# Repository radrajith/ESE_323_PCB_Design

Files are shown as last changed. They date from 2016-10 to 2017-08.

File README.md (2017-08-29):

## Improved Ammeter Design Project Page

***

### Description

ESE 323 is a Modern Circuit Board Design and Prototyping class taught by Prof Westerfeld. During this class, we are designing circuits using eagle cad software and also designing and building 3d models using Autocad. An Improved current meter will be designed and built for the final project. This current meter design is intended to minimize the effects of burden voltage that is present in the multimeters used in the lab and other facilites. 

***

### design and spec

Design drawing(initial version)
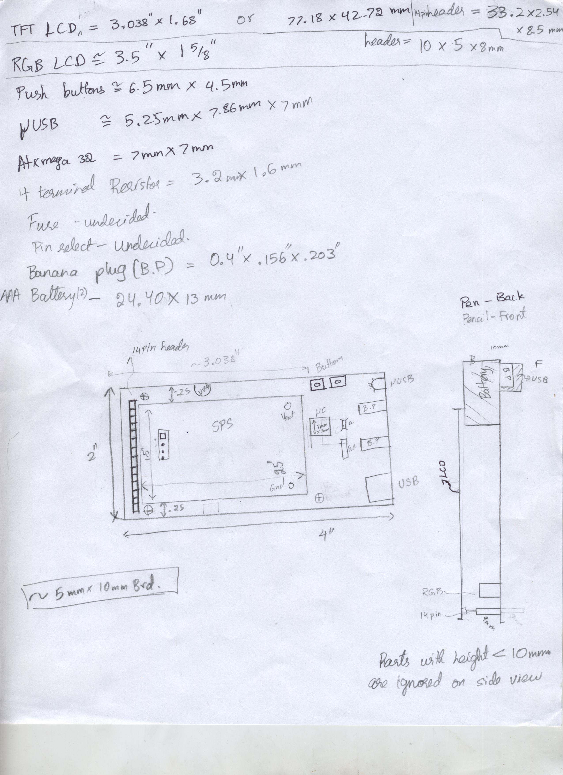
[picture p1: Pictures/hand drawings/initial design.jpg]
Initial design


The current meter will be designed to read up to 7A. The maximum current rating is set to be 8A (the fuse will break at this point) and will only be able to read positive DC currents. The circuit can be powered by a battery with a voltage ranging from 2.5 to 5v, in this design 2-AAA battery is used as a power source i.e 3V source. The Analog current measurement will be sampled at 12kSPS (based on atxmega32 specs), and the digital output will have 12-bit resolution. 

The current is read by measuring the voltage that flows across a shunt resistor. The shunt resistor is specially chosen to have current sense technology, where the resistors packs have 4 terminals, 2 for current flow, and 2 for current measurement. The voltage across the resistor is read using the Atxmega micro controller's built in Analog to digital converter(ADC). 
 
Since the class is about coming with our own design and specs, I decided to add some extra feature to make this project cooler. A LCD touch screen is added to display the current readings such as peak, instantaneous, rms etc. In addition the LCD will be used to graph continuous data assuming I will finish the programming on time. Since the programming had to go through a number of revisions, a PDI communication will be implemented to modify the code as intended. In addition to serving as a normal current meter, A USB port will be added to monitor the current usage of mobile phone or other devices charged using USB. A micro usb port will be used as the input and USB as output. 

***

### Ideal World Scenario

The Atxmega32 comes equipped with amplifier of various ranges like 1/2x, 1x,2x,8x...64x. And since the internal bandgap reference voltage is used, the reference voltage will be a constant 1V. This means by using a 0.01 ohm resistor and using a amplification of 1/2x, the max current that can be read using the meter will be 200A. 

*** 

### Design: Considerations and practical limitations

* **Why 7A current limit?**
The 4 terminal  resistors are available for different power rating for 0.01 ohms. For instance, if 5W rated resistor was implemented the maximum current it can handle would be 22.36A (sqrt(5/0.01)). However, larger current required the trace width of the PCB to be more than 0.4 inch/1cm width. Since the board size use for this design is 5cmx5cm, having a trace width of 1cm will require larger board which adds to the cost. In addition the resistor land pattern is quite small that having a trace causes overlaps. A 4mm/.16in trace is implemented in this design, which corresponds to 7-8A according to graph. 

current vs width
source: https://wiki.xtronics.com/index.php/Wire-Gauge_Ampacity

* **Using 0.5mohm vs 1mohm 4 terminal resistor?**

Although the cost and sizing of both parts remain the same, for this design 0.01 mohm resistor is used. An ammeter ideally has 0 internal resistance, thus for a current meter design its desired to pick a shunt resistor with lowest resistance. However, I had to go with 1mOhm resistor due to the fact that at practical usage, there is resistance contributed from the solder and traces. This will cause error in measurement. In addition, the limitation also arises from the availability of amplifiers in the MCU. With a step voltage of 0.000244, using 0.5 mOhm resistor will reduce the minimum current that can be measured and also accuracy. Thus to have a smaller minimum current, better accuracy and less error a higher valued resistor was implemented.

* **Implementation of two display ports
In addition to a 14 pin header, a 4 pin header is added for i2c communication to provide an alternative display source in case the touch screen display malfunctions and the if the coding cannot be finished on time. 

***

### **Schematic View**

Page one - schematic of the whole circuit with headers, jtag, processor, shunt resistor, fuse, banana plug, usb switches connected and wired according to the requirement.

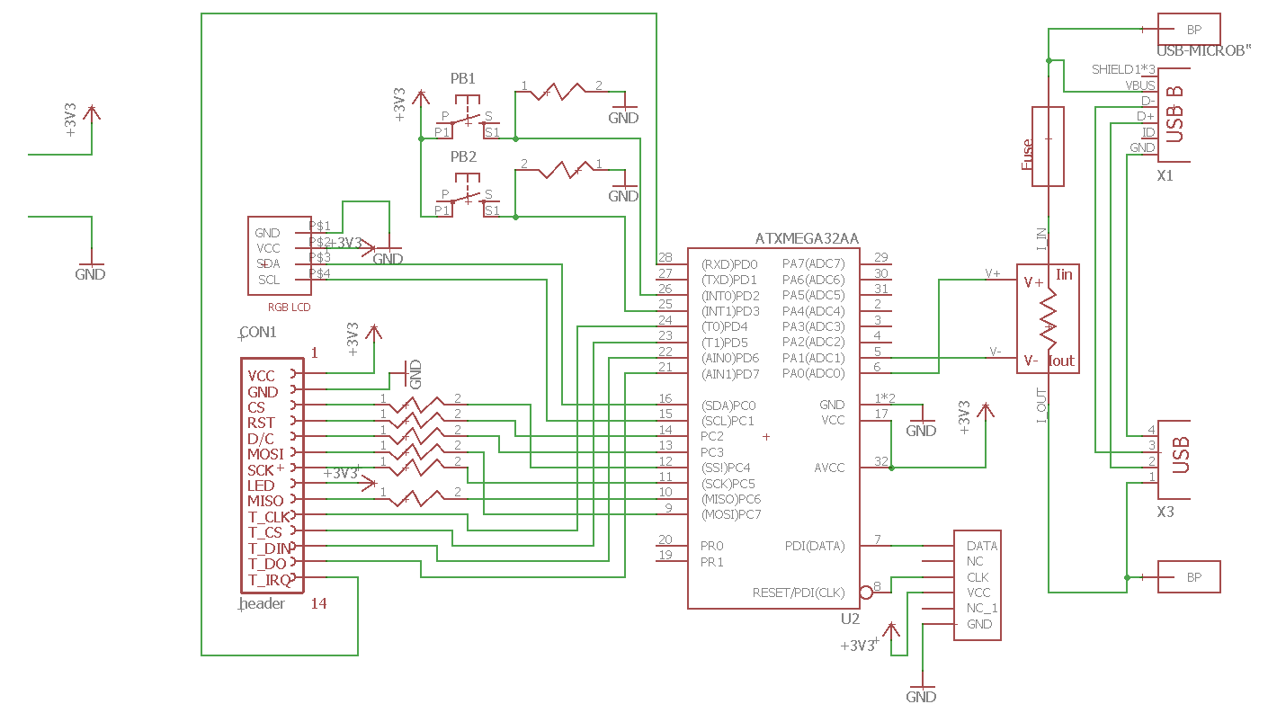
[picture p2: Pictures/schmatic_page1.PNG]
Page one


Page two - Schematic drawing of the switching power supply obtained from texas instruments 

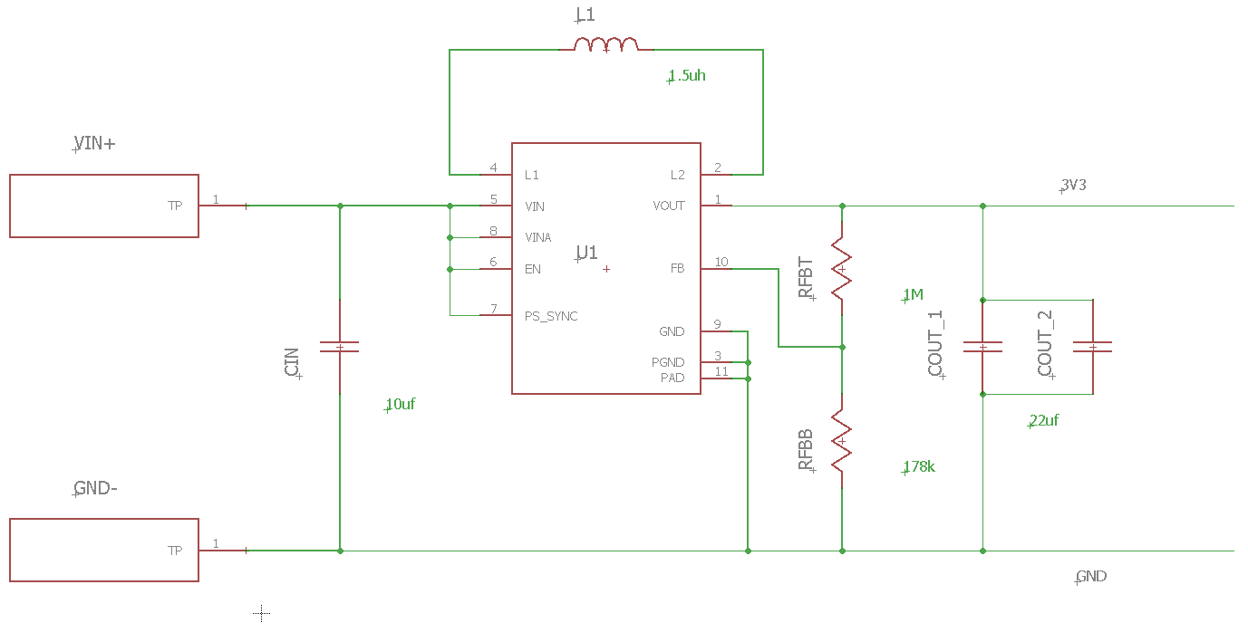
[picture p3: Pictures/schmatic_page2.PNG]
page two


### **Board view**

Board layout
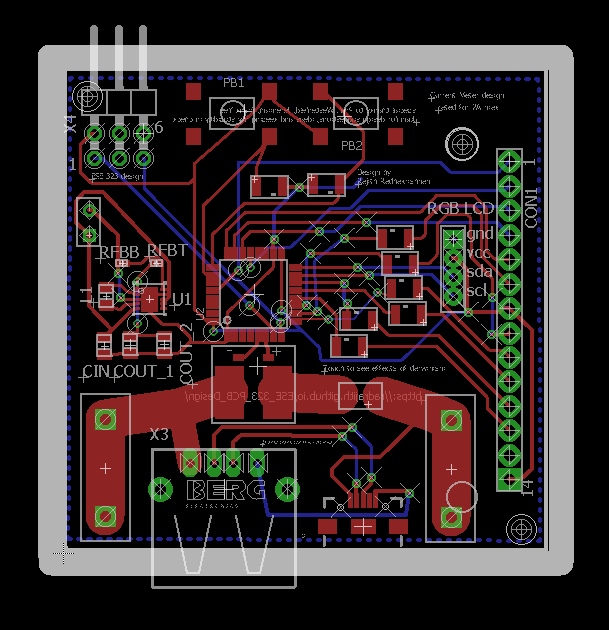
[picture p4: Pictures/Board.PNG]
board


***

### Design rule check and Cam Job

After routing all the parts on the board layout, design rule check had to be used to confirm weather the board meets the requirements. Since Fusion pcb services was planned to be used, the design rule check from seeedstudio was downloaded([DRU link](https://github.com/radrajith/ESE_323_PCB_Design/blob/master/SeeedStudio_2layer_DRU_no_angle_20140221.dru))
After running the design rule check, couple of errors was shown. These errors were mainly becuasue of routing wires or vias close to each other. These errors were fixed and the DRC was repeated until there were no errors. 
 
For the cam job, the cam file provided by the seeedstudio does not include one of the files required by the gerbemerge software, it requires a slight modification. The cam file provided from [seeedstudio website](http://support.seeedstudio.com/knowledgebase/articles/422482-fusion-pcb-order-submission-guidelines) does not generate ".bor" file required for the gerbmerge software. Download the modified cam file from [here](https://github.com/radrajith/ESE_323_PCB_Design/raw/master/Seeed_Gerber_Generater_2-layer.cam). If you choose to modify the cam file provided by seeedstudio by yourself, the instructions are provided after the procedure to create cam files

#### procedure to create cam files

- In order to do the cam process, on the board window click file > cam processor.
- This will open up a window, Click file > open > job

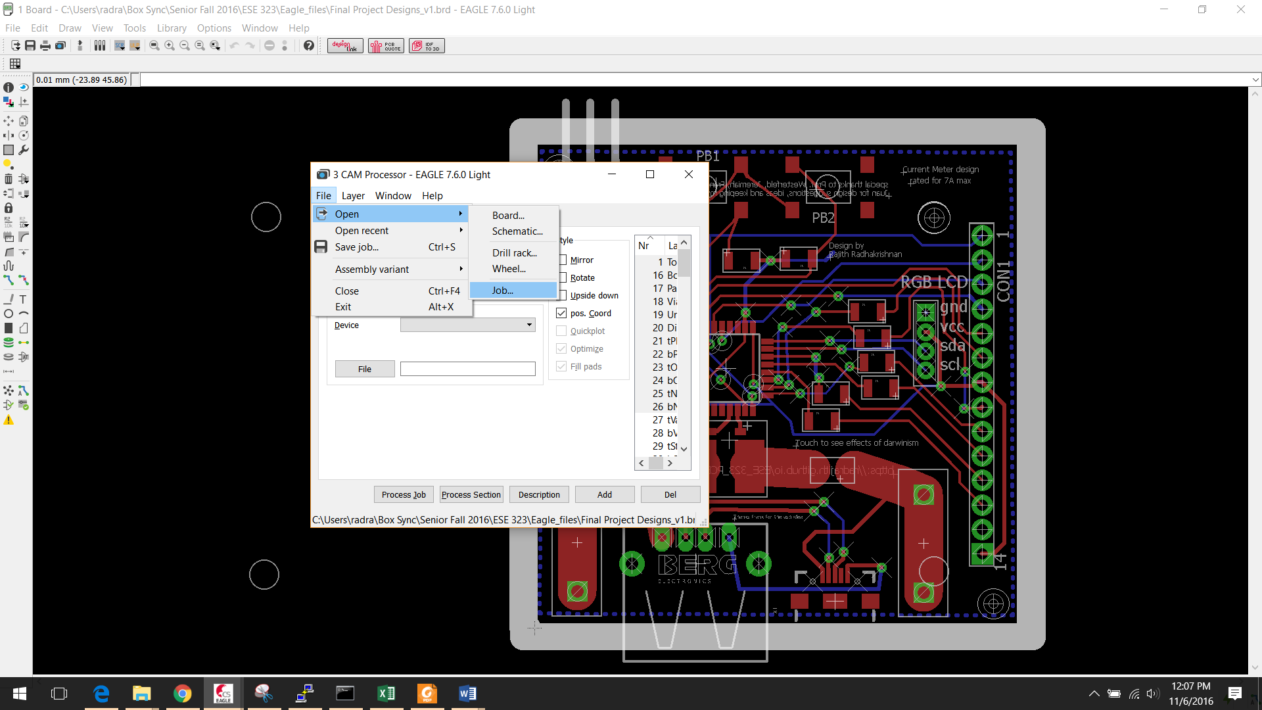
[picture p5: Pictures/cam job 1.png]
cam_1


- Locate you cam file downloaded provided in the above paragraph. 

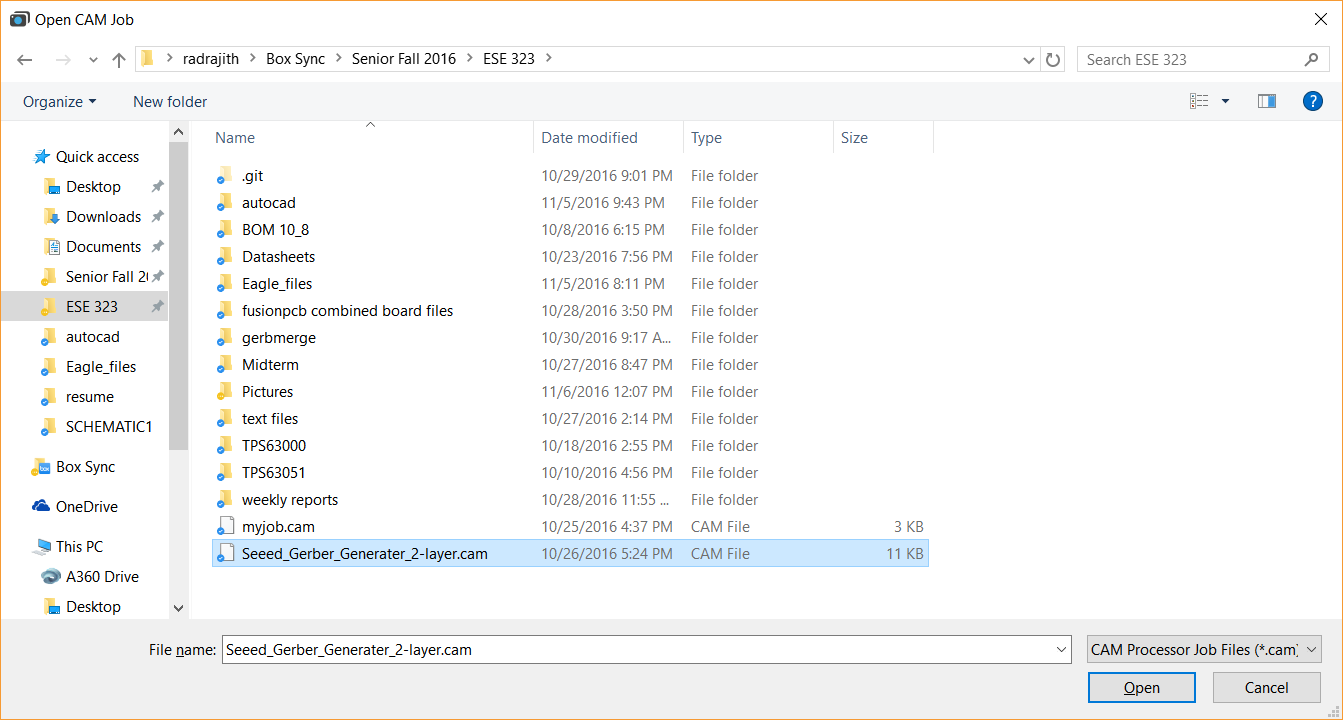
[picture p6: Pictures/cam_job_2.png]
cam_2


- Click process job. This will create all the files necessary to perform gerbmerge operation(described below) or upload to the pcb printing service. 

##### Modify the cam file by yourself(skip this if you used the cam file provided by me)

- After opening the cam processor with the file downloaded from the seeedstudio [link](http://support.seeedstudio.com/knowledgebase/articles/422482-fusion-pcb-order-submission-guidelines), click "add" button

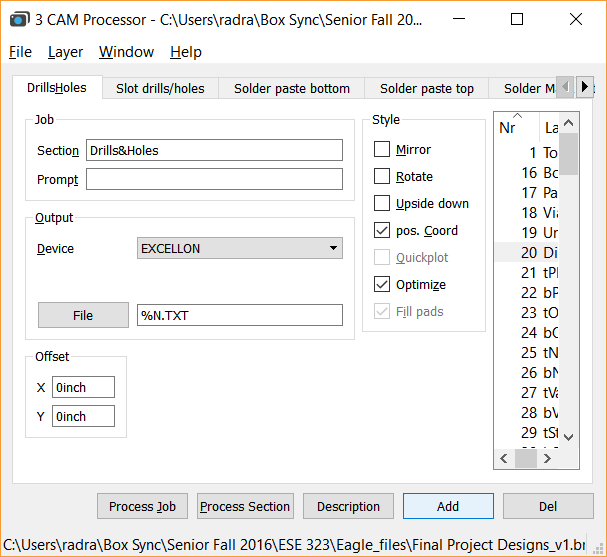
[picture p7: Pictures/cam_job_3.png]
cam_3


this will create a duplicate window of drill&holes. 
- Modify the "Section" from 'drill&holes' to 'board outline'
- Change "device" from 'excellon' to 'GERBER_RS274X' in the dropdown menu
- Change the "file" extension from '.txt' to '.bor'
- On the right side list of layer, make sure only '20 dimension' is selected, scroll all the way to the bottom to make sure. 

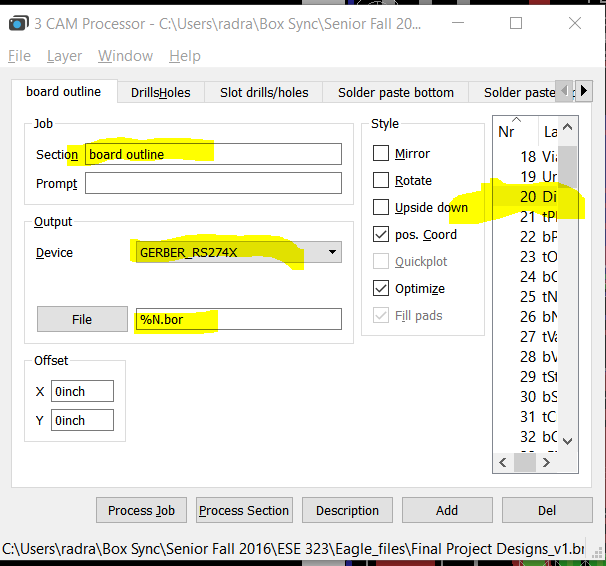
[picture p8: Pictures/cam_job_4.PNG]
cam_4


- Click process job. This will create all the files necessary to perform gerbmerge operation(described below) or upload to the pcb printing service. 

***

### Printed Circuit Board(merged)

With primary goal of reducing the cost, group of 10 students joined and decided to combine the PCBs and place the order. Seeedstudio's PCB printint service was used. The 5 Boards were ordered(minimum quantity), for a 260mmX160mm sized board at the cost of $73.65.  

Front view

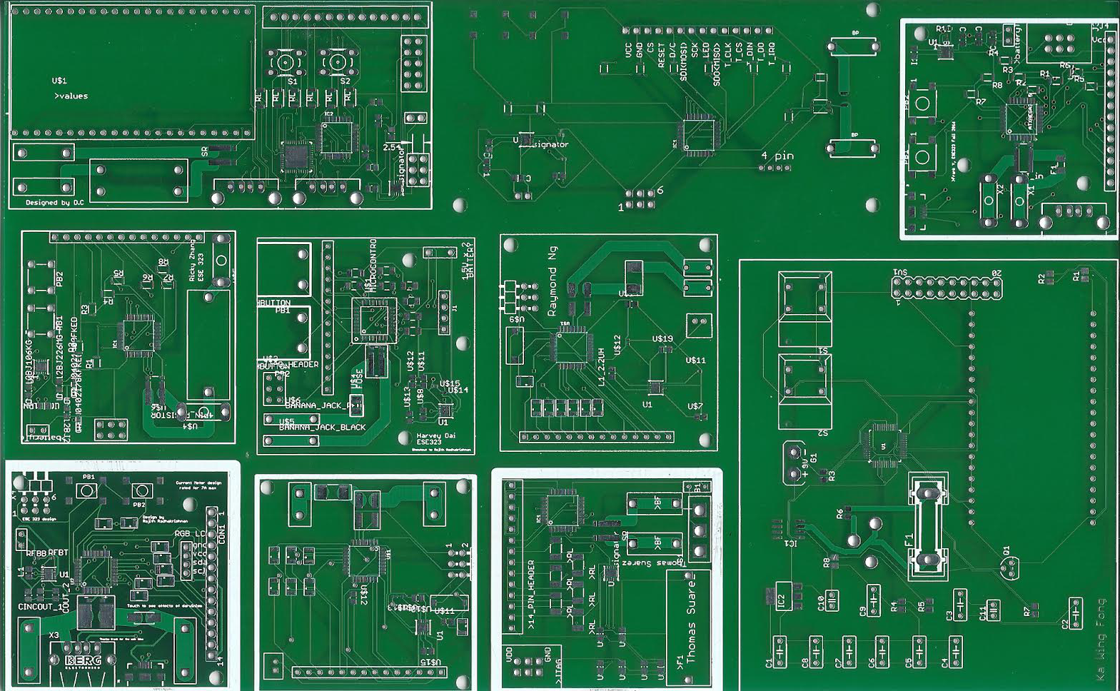
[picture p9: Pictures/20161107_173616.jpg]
front


Rear view
 
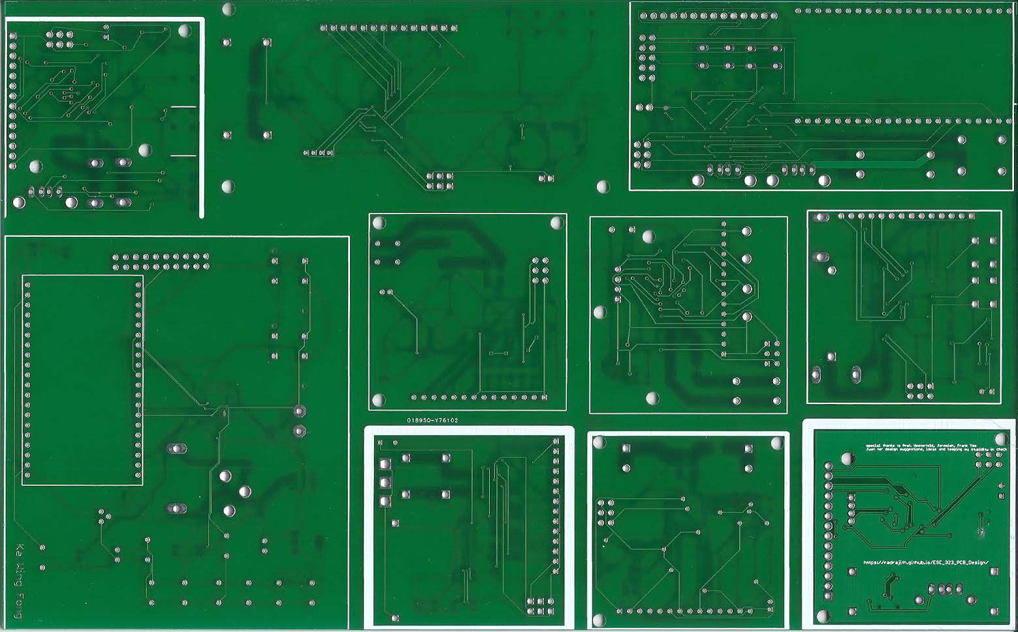
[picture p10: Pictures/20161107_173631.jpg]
back


After obtaining the boards, we carefully analyzed for any errors that were made during the manufacturing process. Luckily all of the board were printed as designed in the eagle.

***

### Gerbmerge

#### **[For information about gerbemerge and tutorial click here](https://radrajith.github.io/gerbmerge/)**

Thank a lot Frank Yee for helping me make the gerbmerge tutorial and actively contributing to it. 

***

### Autodesk Inventor Case design pics 

For the case, there were two designs printed. Althougth the first design fit able to encapsulate the board perfectly, there was some inconveniences when changing the battery and assembling the top cover. [First design pics](https://github.com/radrajith/ESE_323_PCB_Design/blob/gh-pages/initialCAD.md)
The second design was planned to include a slide cover for ease of access to the battery. While programming the LCD screen it was clear that batteries had to be changed often. So accessing battery without disturbing anyother assembly was critical. After designing the first design, it was hard to keep the top case in place, for this reason a door type mechanism was devised and implemented. A stylus slot was added to store when not used, however due to over precision the slot sizing was little small. In addition a hole was added to access Jtag without having to remove the entire board out of the case. Similar to the first design the button press and lever was added to access button present beneath the LCD screen. 

* Circuit Board

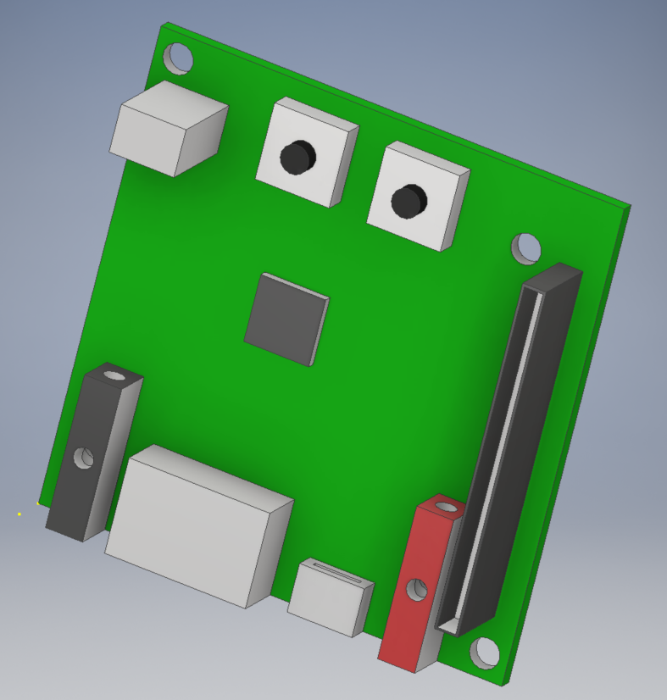
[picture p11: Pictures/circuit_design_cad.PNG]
circuit Design


* Top case

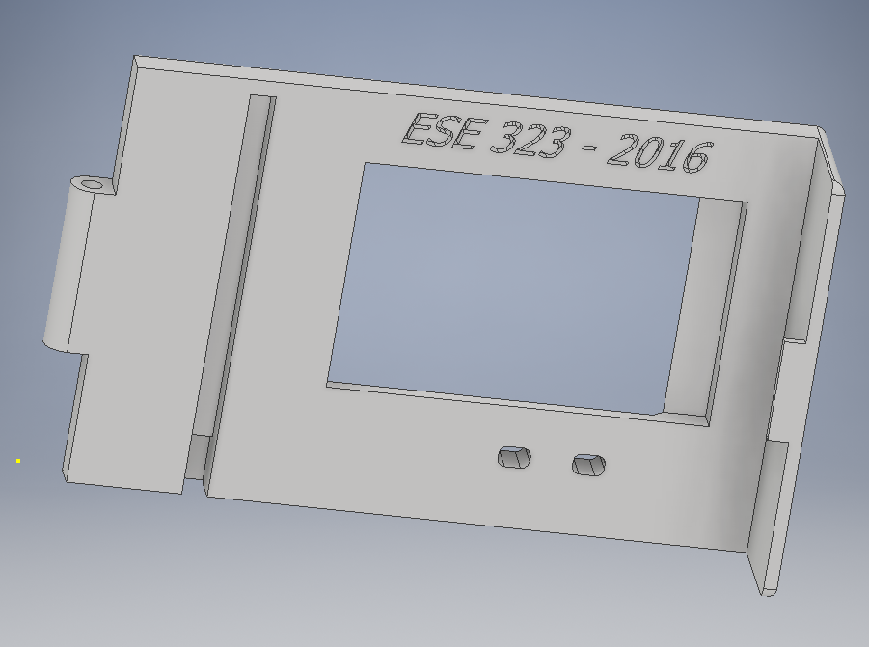
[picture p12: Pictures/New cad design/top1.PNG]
top case1

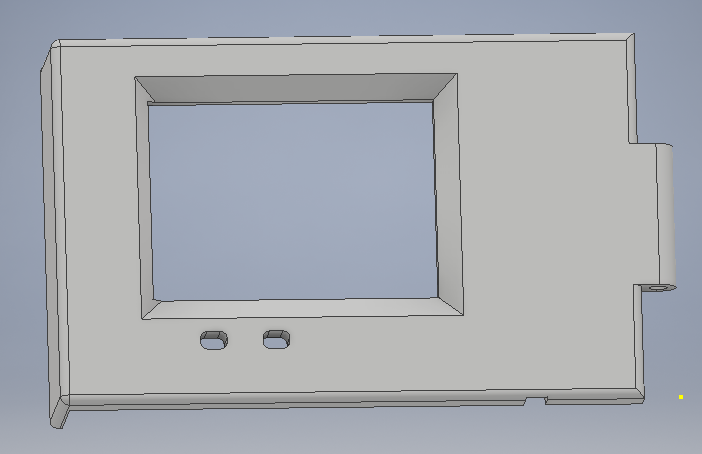
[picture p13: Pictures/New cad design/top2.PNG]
top case2


* Bottom case

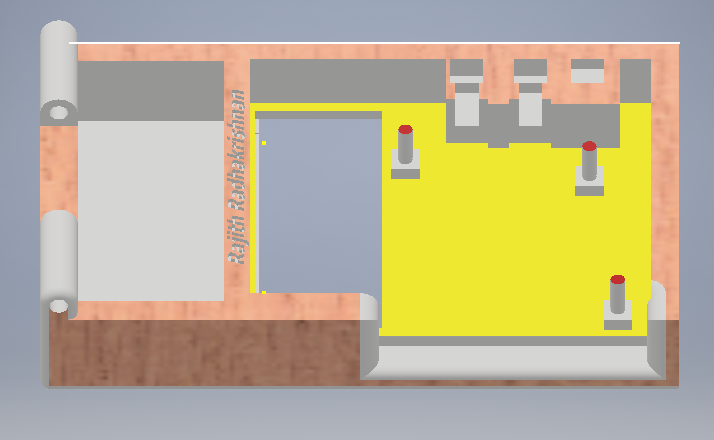
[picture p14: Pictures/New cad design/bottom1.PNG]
bottom case1

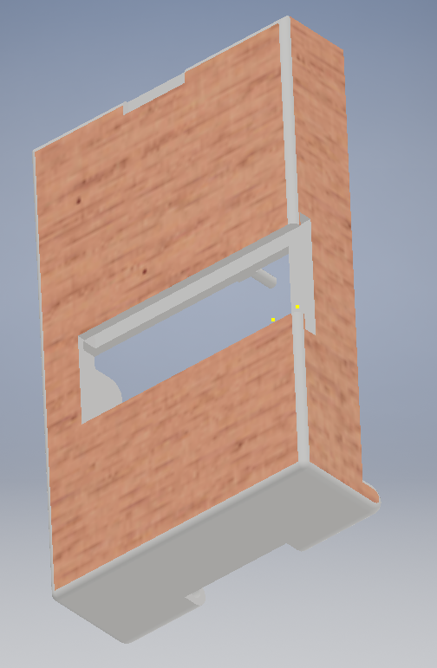
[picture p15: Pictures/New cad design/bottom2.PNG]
bottom case2


* Button press extension

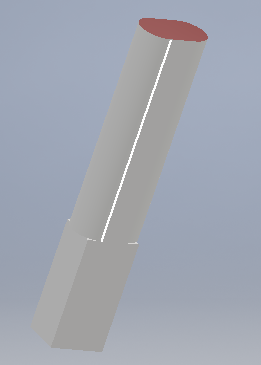
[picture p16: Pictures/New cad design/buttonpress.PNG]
button press


* Button press lever

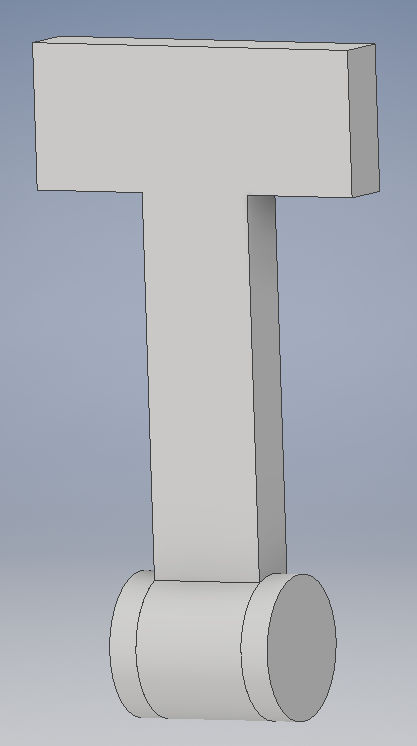
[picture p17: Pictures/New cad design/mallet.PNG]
lever


* battery cover

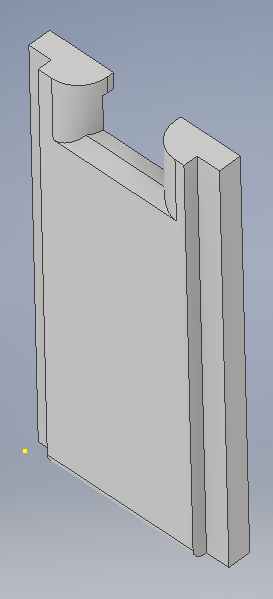
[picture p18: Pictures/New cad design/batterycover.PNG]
battery cover


* Assembled parts view. 

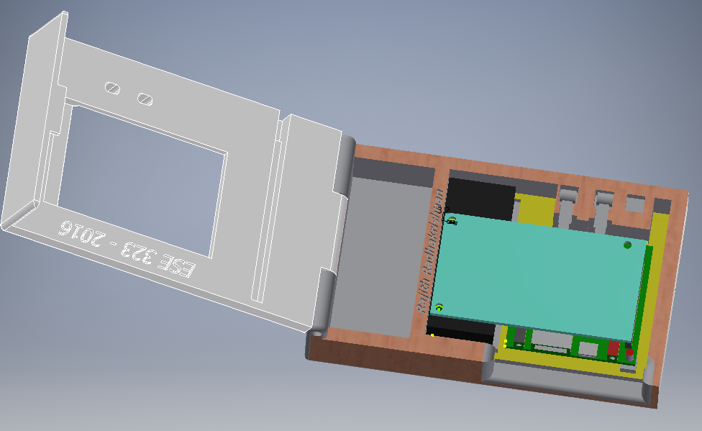
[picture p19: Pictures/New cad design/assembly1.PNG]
Assembly1

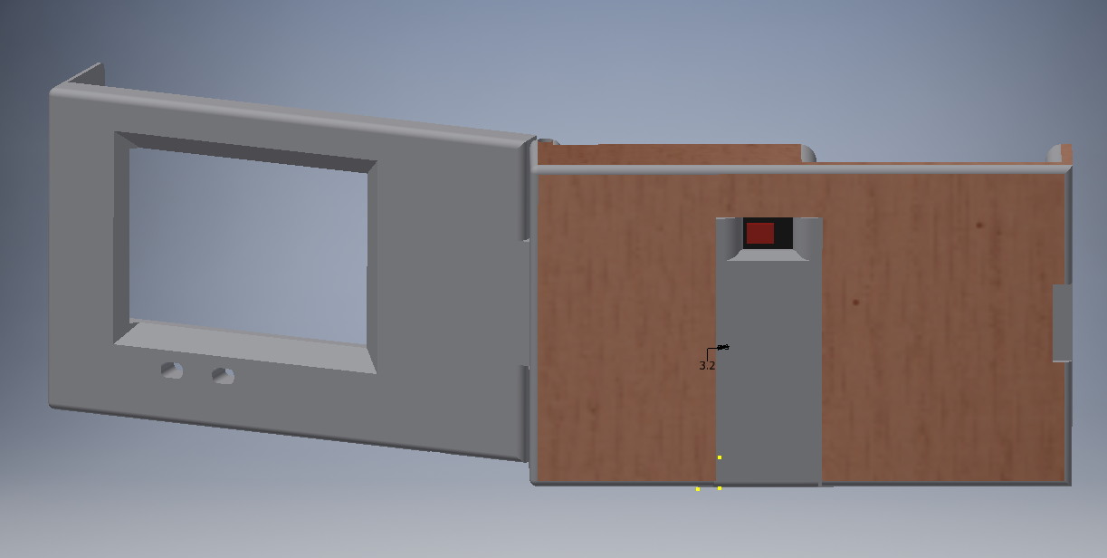
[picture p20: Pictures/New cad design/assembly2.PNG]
Assembly2


***

### 10 minute video of PCB baking in the oven

To watch the solder melting and skip funny conversation, start at 3.25

[Oven Video](https://goo.gl/photos/HqDbT51zgB6RFGLk8)

***

### finished product

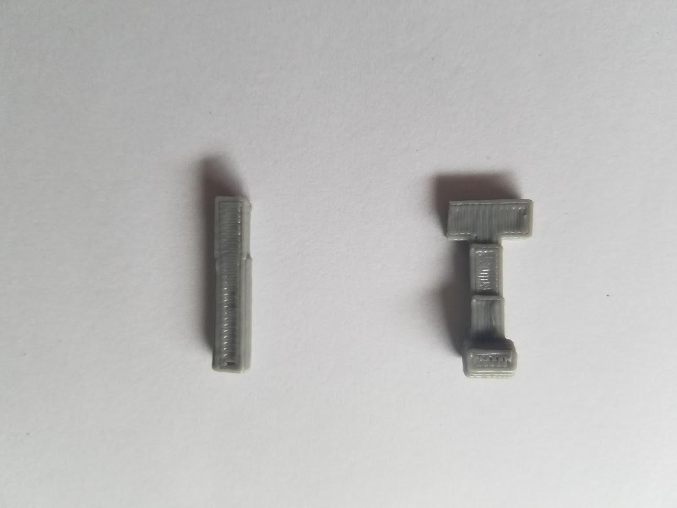
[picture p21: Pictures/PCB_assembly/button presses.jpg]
buttonpresses

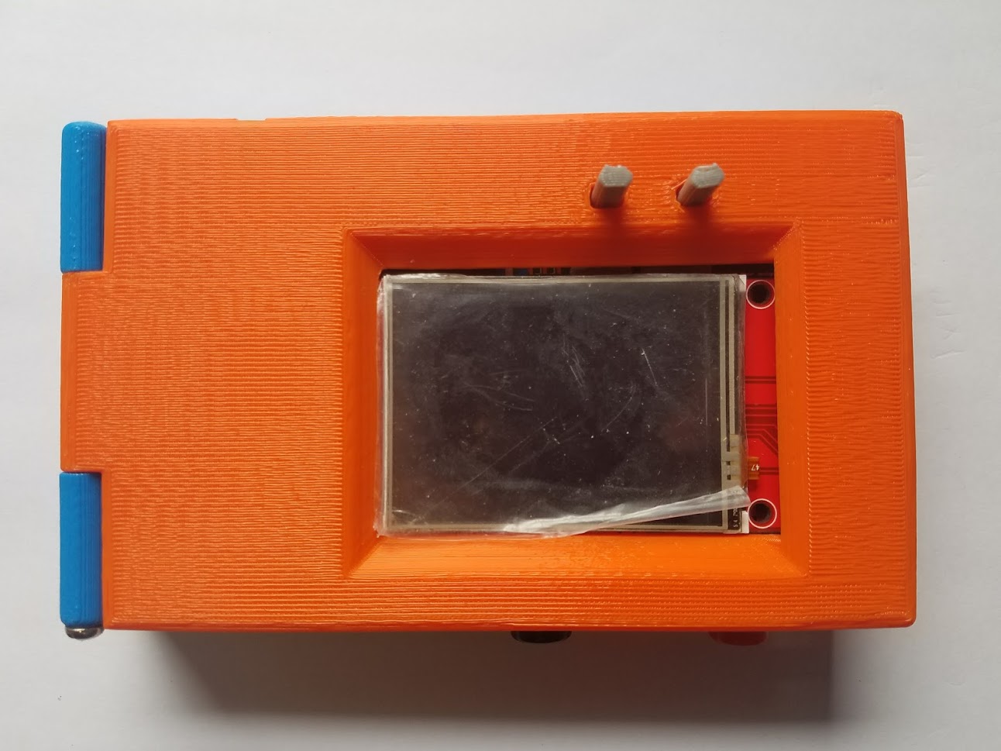
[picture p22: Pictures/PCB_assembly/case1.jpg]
case1

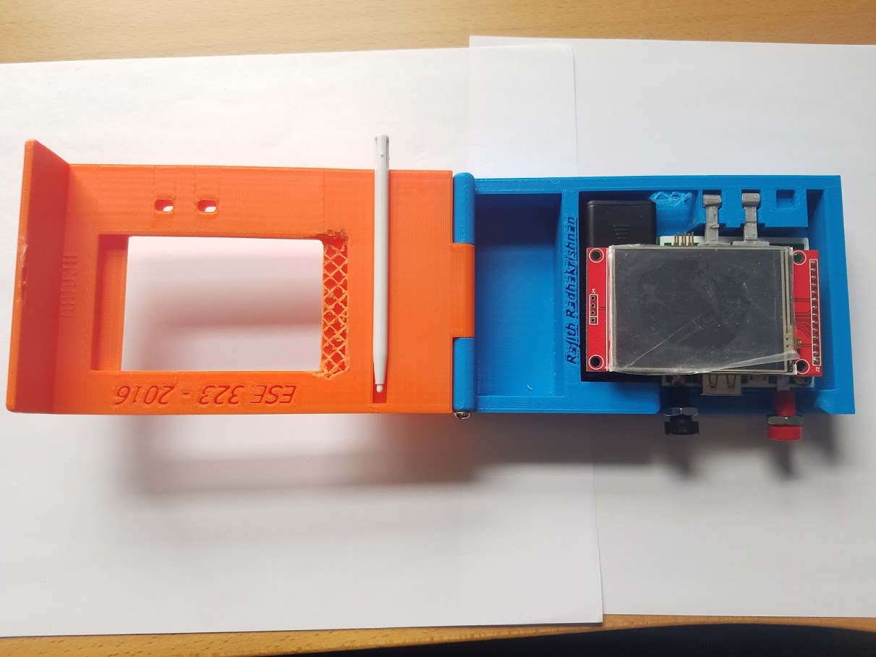
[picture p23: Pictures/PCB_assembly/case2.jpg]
case2

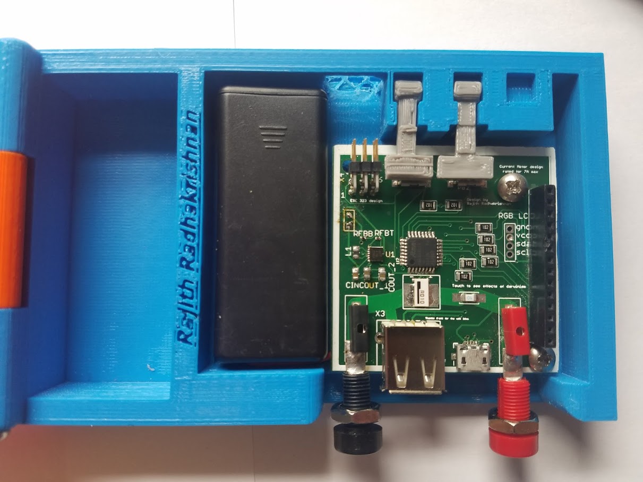
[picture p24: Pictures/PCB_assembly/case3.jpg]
case3

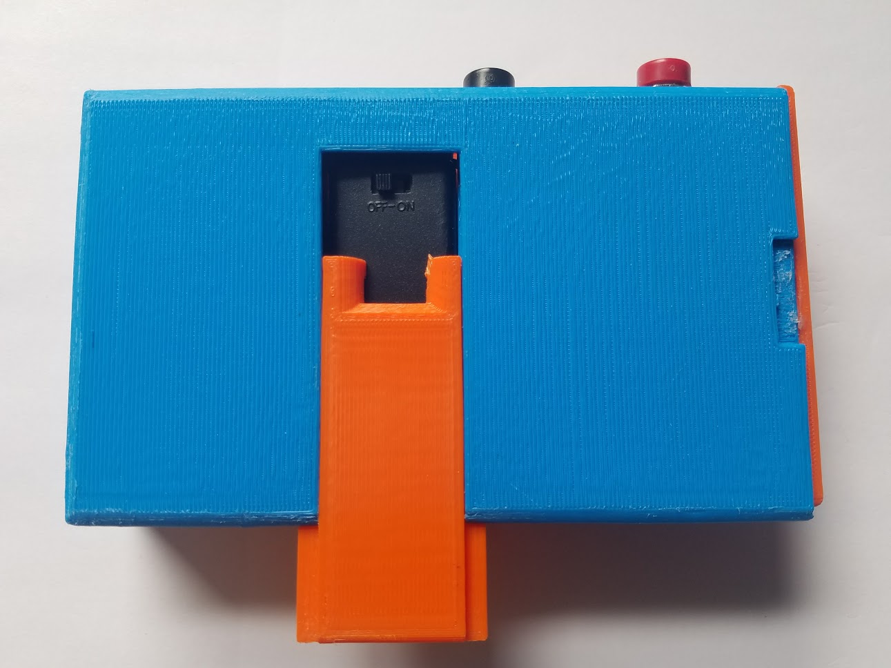
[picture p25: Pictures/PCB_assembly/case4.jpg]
case4

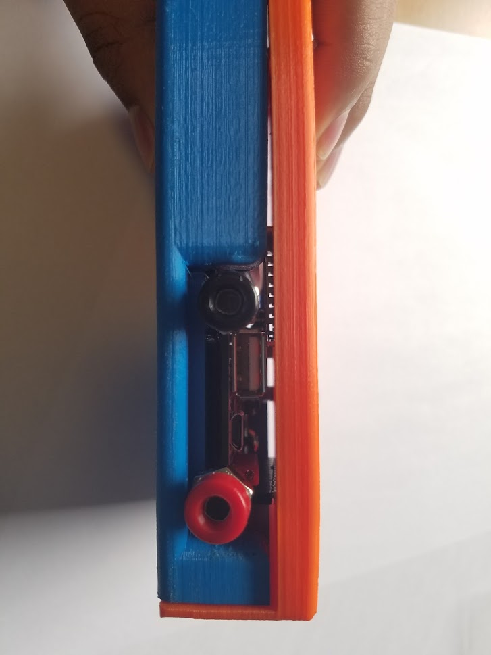
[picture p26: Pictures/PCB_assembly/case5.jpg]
case5

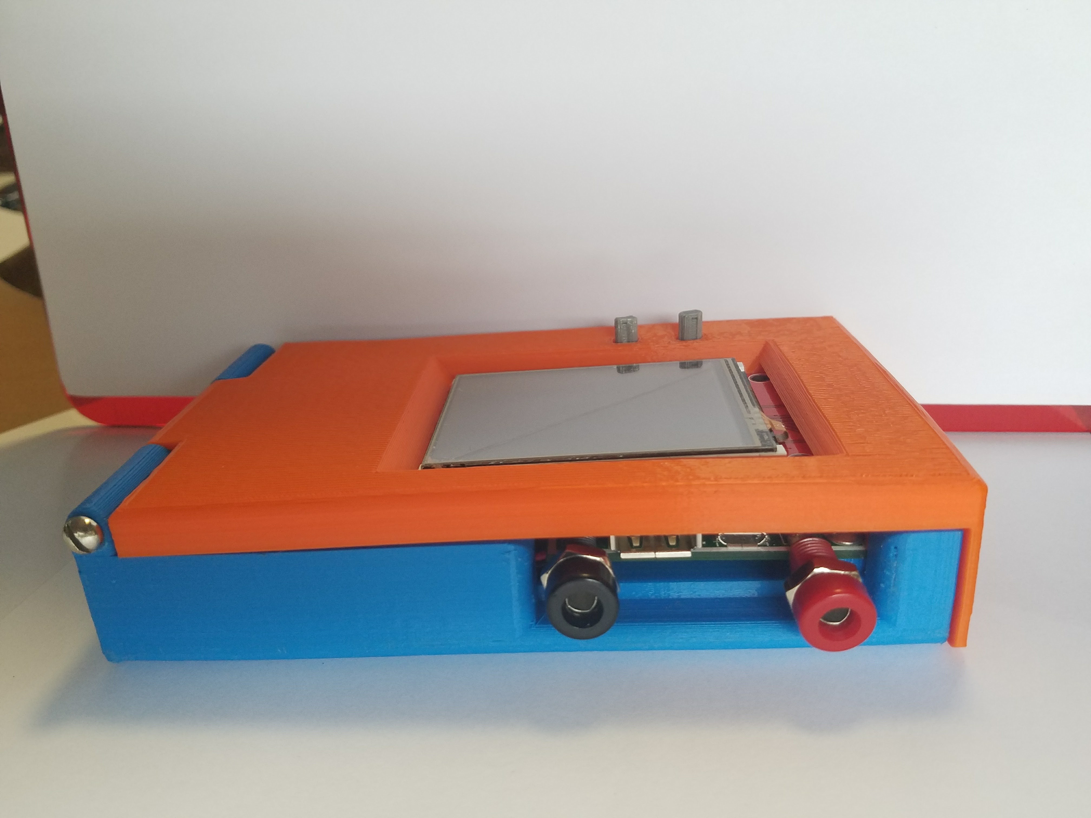
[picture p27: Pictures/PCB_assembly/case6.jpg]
case6

working

***

### Problems faced and how it was solved

#### TPS63000 switching power supply assembly

The switching power supply package is 3mmx3mm. Since the schematic and the board layout were obtained from texas instruments(webbench), the true size of the pads and the package were not realized until we saw the pcb. Soldering this package was causing the major problem. Since the solder paste used was coarse, the solder paste did not flow thorough the thinnest needles. Multiple approaches were tried and we finally figured out the best way to solder this package.

As seen in the picture below, although the pins look like they are making contact with pad, in reality they were not connecting. This flaw was figured out thanks to the amazing camera and zoom capabilities of the Samsung galaxy S7(the model without the automatical combustion feature). The microscope present in the lab was not able to provide a clear picture. 

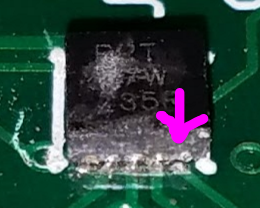
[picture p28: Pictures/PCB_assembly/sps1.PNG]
sps1

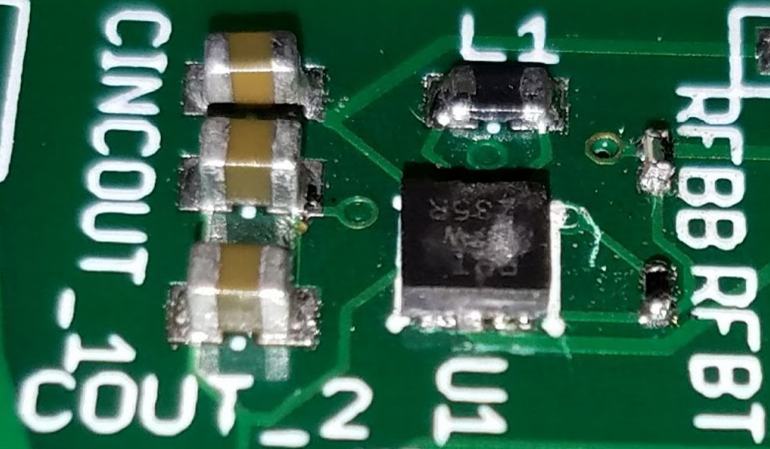
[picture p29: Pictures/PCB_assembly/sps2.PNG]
sps2


* Approach one 
   laying a bead of solder on the pads and hoping the solder mask will repel and prevent bridging. This approach almost never worked.
   
* Approach two

   placing a line of solder on a paper towel, making a knife like stucture using paper and placing the exact amount on the pads. This process was highly time consuming and required patience and skills. [Credits - method invented by Harvey and Ricky]
   
* Approach three (success 100%)
   Instead of relying on the reflow oven to melt the solder paste and make connections, the hot air gun was utilized. Intially the center pad of the SPS was soldered on either using the heatgun or reflow oven(center pad marked in pic 1 below using magenta pen). Once the SPS is correctly placed and firmly secured at the center pad. A bead of solder had to applied on the pins(pic 2). Take a napkin and wipe the SPS all around. Since the package is very small, when the excess is cleaned, a line of solder paste is left handing in the corner(pic 3). Setting the hot air gun to 300 degrees, the hot air was direcly blown on top of the SPS until the solder paste turned shiny(5-10s). Pic 4 shows the clean connection joints made, a amazing zoom skills of Samsung S7. 
   
   Pic 1
   
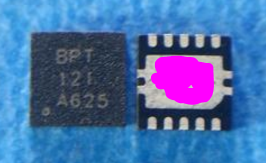
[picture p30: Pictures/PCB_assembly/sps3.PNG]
sps3
   
   
   Pic 2
   
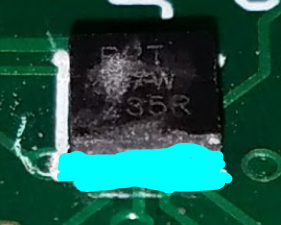
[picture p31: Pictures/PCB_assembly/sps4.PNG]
sps4
   
    
    Pic 3
   
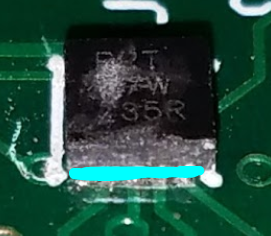
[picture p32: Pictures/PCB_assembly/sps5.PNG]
sps5
   
    
    Pic 4
   
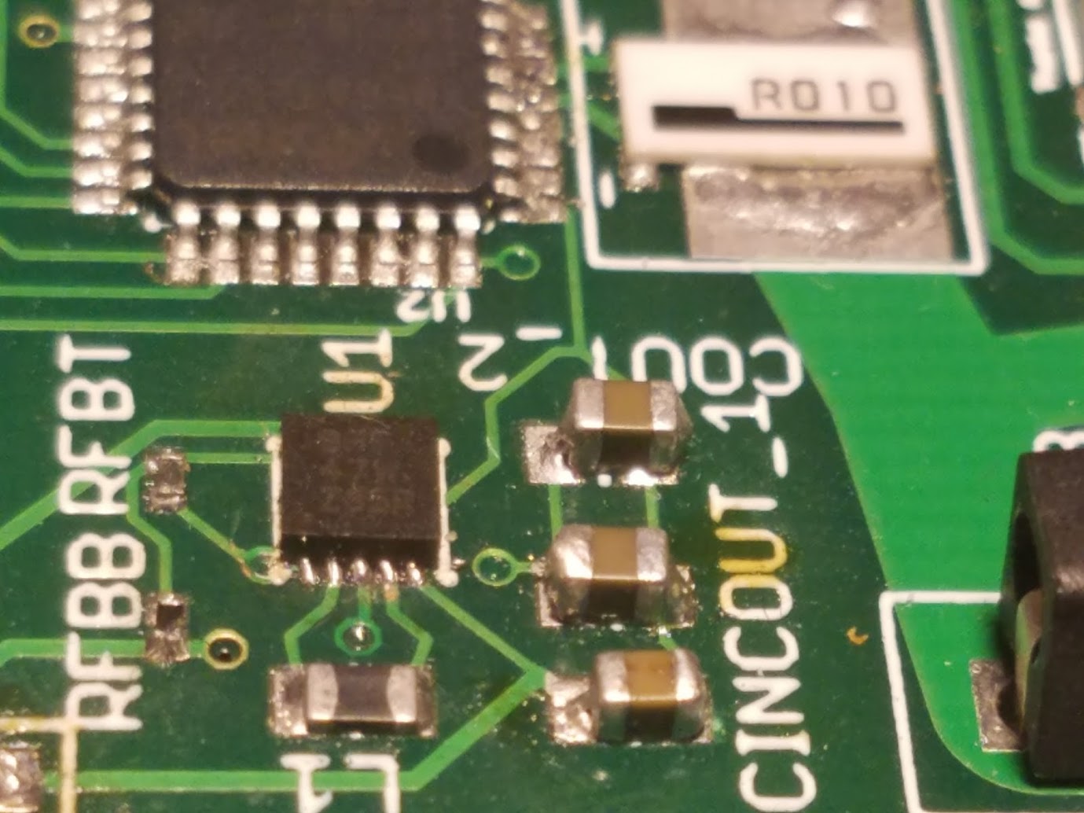
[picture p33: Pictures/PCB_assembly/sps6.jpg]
sps6
   

#### problem in schematic design

when designing the schematic i had two pages. One containing the sps and other containing the rest. When naming the net for vout of the SPS, i named it +3v3 on one page and 3v3 on the other. When reading the net name in page 2, i misread the + that is used to indicate the location, and name the vcc in page 1 as +3v3. This means there was no connecting present in the board. 
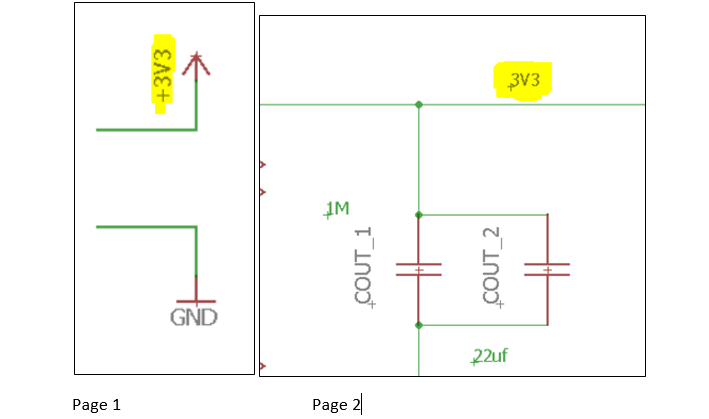
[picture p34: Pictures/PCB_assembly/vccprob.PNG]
vccprob

This problem was intially fixed by connecting a wire between Cout and the vcc of the jtag. 
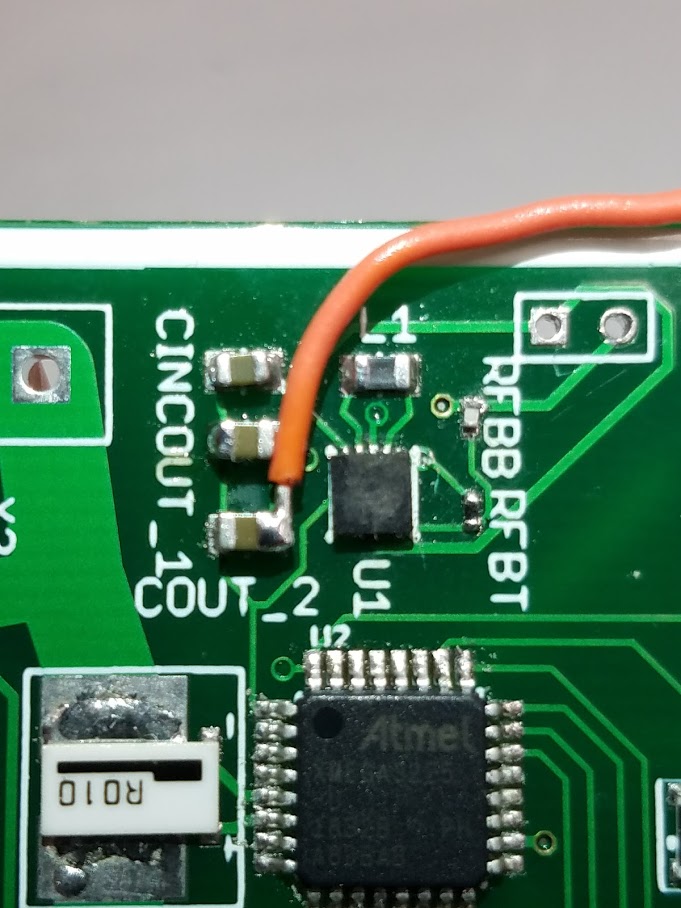
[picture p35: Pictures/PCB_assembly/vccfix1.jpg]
vccfix1


However this fix made the front of my board look ugly. For this reason, i found a via that was coming out on back, and scratched the solder mask off and the metal of the via to make a connection on the back. 
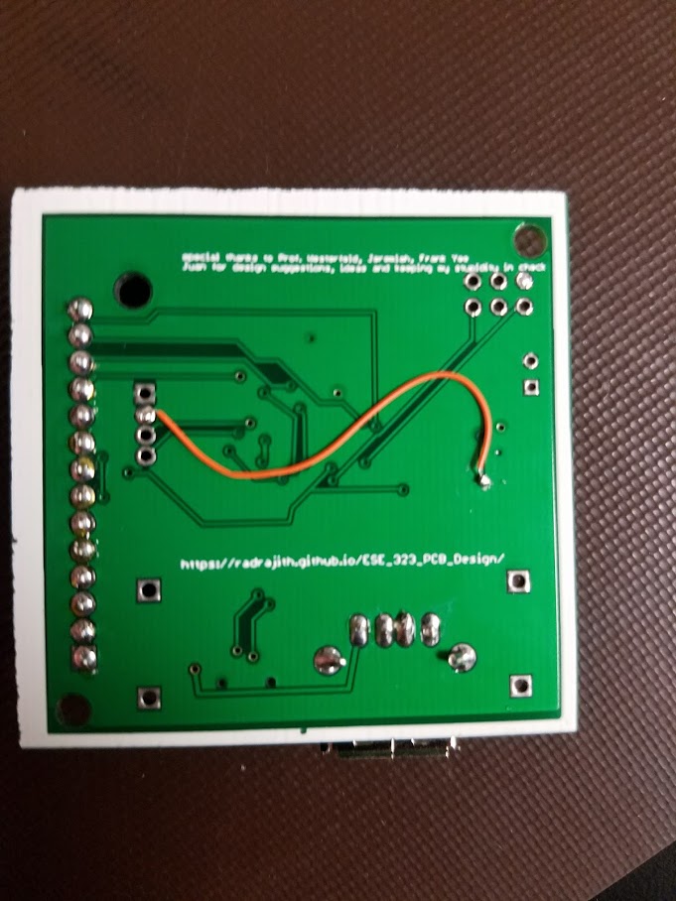
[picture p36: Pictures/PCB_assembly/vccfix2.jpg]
vccfix2


#### Pushbutton placed underneath the LCD

With the ultimate goal of bringing down the cost, the PCB was designed with the least size (5mmx5mm), thus pushbutton had to be buried underneath the lcd screen. To access the pushbutton the lever type mechanism was implemented in the case design (refer to the button lever picture under the autocad inventor design pics). The foced applied on the button press is transferred to the lever and presses the button. 

#### Quakko disaster 
While programming the microprocessor, due to the lcd backlight requiring a lot of current, the battery was draining really quickly. To substitute the battery for a constant voltage source, Quakko power supply was used to supply the voltage. The switching power supply when turned on spiked to large voltage causing the SPS to instantly smoke. Due to this disaster, an additional 10 dollars was added to the BOM to obtain the extra SPS. 

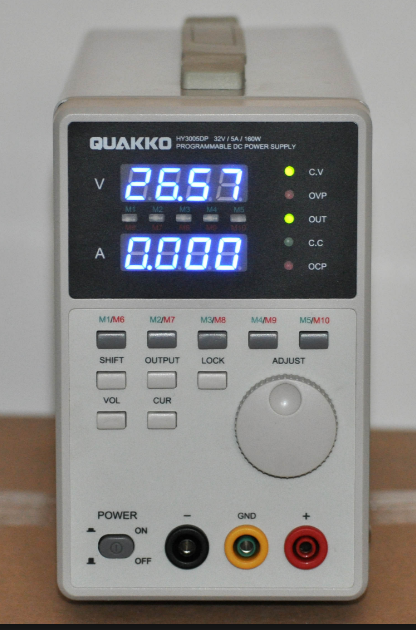
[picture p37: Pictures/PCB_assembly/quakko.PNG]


***

### Gain Calculations

Highlighted areas indicate the ADC readings. The gain will decrease as the voltage reading goes over 0.96V. 

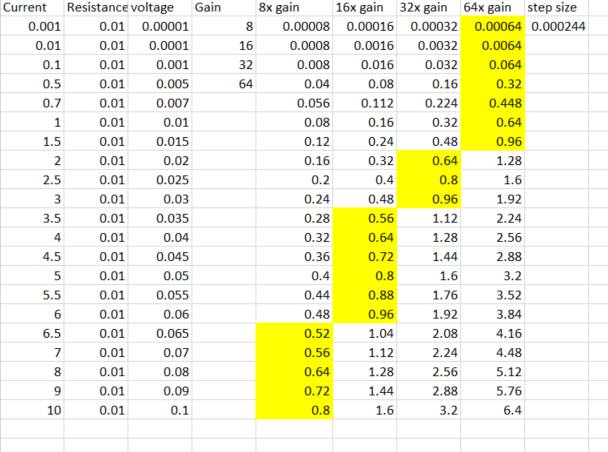
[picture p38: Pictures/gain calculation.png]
gain


***

### Coding

Although major coding is yet to be done, the welcome screen code is currently running on the board. In coming days the touch screen functionality will be implemented along with push button functionality. The ADC code is almost complete, with minor fixes the current meter reading can be done. Ideas for a snake game is partially coded. 
The coding that has been done so far has been included below
[Code](https://github.com/radrajith/ATXMEGA_ILI9341_RGBLCD/tree/master/LCD_ILI9341_ESE_323)

Problems faced and coding experience details will be added in the coming days.

***

### Parts, pinouts, BOM

The detailed picture of the parts used has been seperated into a different page along with the BOM. 
[Parts, pinouts, BOM](https://github.com/radrajith/ESE_323_PCB_Design/blob/gh-pages/partsDetail.md)

Since the order of the 10 people were combined, the link to the Super BOM is also attached below.
[Super BOM](https://docs.google.com/spreadsheets/d/1yWEKycQpd-gtfOP6fBI8lNDqo7oUvL_eeN0UET3jQ1g/edit?usp=sharing)

Once again, credits to Frank Yee for putting together and combining the BOM and also managing the finances.

***

### Cost spent 

* PCB Board

size - 160mmx260mm 

quantity - 5

Cost - $59.92

Shipping - $19.72

Discount - -$5.99

Total  - $73.65

* Digikey order 

66 parts

Cost - $129.87

Shipping - $13.50

Tax - $12.37

Total - $155.74

* Texas Instruments order

TPS63000

Quantity - 10 

Cost - $1.91

Total - $19.10

* Total Money spent 

| Rajith  | 48  |

| Harvey  | 35  |

| Frank   | 31  |

| Thomas  | 32  |

| Ka Wing | 49  |

| Raymond | 29  |

| Jerry   | 27  |

| Daniel  | 40  |

| Juan    | 22  |

| Ricky   | 28  |

|   **total**      | 341 |

overall the total cost of the whole project was $48. If some precautionary measure were taken to avoid the quakko disaster, the cost can be reduced $38. If Easyeda pcb printing service was used, the cost could have been reduced further to $34. 

***

### Course improvement suggestions

* Finer solder paste to be used with the thinnest needle. 
* Encouraging to form groups to bring down the cost of the project
* Deadlines to force student to finish the board designs on time. 
* Warn the students about the package sizing, but dont ban the usage of tiny and impossible package. Lets student make mistakes and force them to come up with good solutions. 
* Good microscope or Samsung galaxy S7 phone available in the lab to obtain a magnified view of the connection in the PCB

***

### Contact
radrajith@gmail.com (2016)

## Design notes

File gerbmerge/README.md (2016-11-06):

# Gerbmerge
A detailed explanation of how I used gerbmerge to combine multiple eagle boards for [fusionpcb](https://www.seeedstudio.com/fusion_pcb.html) manufacturing.

Softare Notes: 
* [Eagle7.6](https://cadsoft.io/) - CAM file format(s) 
	* Gerber_RS274X  
	* Excellion for drill holes
* [Python](https://www.python.org/downloads/)
	* Python 2.4 or higher
	* **Not Python 3, it is incompatible with gerbmerge**
* [SimpleParse](http://simpleparse.sourceforge.net/)
	* version 2.1.0 or later	

I used gerbmerge as a way to bring down the cost of ordering pcb for a group of friends while taking ESE 323 - Modern prototying and PCB design class at Stony Brook University. 

*The gerbmerge code is written by ruggedcircuits.com. I am creating this to give a detailed tutorial on how to use it, and not go through the same process of looking all over internet.*

#What is Gerbmerge?
Gerbmerge is software written in python that will combine multiple gerber files into one super board. Gerbmerge offers both manual and automatic (optimization algorithms) as means of board placement.

For this project, the automatic operation was used.

#Why Gerbmerge?
Because eagle cad design software has a limitation of 100x80mm routing area (express) or 160x100mm routing area(edu) , multiple boards cannot be combined together without requiring to upgrade a paid version. To work around this limitation, we can combine the gerber files generated from the eagle instead. By combining the gerber files, we also avoid the problems caused by the panelizing script which redefines all the components to different names. (We combined boards of 10 people and checking each person's board for name conflict is an annoying and time consuming task).

# Downloading Python And Simpleparse
Since gerbmerge is written in python, If you don't have python already installed, download it. At the time of this tutorial I was using python version 2.7
[python download link](https://www.python.org/downloads/)

>SimpleParse is a BSD-licensed Python package providing a simple and fast parser generator using a modified version of the mxTextTools >text-tagging engine.

[SimpleParse download link](http://simpleparse.sourceforge.net/)

#Downloading and Installing Gerbmerge
After installing python, go ahead and download gerbmerge file [zip file link](https://github.com/radrajith/gerbmerge/blob/master/gerbmerge-master.zip)

Or if you directly want to get it from the source I forked it from [click here](https://github.com/unwireddevices/gerbmerge).

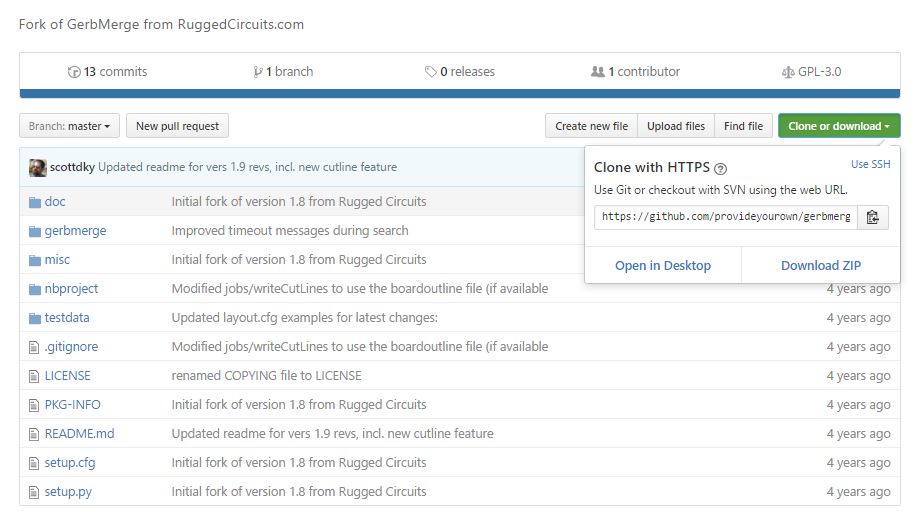
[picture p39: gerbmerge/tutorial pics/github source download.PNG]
github download


The instruction on unwireddevices github page are pretty good, follow that to install it. If you are not comfortable with it, use the picture guided instruction to install gerbmerge on your computer. 
 
Once the file is downloaded unzip it. 

Go to where the folder containing unzipped files (in this case the downloads folder). Run command prompt by going to the address bar and typing ```cmd``` .
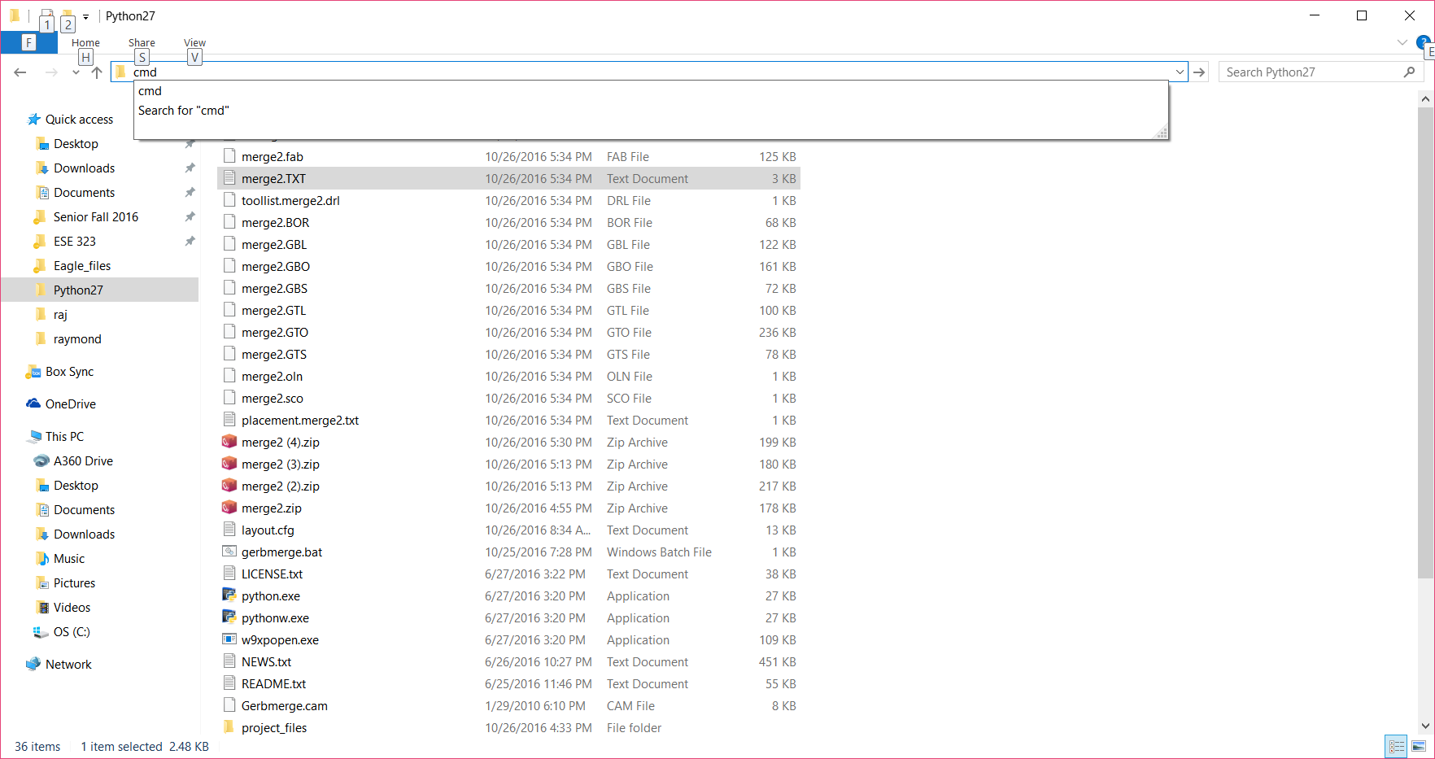
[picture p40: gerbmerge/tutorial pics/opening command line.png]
openning command prompt


The command line window will open up. 
Typing ```python setup.py install```, will install gerbmerge software on your computer. 
						
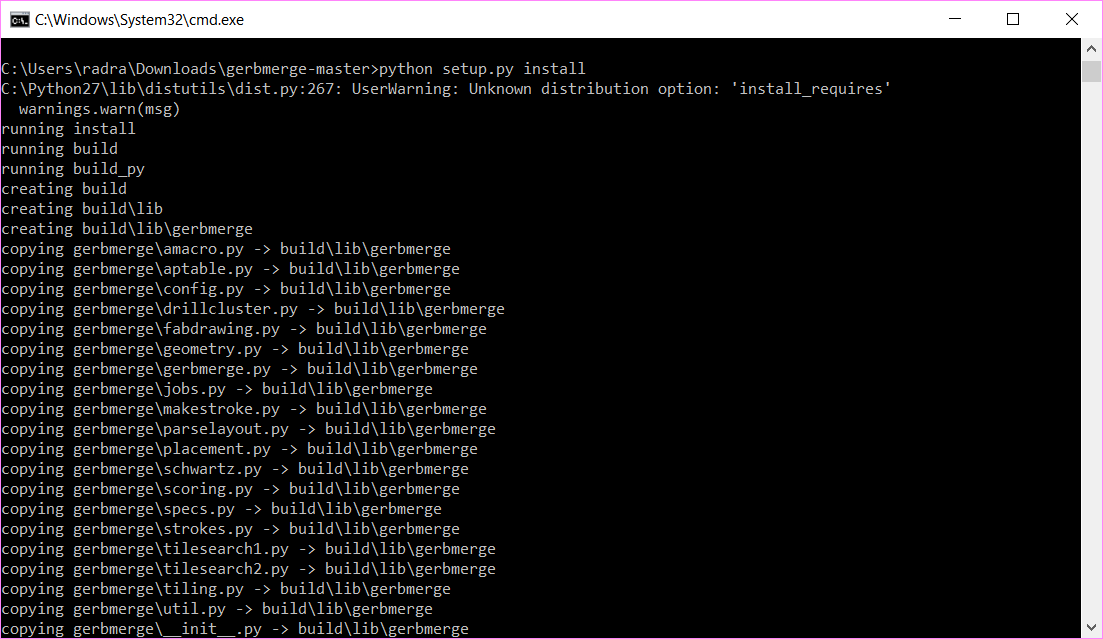
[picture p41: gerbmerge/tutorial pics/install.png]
installing gerbmerge


You can check if gerbmerge was installed correctly by going to "python2.7>Lib>site-packages" (see gerbmerge folder). 

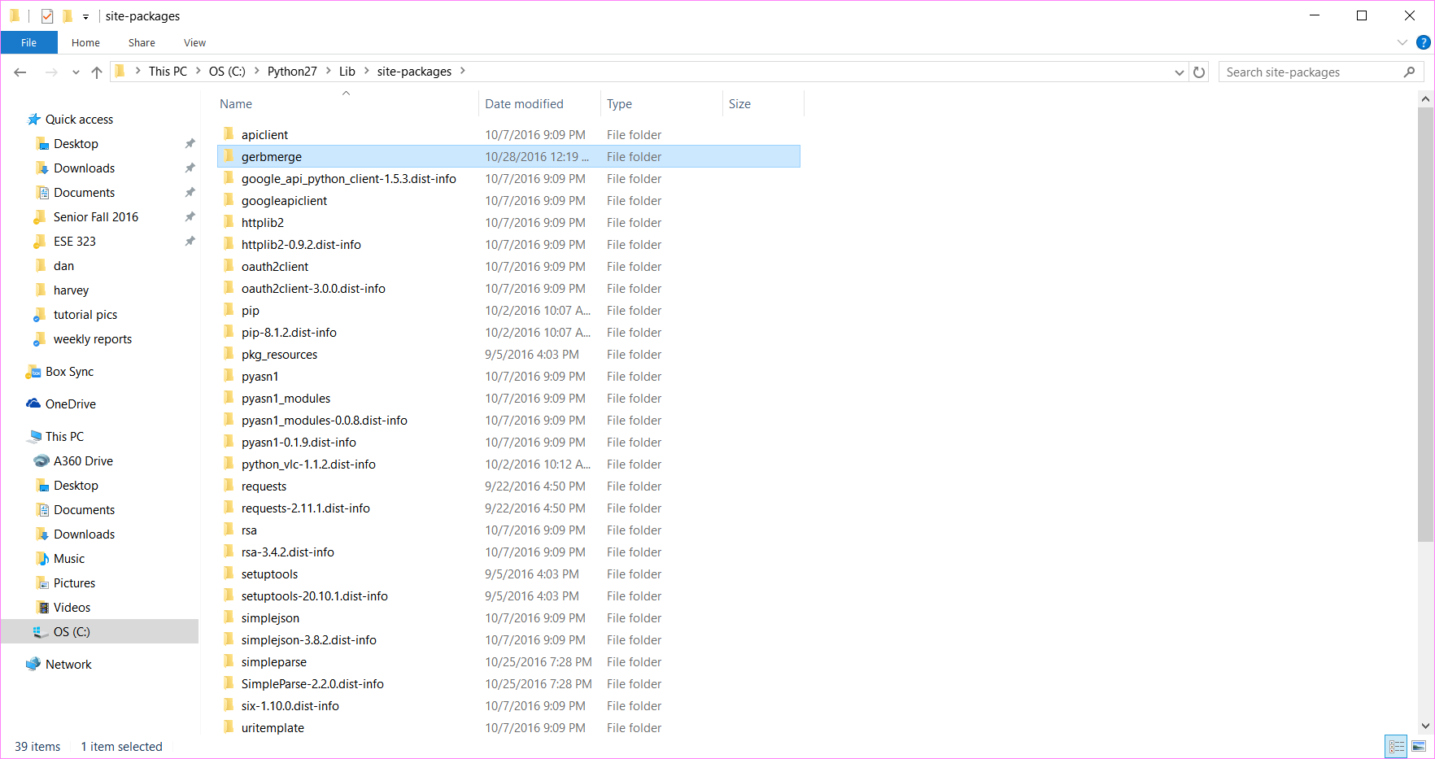
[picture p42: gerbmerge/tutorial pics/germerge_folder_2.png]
gerbmerge folder 2


#Combining Gerber Files 

If you have not created the gerber files already, [refer here](https://radrajith.github.io/ESE_323_PCB_Design/) for the instructions to obtain the gerber files from eagle. 
**Confirm that the drills file extensions are saved as .txt not .drd**

##Creating Directory for Files to be Combined
To avoid problems with python not being able to find directory, all the files will be placed in the python2.7 directory. Follow the steps below
 
* Create a new directory called ```project_files```
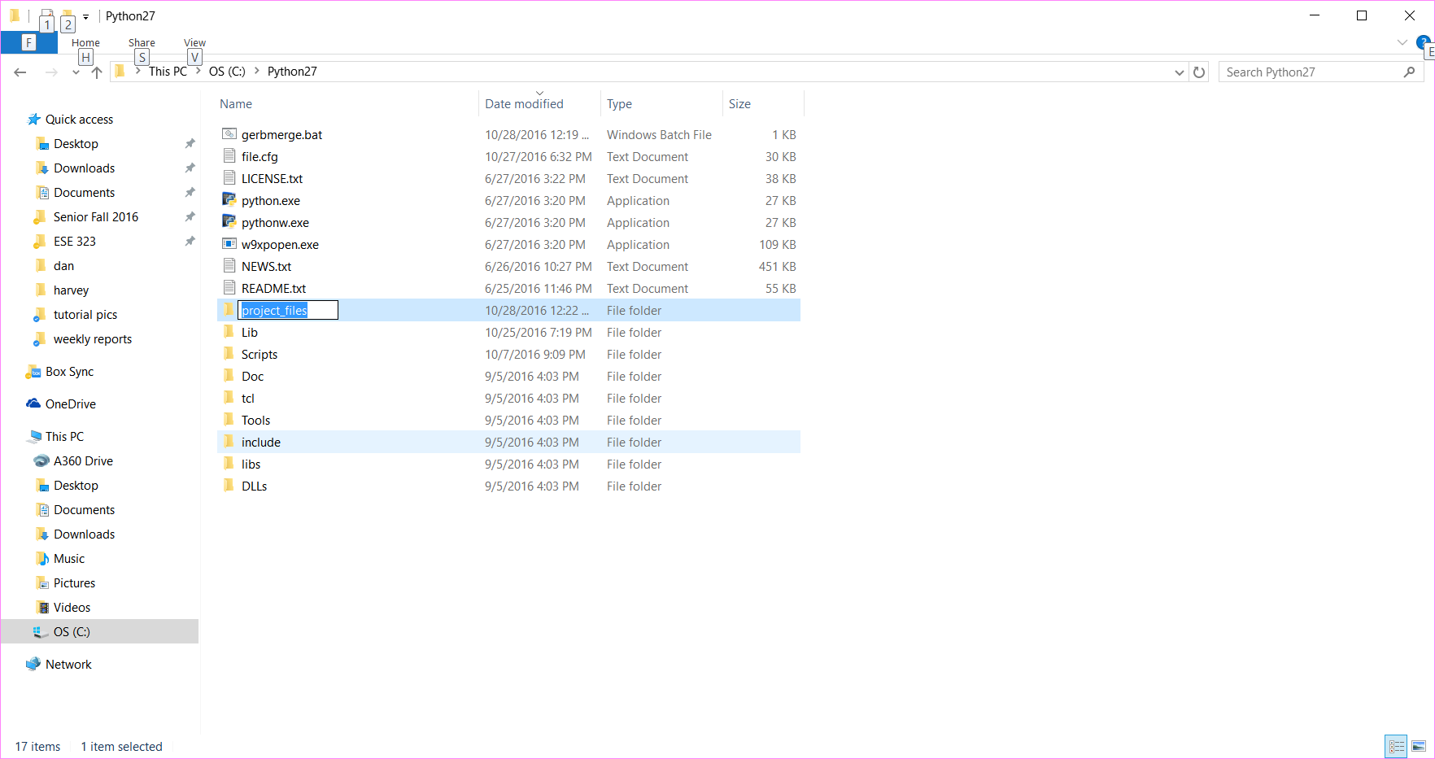
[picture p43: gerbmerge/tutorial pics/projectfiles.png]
project_files


* Create a new folder for each gerber file you want to combine. For instance, create folders called A, B, C, etc. (the names used for the folders here, will be the same names that will be used by the program to combine the files)
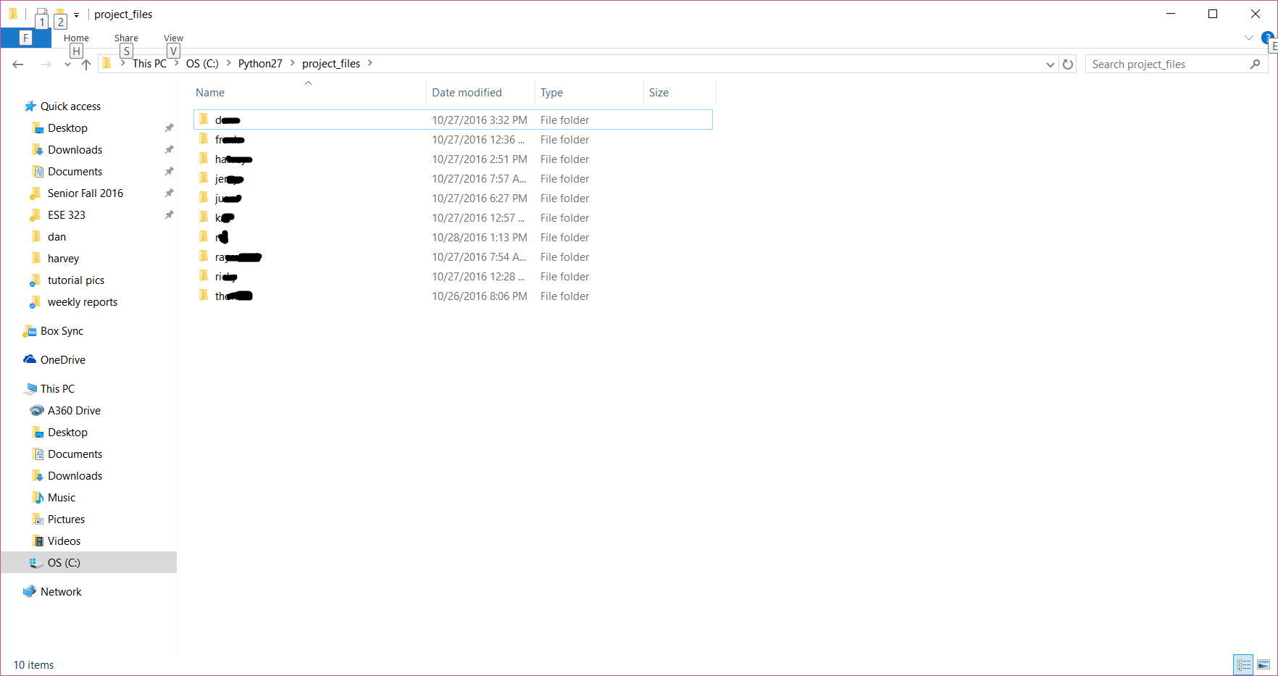
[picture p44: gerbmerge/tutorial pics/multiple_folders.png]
all files

* Place CAM files into each respective folder. For instance, place the CAM job files of each assigned person to their respective folders

* Check if all these files are each folder inside the folder - **.BOR,.GBL,.GBO,.GBP,.GBS,.GML,.GTL,.GTO,.GTP,.GTS,.TXT** (11)
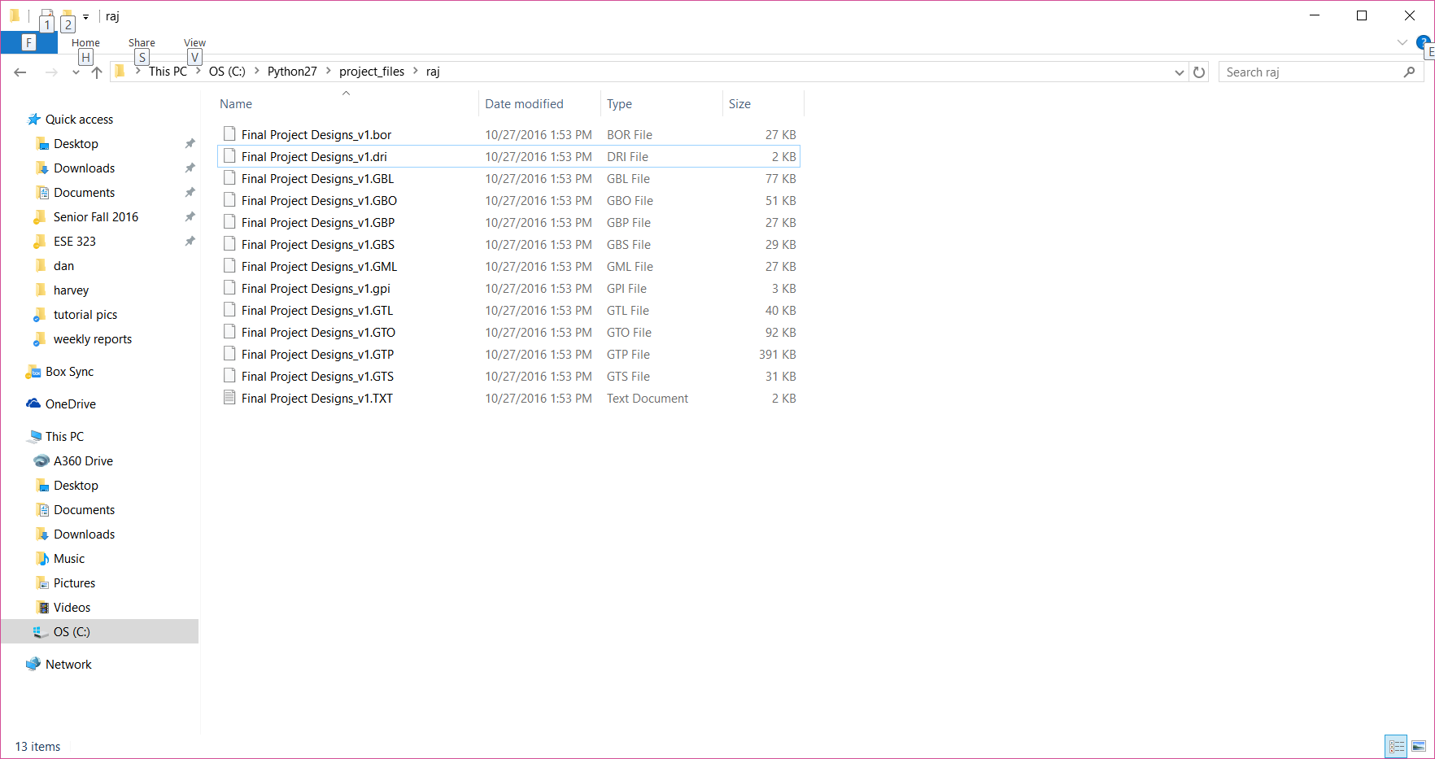
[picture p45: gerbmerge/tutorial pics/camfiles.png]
cam files

*Failure to do so will result in an error.*

##Creating Configuration File
Download the configuration file from [here](https://github.com/radrajith/gerbmerge/blob/master/file.cfg)

Then open the configuration file (file.cfg) in any text editor, I used [notepad++](https://notepad-plus-plus.org/download/v7.1.html). 

###Carefully follow the instructions below and modify the ```**file.cfg**``` . **Note the '#' symbol is used to indicate comments in the code.** 
*Look for these lines* 
```
# Change projdir to wherever your project files are, for example:
#
#   projdir = project_files
#
# or relative pathname from where you are running GerbMerge
#
#   projdir = testdata
#
# or if all files are in the current directory (as in this example):
#
#   projdir = .
projdir = project_files

# For convenience, this is the base name of the merged output files.
MergeOut = merge
```
*If you named your folder something else other than 'project_files', change it to the appropriate name.*

The output file(s) after running gerbmerge will all be named merge(.extension), feel free to rename it to whatever you want. 

If you want to change the spacing between the each boards, modify this x and y spacing
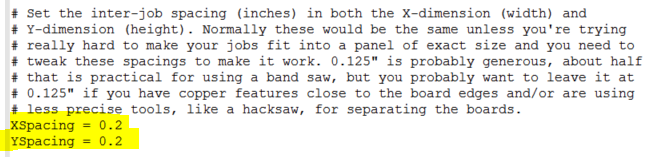
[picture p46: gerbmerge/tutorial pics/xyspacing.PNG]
xyspacing


Next, scroll down all the way to bottom, and then copy the code below for as many boards you want to combine. (In my case I had 10 different gerber files to merge, so I copy pasted the below code 10 times.) 
```
[raj]

# You can set any options you like to make generating filenames easier, like
# Prefix. This is just a helper option, not a reserved name. Note, however,
# that you must write %(prefix)s below, in ALL LOWERCASE.
#
# Note how we are making use of the 'projdir' string defined way up at the top
# in the [DEFAULT] section to save some typing. By setting 'projdir=somedir'
# the expression '%(projdir)s/proj1' expands to 'somedir/proj1'.
Prefix=%(projdir)s/raj/Final Project Designs_v1

# List all the layers that participate in this job. Required layers are Drills
# and BoardOutline and have no '*' at the beginning.  Optional layers have
# names chosen by you and begin with '*'. You should choose consistent layer
# names across all jobs.
*TopLayer=%(prefix)s.GTL
*BottomLayer=%(prefix)s.GBL
*TopSilkscreen=%(prefix)s.GTO
*BottomSilkscreen=%(prefix)s.GBO
*TopSoldermask=%(prefix)s.GTS
*BottomSoldermask=%(prefix)s.GBS
Drills=%(prefix)s.TXT
BoardOutline=%(prefix)s.BOR

# If this job does not have drill tool sizes embedded in the Excellon file, it
# needs to have a separate tool list file that maps tool names (e.g., 'T01') to
# tool diameter. This may be the global tool list specified in the [Options]
# section with the ToolList parameter. If this job doesn't have embedded tool
# sizes, and uses a different tool list than the global one, you can specify it
# here.
#ToolList=proj1.drl

# If this job has a different ExcellonDecimals setting than the global setting
# in the [Options] section above, it can be overridden here.
ExcellonDecimals = 5
# You can set a 'Repeat' parameter for this job when using automatic placement
# (i.e., no *.def file) to indicate how many times this job should appear in
# the final panel. When using manual placement, this option is ignored.
Repeat = 1

################################################################
```
* Correct the lines, ```[raj]``` and ```Prefix=%(projdir)s/raj/Final Project Designs_v1``` to correspond whatever folder/names are being used. See:
foldername

Once the above changes have been made, save the file and place it in the python2.7 folder(same location where 'project_files' folder is located).

#Running the Gerbmerge Program. 
Go to the python2.7 folder if you are not already there. Once again open up the command window from within the folder by going to the address bar and typing ```cmd```. 
openning command line

After openning the command prompt, type in ```gerbmerge file.cfg``` and press enter.
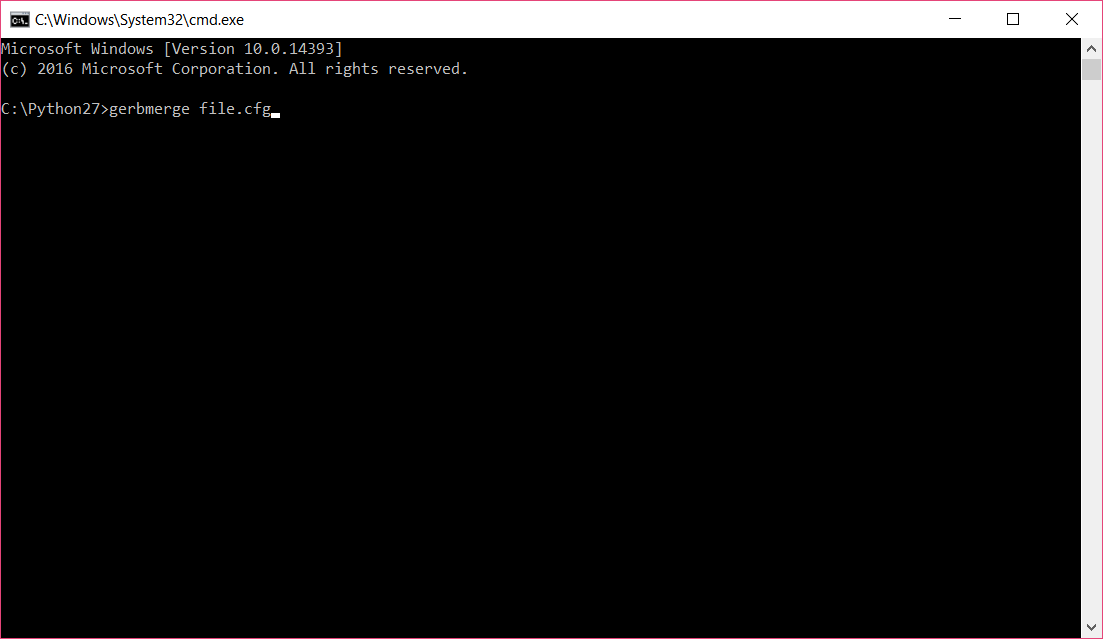
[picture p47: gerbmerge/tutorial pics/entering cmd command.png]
gerbmerge run


The following lines will be displayed, type ```y``` and press enter.
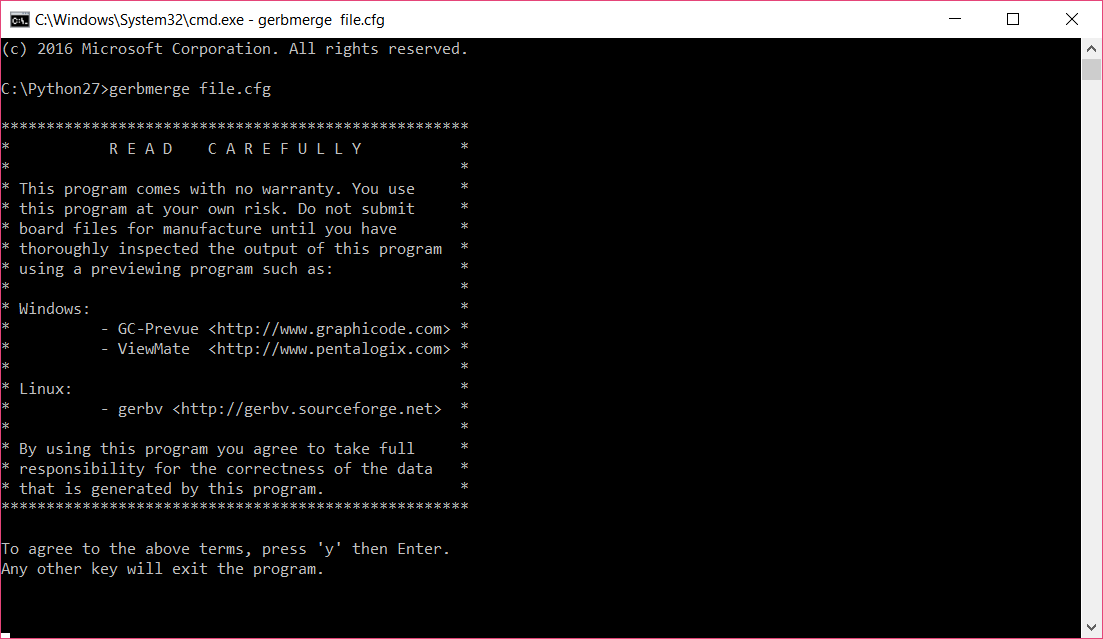
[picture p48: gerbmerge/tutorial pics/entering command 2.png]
cmd 1

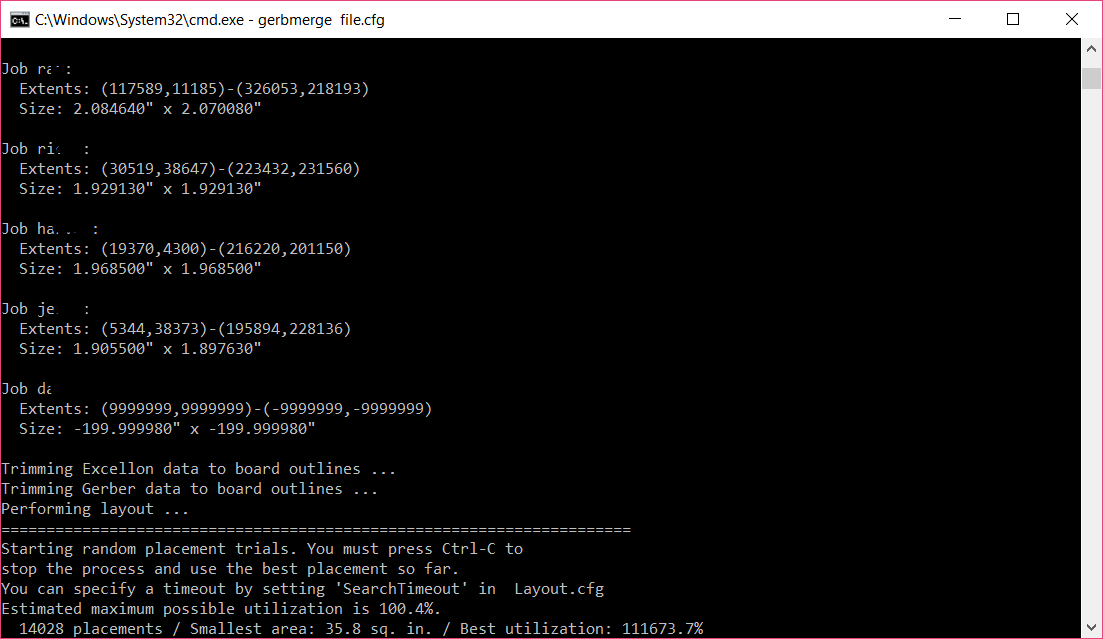
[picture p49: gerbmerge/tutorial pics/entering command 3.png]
cmd 2

The program will then run forever trying to find the best placement to minimized the space required. I usually let it run for 20-30s before pressing ctrl-c to stop the process and output the files. 
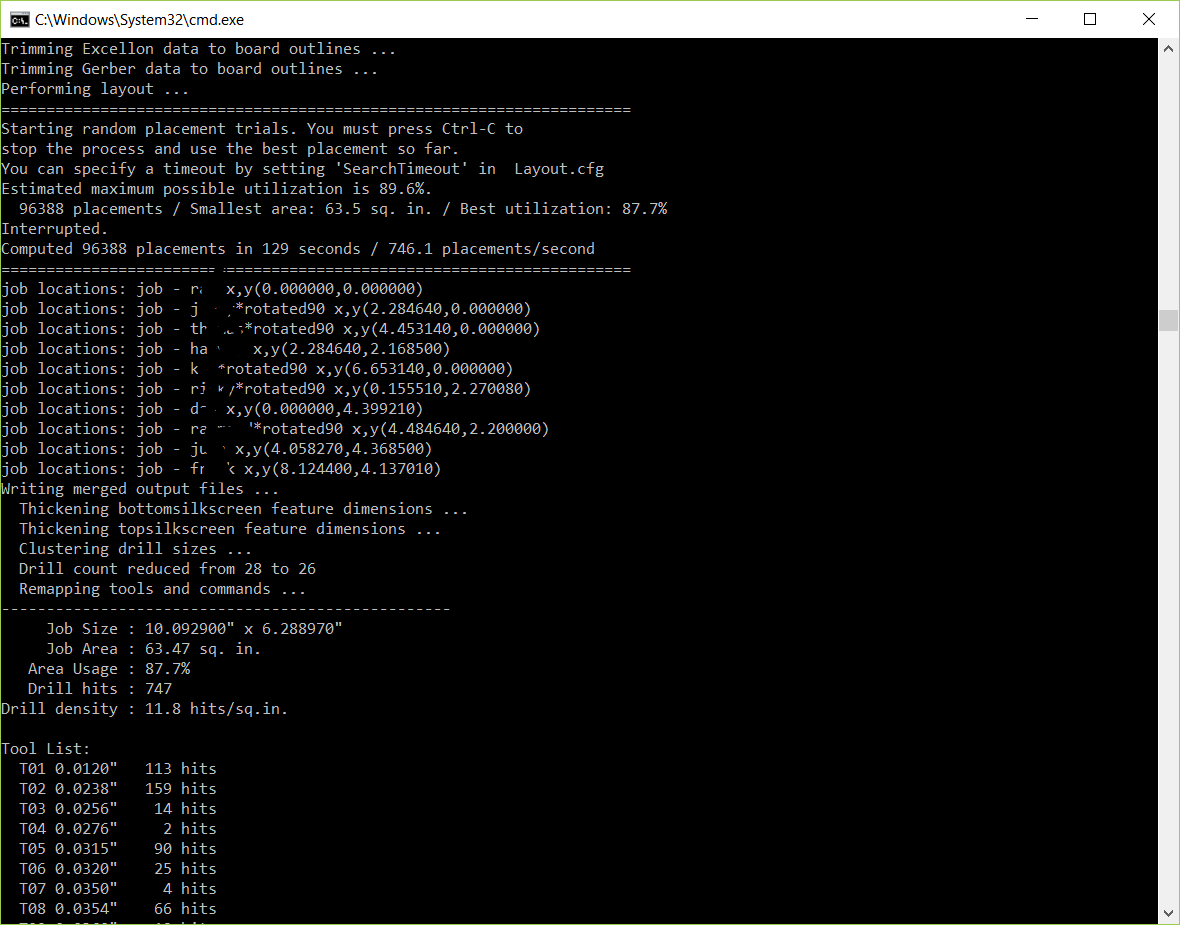
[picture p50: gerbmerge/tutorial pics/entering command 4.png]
cmd 3

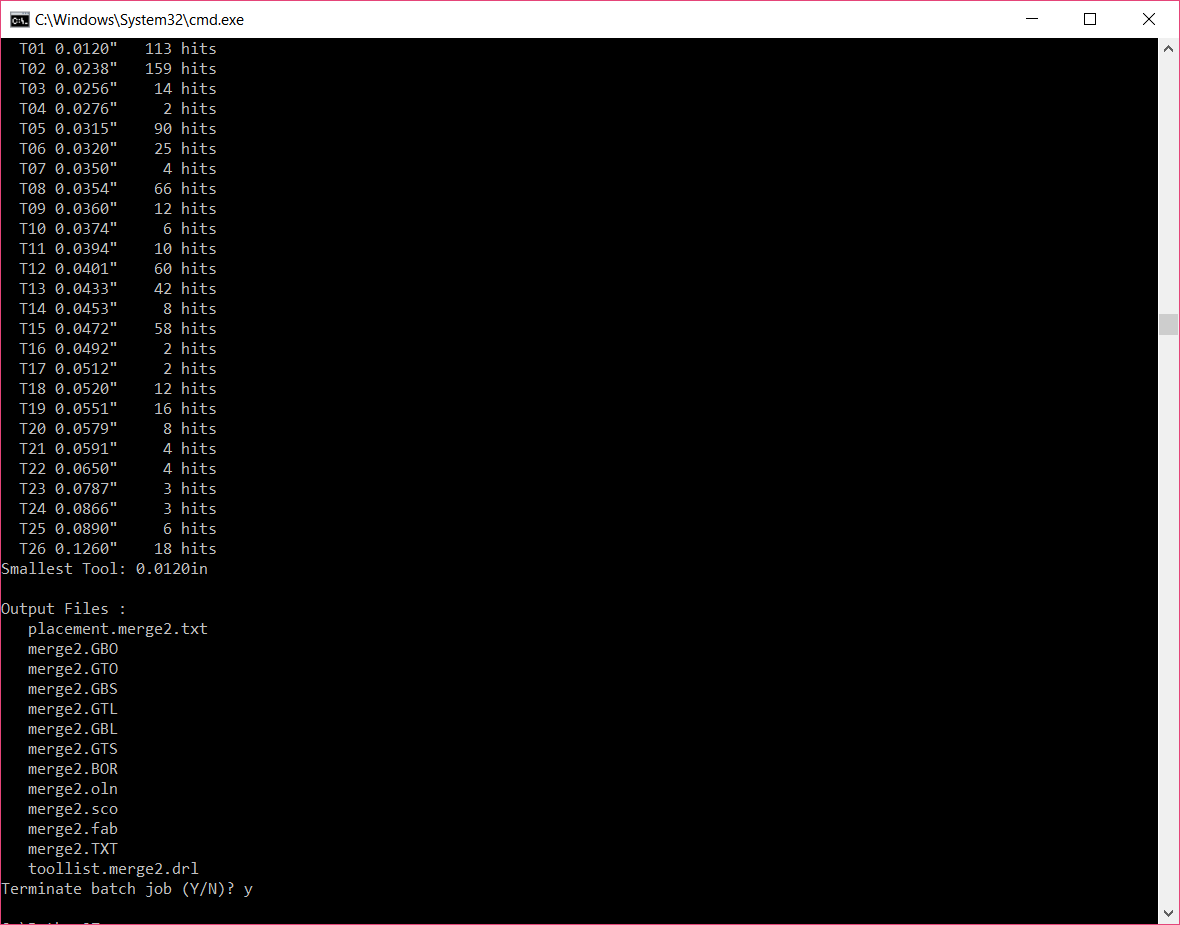
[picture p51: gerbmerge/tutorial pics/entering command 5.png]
cmd 4

Now you should see the all the files with merge2.(extension) generated in the python2.7 folder. 
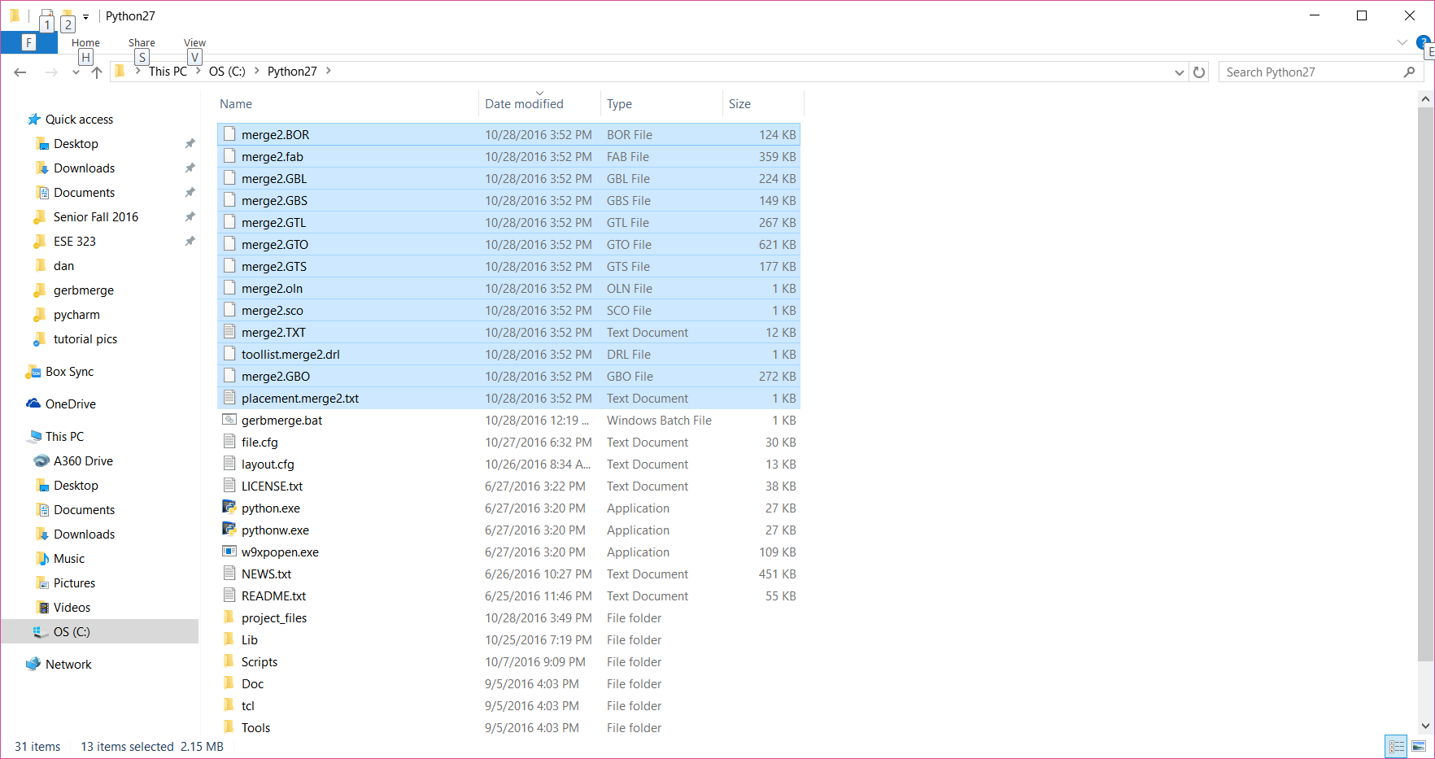
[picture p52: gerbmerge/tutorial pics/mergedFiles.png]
mergefiles


Since I am using seeedstudio's fusionpcb manufacturing service, I will now have to modify the drill file to meet their specification(s). The drill file output and the .fab file output do not meet their requirements, for this reason the program ```drillfix.py``` program was written/used. This program will be used to automatically correct the drill file to meet the specifications.

#How to Use Drillfix.py 
* Download the ``drillfix.py`` from [here](https://github.com/radrajith/gerbmerge/raw/master/ese323_drillfix.py). save it to the python2.7 folder.
* Open command prompt on this folder and type in ``python drillfix.py`` and press enter.
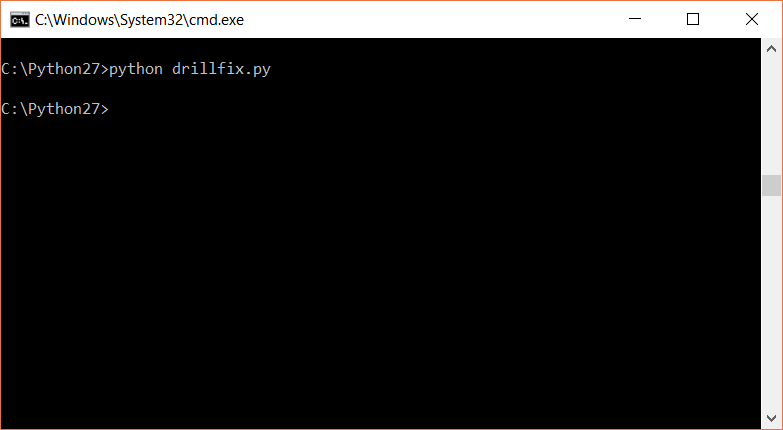
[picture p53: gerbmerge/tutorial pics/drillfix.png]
drillfix


Now there will be file called merge2_corrected.txt file. 
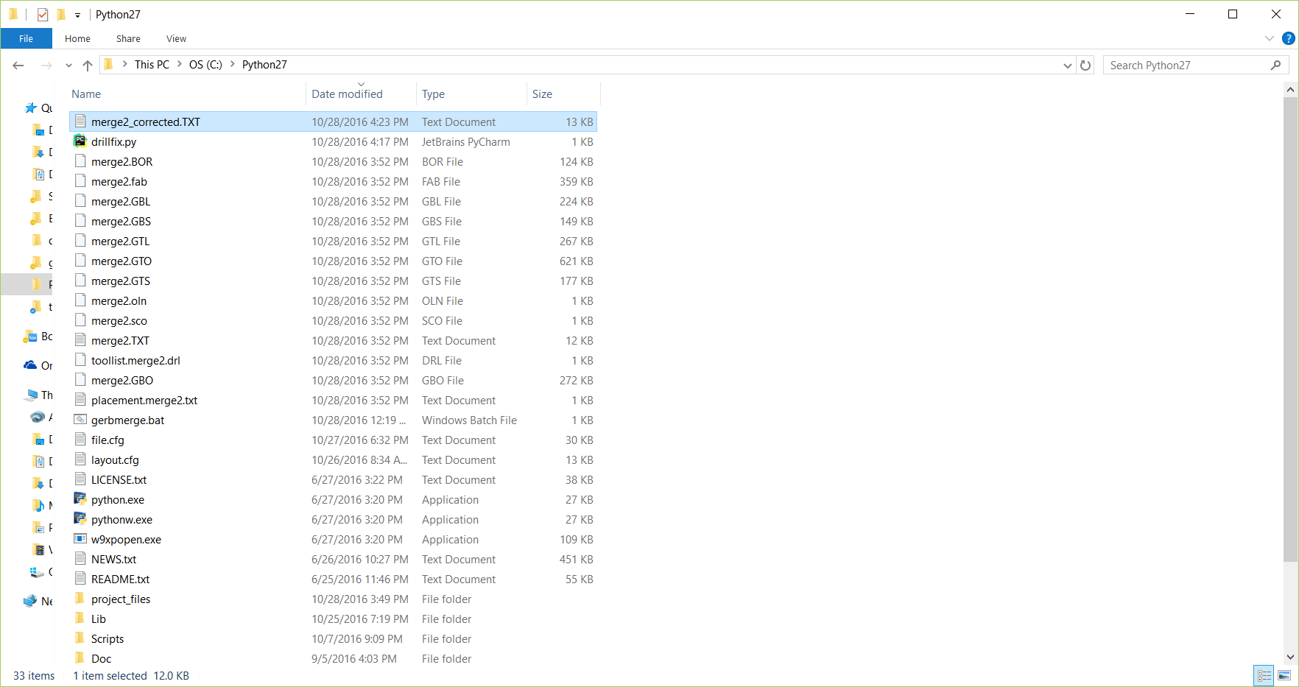
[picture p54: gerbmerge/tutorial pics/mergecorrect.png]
merge2corrected


* delete the merge2.TXT file
* rename the merge2_corrected.TXT file to merge2.TXT
* rename the merge2.fab to merge2.GML

All the files are now ready.

#Uploading to Fusionpcb
Copy **.GML, .GBL, .GBS, .GBO, . GTL, .GTO, .GTS, .TXT** (8) files in a folder and create a zip file of it. 

Open your browser, go to [fusion pcb](https://www.seeedstudio.com/new-fusion-pcb.html) (if the link is dead, search for fusionpcb services) and upload this zip file. Click gerber view and now you should be able to see all the layers of the superboard (all gerber files merged).

#Errors
##RuntimeError: only 26 different tool sizes supported for fabrication drawing
This error occurs when the combined files resulted in than 26 distinct drill hole sizes. (26 is number set by config/manufacturer) 
drillhole error

###Solution
* This problem can be fixed by rounding up the least used drill sizes to lessen the number of different sized drills. First, open the drill file, in our case ```merge2.txt``` file to find:
```
T01C0.012000
T02C0.023810
T03C0.025590
...
T23C0.078740
T24C0.086610
T25C0.089000
T26C0.125980
```
Here we have 26 different sizes here (T01-T26). The number after the ``.`` is the drill/hole size(inches). Example, "T02C0.023810" would be refered to as drill 2 of size .23810 inches. **Note that drill sizes here refer to all types of holes (through-holes, vias, and etc. Not just screw-holes)**.

Next, look through the drill file ```merge2.txt``` to determine which drills were least used. 
As an example see:
```
T16
X773340Y516260
X783340Y516260
T17
X989010Y458590
X989010Y510320
T18
X184410Y50670
X164720Y51220
X164720Y11220
X184410Y10670
X161560Y374840
X181560Y374840
X181930Y253050
X161930Y253050
X960390Y436190
X1000390Y436190
X1000780Y577330
X960780Y577330
T19
X360830Y106220
X360040Y78270
X400040Y78270
X400830Y106220
X557310Y135730
X557070Y172150
X597070Y172150
X597310Y135730
X342330Y583940
X382330Y583940
X381740Y491460
X341740Y491460
X493220Y469130
X493220Y449450
X563300Y449450
X563300Y469130
```
Drill sizes T16(2 drills) and T17(2 drills) are not used as much relative to T18(12 drills) or T19(15) drills. 

Locate them through Eagle's board-view to resize to next biggest size listed in drill file /```merge2.txt```. Fix them on the board and rerun the whole process. If you have trouble locating the drill/through holes/vias, make a copy of the drill file isolating the least used drills. Then load that copy onto a gerber viewer to visually see which drill holes/vias needs fixing.

##ImportError: No module named simpleparse.parser
>SimpleParse is a BSD-licensed Python package providing a simple and fast parser generator using a modified version of the mxTextTools >text-tagging engine.

[SimpleParse download link](http://simpleparse.sourceforge.net/)

##SyntaxError: Missing parentheses in call to 'print'
Are you using python 3 and up? Try again with python 2.7

--frankie finish the rest, talk about kawing program and how it helped find which board has used weird values and how we used the drill hits(one of the pics i uploaded should have the drill hits view).

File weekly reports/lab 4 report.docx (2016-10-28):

Rajith Radhakrishnan Lab Report 4 10/27/16

Board design - https://radrajith.github.io/ESE_323_PCB_Design/

During this week, Autodesk inventor was used to create the circuit board model. A rectangle was drawn with the exact dimensions of the board. 3 circle were placed at the exact same location as it is on the board and extrude tool was used to make it into holes. A rectangle with the length, width and height of the microprocessor was placed. A 14 pin header used for the LCD screen was placed with the correct dimensions, the screen shot of the model has been provided below. This lab was designed to get us used to the Inventor tools and UI.

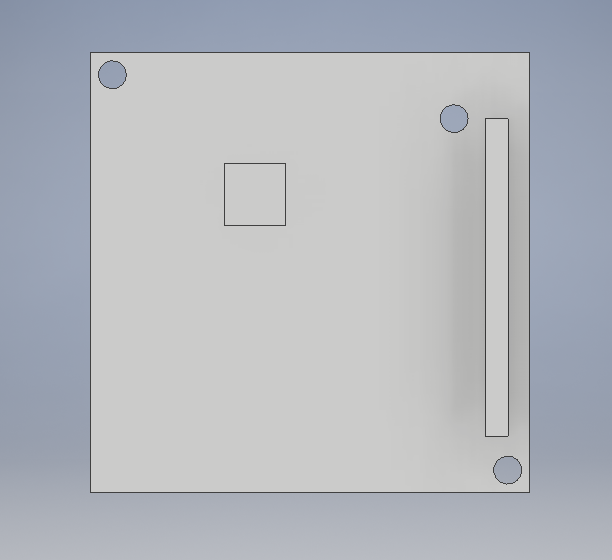
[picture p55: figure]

Front View

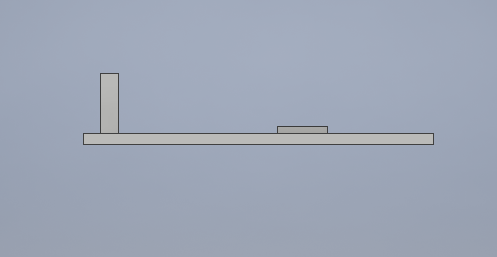
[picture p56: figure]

Side view

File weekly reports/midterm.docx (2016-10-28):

Rajith Radhakrishnan Midterm 1 10/27/16

1,2,3

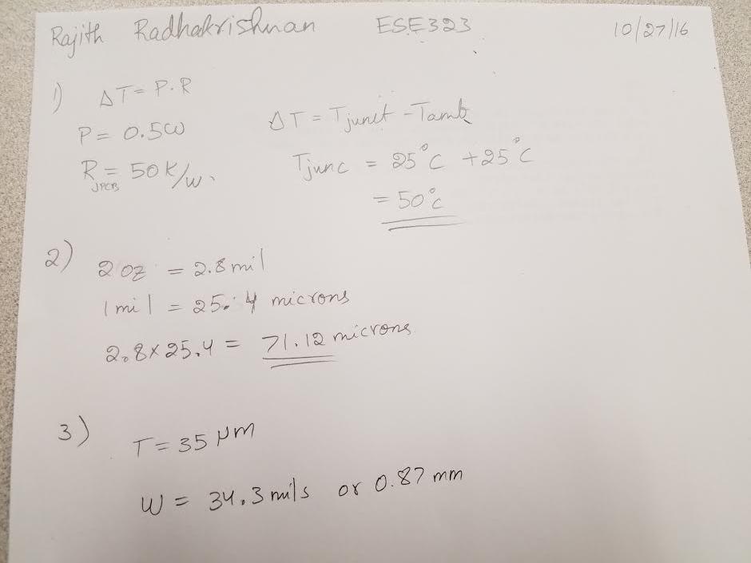
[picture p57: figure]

4.

5.Schematic design

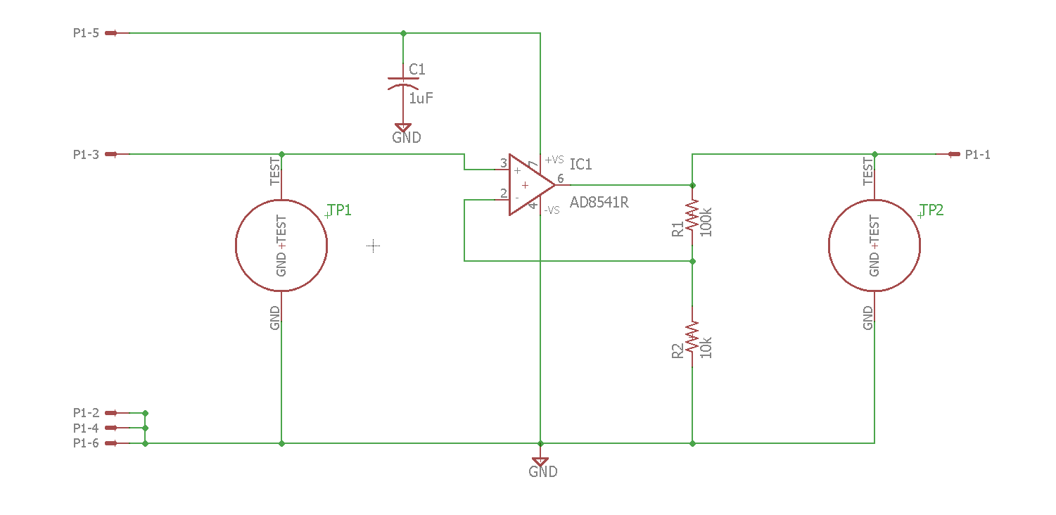
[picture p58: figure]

Board design

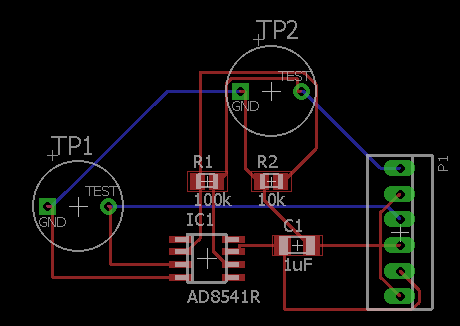
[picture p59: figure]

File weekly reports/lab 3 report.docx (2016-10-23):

Rajith Radhakrishnan lab 3 109061463

This week’s lab is about getting used to the autoroute and fixing any design rule errors and mistakes. This lab is used as a practice for the current meter designs. After performing autoroute, the result with least vias and 100% completion are selected. After implementing, any wires that are very close to the pad are assessed and moved away to avoid any electrical shorts.

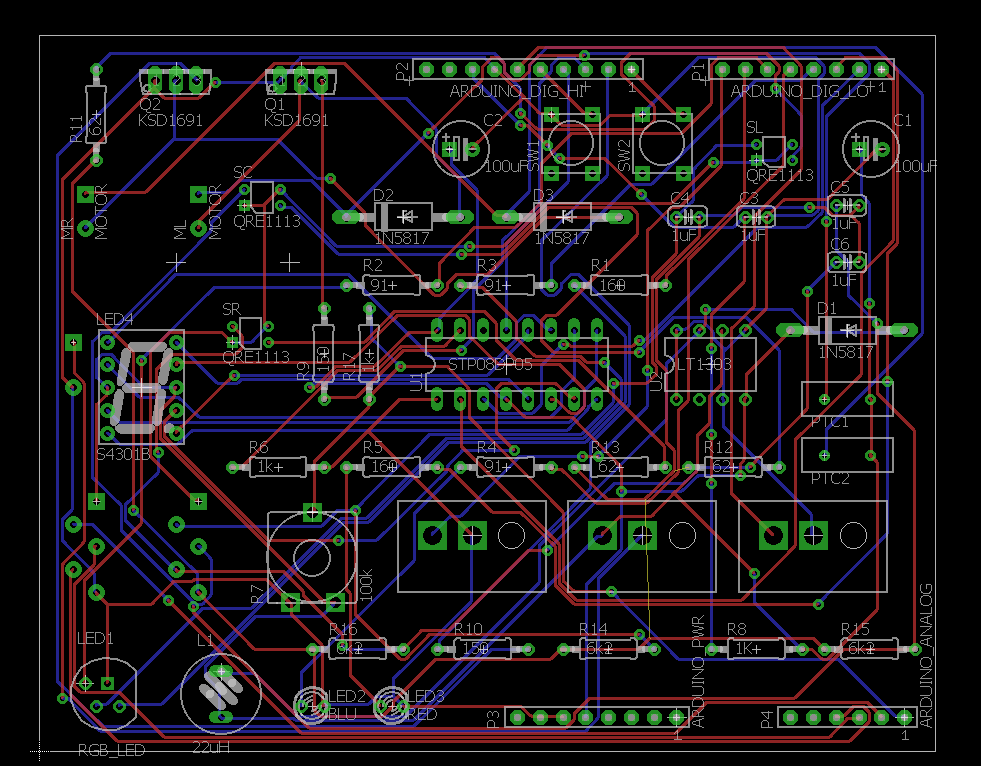
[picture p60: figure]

Current meter design schematic and bill of material

https://radrajith.github.io/ESE_323_PCB_Design/

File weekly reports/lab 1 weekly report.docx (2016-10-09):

Eagle PCB design software was introduced. In lab 1, a schematic was built with LM555 timer in astable configuration, to turn on/off two leds. LM555 is powered by a 9V battery and produces a oscillation with period of approximately 10s. This oscillation at the output is designed to toggle the leds at a frequency of 0.1 Hz. After the schematic was assembled as described by the lab manual, Electrical rule check button was pressed to find out any errors. Unconnected error was returned due to the CV port of the LM555 was left open. This error was ignored, and the lab 1 was successfully completed. The lab1 helped us in getting familiarized with the Eagle PCB design software.

The current meter design is intended to minimize the effects of burden voltage that is present in the multimeters used in the lab. The current meter will be designed to include 2 ranges – 100mA and 1A. The maximum current rating is set to be 10A and will only be able to read positive DC currents. The circuit will be powered by primary 9v battery, and the analog current measurement will be sampled at 12kSPS (based on atmega32 specs), and the digital output will have 10-bit resolution. The circuit will be protected using a fuse.

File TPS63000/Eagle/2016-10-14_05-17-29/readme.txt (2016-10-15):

**********************************************************
*************  Important Instructions Follow  ************
**********************************************************

All files exported to: Z:\\46\\52\\4652240\\15\Eagle\2016-10-14_05-17-29\2016-10-14_05-17-29.xml

**********************************************************
*****************Schematic Instructions  *******************
**********************************************************

To import your new Schematic file into Eagle:

1. Unzip the downloaded folder files to local directory and Start Eagle.
2. Select "File"->"Open"->"Schematic..." from the menu at the top of
the screen.
3. Browse to your newly exported file and select the ".sch" file extension.
4. You should now see your schamtic available in Eagle.

**********************************************************
*******************  PCB Instructions  *******************
**********************************************************

To import your new BOARD file into Eagle:

1. Unzip the downloaded folder files to local directory and Start Eagle.
2. Select "File"->"Open"->"Board..." from the menu at the top of
the screen.
3. Browse to your newly exported file and select the ".brd" file extension.
4. Planes will need to be repoured to update the polygon fills
	1. Once your board is loaded and before the repour, the default design rule
	   should be updated for Mask and thermal relief.
		a. Goto Edit and select Design Rules.
			-Select Masks Tab; Set Stop (Min & Max) to 0.0mm
			-Select Supply Tab; Set Thermal Isolation to 0.0mm
	2. To pour the polygon fills, goto Tools and select Ratsnest
	3. The polygons should all be filled now.
5. You should now have an image of your board available in Eagle.

**********************************************************
*******************  LIB Instructions  *******************
**********************************************************

To import your new library into Eagle:

1. Start Eagle.
2. Select "File"->"New"->"Library" from the menu.
3. In the blank library window, select "File" -> "Execute Script"
from the menu.
5. Browse to your newly exported Eagle Script file (".scr" file extension)
6. After opening the file, the script will populate the new library.
Layer 93 should NOT exist.
7. Use "File"->"Save" (or "Save As..") to save the library to the desired
location in Eagle native format.

For additional information, please visit this site:
http://www.accelerated-designs.com/help/Eagle_import.html

You may also find this video helpful:
http://youtu.be/5jGuWY-Yy3Q

**********************************************************
**********************************************************
**********************************************************

Component "LMK212BJ106KG-T" renamed to "LMK212BJ106KG-T"
Component "WB_LOAD_RESISTOR" renamed to "WB_LOAD_RESISTOR"
Component "WB_GND" renamed to "WB_GND"
Component "LQM21PN1R5MC0D" renamed to "LQM21PN1R5MC0D"
Component "CRCW0402178KFKED" renamed to "CRCW0402178KFKED"
Component "CRCW04021M00FKED" renamed to "CRCW04021M00FKED"
Component "TPS63000DRCR" renamed to "TPS63000DRCR"
Component "WB_STARTUP_VOLTAGE_SOURCE" renamed to "WB_STARTUP_VOLTAGE_SOURCE"
Component "LMK212BJ226MG-T" renamed to "LMK212BJ226MG-T"
The Symbol WB_CONTINUATION was missing a RefDes attribute, a refdes was created for the symbol.
The Symbol WB_CONTINUATION was missing a Type attribute, a type was created for the symbol.
The Symbol WB_CONTINUATION was missing a Value attribute, a value was created for the symbol.
The Symbol WB_BLOCK_IO was missing a RefDes attribute, a refdes was created for the symbol.
The Symbol WB_BLOCK_IO was missing a Type attribute, a type was created for the symbol.
The Symbol WB_BLOCK_IO was missing a Value attribute, a value was created for the symbol.
The Symbol WB_PWL_VOLTAGE_SOURCE was missing a RefDes attribute, a refdes was created for the symbol.
The Symbol WB_PWL_VOLTAGE_SOURCE was missing a Type attribute, a type was created for the symbol.
The Symbol WB_PWL_VOLTAGE_SOURCE was missing a Value attribute, a value was created for the symbol.
The Symbol WB_SOURCE_RESISTOR was missing a RefDes attribute, a refdes was created for the symbol.
The Symbol WB_SOURCE_RESISTOR was missing a Type attribute, a type was created for the symbol.
The Symbol WB_SOURCE_RESISTOR was missing a Value attribute, a value was created for the symbol.
The Symbol WB_PRIM_PWL_VOLTAGE_SOURCE was missing a RefDes attribute, a refdes was created for the symbol.
The Symbol WB_PRIM_PWL_VOLTAGE_SOURCE was missing a Type attribute, a type was created for the symbol.
The Symbol WB_PRIM_PWL_VOLTAGE_SOURCE was missing a Value attribute, a value was created for the symbol.
The Symbol WB_CURRENT_PROBE was missing a RefDes attribute, a refdes was created for the symbol.
The Symbol WB_CURRENT_PROBE was missing a Type attribute, a type was created for the symbol.
The Symbol WB_CURRENT_PROBE was missing a Value attribute, a value was created for the symbol.
The Symbol WB_PWL_CURRENT_LOAD was missing a RefDes attribute, a refdes was created for the symbol.
The Symbol WB_PWL_CURRENT_LOAD was missing a Type attribute, a type was created for the symbol.
The Symbol WB_PWL_CURRENT_LOAD was missing a Value attribute, a value was created for the symbol.
The Symbol WB_PRIM_STARTUP_VOLTAGE_SOURCE was missing a RefDes attribute, a refdes was created for the symbol.
The Symbol WB_PRIM_STARTUP_VOLTAGE_SOURCE was missing a Type attribute, a type was created for the symbol.
The Symbol WB_PRIM_STARTUP_VOLTAGE_SOURCE was missing a Value attribute, a value was created for the symbol.
The Symbol WB_TPS63000DRC was missing a RefDes attribute, a refdes was created for the symbol.
The Symbol WB_TPS63000DRC was missing a Type attribute, a type was created for the symbol.
The Symbol WB_TPS63000DRC was missing a Value attribute, a value was created for the symbol.
The Symbol WB_VOLTAGE_PROBE was missing a RefDes attribute, a refdes was created for the symbol.
The Symbol WB_VOLTAGE_PROBE was missing a Type attribute, a type was created for the symbol.
The Symbol WB_VOLTAGE_PROBE was missing a Value attribute, a value was created for the symbol.

Ultra Librarian Gold 8.1.44 Process Report

Message - Padstack "RX44Y57D0T" Shape(4) is a CIRCLE with no diameter.
Message - Padstack "RX22Y24D0T" Shape(4) is a CIRCLE with no diameter.
Message - Padstack "R10090240000200A" Shape(4) is a CIRCLE with no diameter.
Message - Padstack "R10650940000232A" Shape(4) is a CIRCLE with no diameter.
Message - Component "LMK212BJ106KG-T" attribute "Cap" references text style "" that is not in the database.
The default pattern text style "H50s3" was substituted.
Message - Component "LMK212BJ106KG-T" attribute "ESR" references text style "" that is not in the database.
The default pattern text style "H50s3" was substituted.
Message - Component "LMK212BJ106KG-T" attribute "IRMS" references text style "" that is not in the database.
The default pattern text style "H50s3" was substituted.
Message - Component "LMK212BJ106KG-T" attribute "VDC" references text style "" that is not in the database.
The default pattern text style "H50s3" was substituted.
Message - Component "LQM21PN1R5MC0D" attribute "L" references text style "" that is not in the database.
The default pattern text style "H50s3" was substituted.
Message - Component "LQM21PN1R5MC0D" attribute "DCR" references text style "" that is not in the database.
The default pattern text style "H50s3" was substituted.
Message - Component "LQM21PN1R5MC0D" attribute "IDC" references text style "" that is not in the database.
The default pattern text style "H50s3" was substituted.
Message - Component "CRCW0402178KFKED" attribute "Resistance" references text style "" that is not in the database.
The default pattern text style "H50s3" was substituted.
Message - Component "CRCW0402178KFKED" attribute "Power" references text style "" that is not in the database.
The default pattern text style "H50s3" was substituted.
Message - Component "CRCW0402178KFKED" attribute "Tolerance" references text style "" that is not in the database.
The default pattern text style "H50s3" was substituted.
Message - Component "CRCW04021M00FKED" attribute "Resistance" references text style "" that is not in the database.
The default pattern text style "H50s3" was substituted.
Message - Component "CRCW04021M00FKED" attribute "Power" references text style "" that is not in the database.
The default pattern text style "H50s3" was substituted.
Message - Component "CRCW04021M00FKED" attribute "Tolerance" references text style "" that is not in the database.
The default pattern text style "H50s3" was substituted.
Message - Component "LMK212BJ226MG-T" attribute "Cap" references text style "" that is not in the database.
The default pattern text style "H50s3" was substituted.
Message - Component "LMK212BJ226MG-T" attribute "ESR" references text style "" that is not in the database.
The default pattern text style "H50s3" was substituted.
Message - Component "LMK212BJ226MG-T" attribute "IRMS" references text style "" that is not in the database.
The default pattern text style "H50s3" was substituted.
Message - Component "LMK212BJ226MG-T" attribute "VDC" references text style "" that is not in the database.
The default pattern text style "H50s3" was substituted.

TextStyle count:  24
Padstack count:   4
Pattern count:    3
Symbol count:     17
Component count:  9

Export

Footprint "WB_LOAD_RESISTOR" has no layer data mapped and will be skipped.
Component "WB_LOAD_RESISTOR" requires footprint "WB_LOAD_RESISTOR" and will be skipped.
Footprint "WB_GND" has no layer data mapped and will be skipped.
Component "WB_GND" requires footprint "WB_GND" and will be skipped.
Footprint "WB_STARTUP_VOLTAGE_SOURCE" has no layer data mapped and will be skipped.
Component "WB_STARTUP_VOLTAGE_SOURCE" requires footprint "WB_STARTUP_VOLTAGE_SOURCE" and will be skipped.

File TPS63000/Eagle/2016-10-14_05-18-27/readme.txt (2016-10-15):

**********************************************************
*************  Important Instructions Follow  ************
**********************************************************

All files exported to: Z:\\46\\52\\4652240\\15\Eagle\2016-10-14_05-18-27\2016-10-14_05-18-27.xml

**********************************************************
*****************Schematic Instructions  *******************
**********************************************************

To import your new Schematic file into Eagle:

1. Unzip the downloaded folder files to local directory and Start Eagle.
2. Select "File"->"Open"->"Schematic..." from the menu at the top of
the screen.
3. Browse to your newly exported file and select the ".sch" file extension.
4. You should now see your schamtic available in Eagle.

**********************************************************
*******************  PCB Instructions  *******************
**********************************************************

To import your new BOARD file into Eagle:

1. Unzip the downloaded folder files to local directory and Start Eagle.
2. Select "File"->"Open"->"Board..." from the menu at the top of
the screen.
3. Browse to your newly exported file and select the ".brd" file extension.
4. Planes will need to be repoured to update the polygon fills
	1. Once your board is loaded and before the repour, the default design rule
	   should be updated for Mask and thermal relief.
		a. Goto Edit and select Design Rules.
			-Select Masks Tab; Set Stop (Min & Max) to 0.0mm
			-Select Supply Tab; Set Thermal Isolation to 0.0mm
	2. To pour the polygon fills, goto Tools and select Ratsnest
	3. The polygons should all be filled now.
5. You should now have an image of your board available in Eagle.

**********************************************************
*******************  LIB Instructions  *******************
**********************************************************

To import your new library into Eagle:

1. Start Eagle.
2. Select "File"->"New"->"Library" from the menu.
3. In the blank library window, select "File" -> "Execute Script"
from the menu.
5. Browse to your newly exported Eagle Script file (".scr" file extension)
6. After opening the file, the script will populate the new library.
Layer 93 should NOT exist.
7. Use "File"->"Save" (or "Save As..") to save the library to the desired
location in Eagle native format.

For additional information, please visit this site:
http://www.accelerated-designs.com/help/Eagle_import.html

You may also find this video helpful:
http://youtu.be/5jGuWY-Yy3Q

**********************************************************
**********************************************************
**********************************************************

Component "TP-1502" renamed to "TP-1502"
Component "TPS63000DRCR" renamed to "TPS63000DRCR"
Component "CRCW04021M00FKED" renamed to "CRCW04021M00FKED"
Component "CRCW0402178KFKED" renamed to "CRCW0402178KFKED"
Component "LMK212BJ226MG-T" renamed to "LMK212BJ226MG-T"
Component "LMK212BJ106KG-T" renamed to "LMK212BJ106KG-T"
Component "LQM21PN1R5MC0D" renamed to "LQM21PN1R5MC0D"

Ultra Librarian Gold 8.1.44 Process Report

Message - Padstack "R10090240000200A" Shape(4) is a CIRCLE with no diameter.
Message - Padstack "R10650940000232A" Shape(4) is a CIRCLE with no diameter.
Message - Padstack "RX22Y24D0T" Shape(4) is a CIRCLE with no diameter.
Message - Padstack "RX44Y57D0T" Shape(4) is a CIRCLE with no diameter.
Message - Component "CRCW04021M00FKED" attribute "Resistance" references text style "" that is not in the database.
The default pattern text style "H50s3" was substituted.
Message - Component "CRCW04021M00FKED" attribute "Power" references text style "" that is not in the database.
The default pattern text style "H50s3" was substituted.
Message - Component "CRCW04021M00FKED" attribute "Tolerance" references text style "" that is not in the database.
The default pattern text style "H50s3" was substituted.
Message - Component "CRCW0402178KFKED" attribute "Resistance" references text style "" that is not in the database.
The default pattern text style "H50s3" was substituted.
Message - Component "CRCW0402178KFKED" attribute "Power" references text style "" that is not in the database.
The default pattern text style "H50s3" was substituted.
Message - Component "CRCW0402178KFKED" attribute "Tolerance" references text style "" that is not in the database.
The default pattern text style "H50s3" was substituted.
Message - Component "LMK212BJ226MG-T" attribute "Cap" references text style "" that is not in the database.
The default pattern text style "H50s3" was substituted.
Message - Component "LMK212BJ226MG-T" attribute "ESR" references text style "" that is not in the database.
The default pattern text style "H50s3" was substituted.
Message - Component "LMK212BJ226MG-T" attribute "IRMS" references text style "" that is not in the database.
The default pattern text style "H50s3" was substituted.
Message - Component "LMK212BJ226MG-T" attribute "VDC" references text style "" that is not in the database.
The default pattern text style "H50s3" was substituted.
Message - Component "LMK212BJ106KG-T" attribute "Cap" references text style "" that is not in the database.
The default pattern text style "H50s3" was substituted.
Message - Component "LMK212BJ106KG-T" attribute "ESR" references text style "" that is not in the database.
The default pattern text style "H50s3" was substituted.
Message - Component "LMK212BJ106KG-T" attribute "IRMS" references text style "" that is not in the database.
The default pattern text style "H50s3" was substituted.
Message - Component "LMK212BJ106KG-T" attribute "VDC" references text style "" that is not in the database.
The default pattern text style "H50s3" was substituted.
Message - Component "LQM21PN1R5MC0D" attribute "L" references text style "" that is not in the database.
The default pattern text style "H50s3" was substituted.
Message - Component "LQM21PN1R5MC0D" attribute "DCR" references text style "" that is not in the database.
The default pattern text style "H50s3" was substituted.
Message - Component "LQM21PN1R5MC0D" attribute "IDC" references text style "" that is not in the database.
The default pattern text style "H50s3" was substituted.

TextStyle count:  25
Padstack count:   7
Pattern count:    4
Symbol count:     5
Component count:  7

Export

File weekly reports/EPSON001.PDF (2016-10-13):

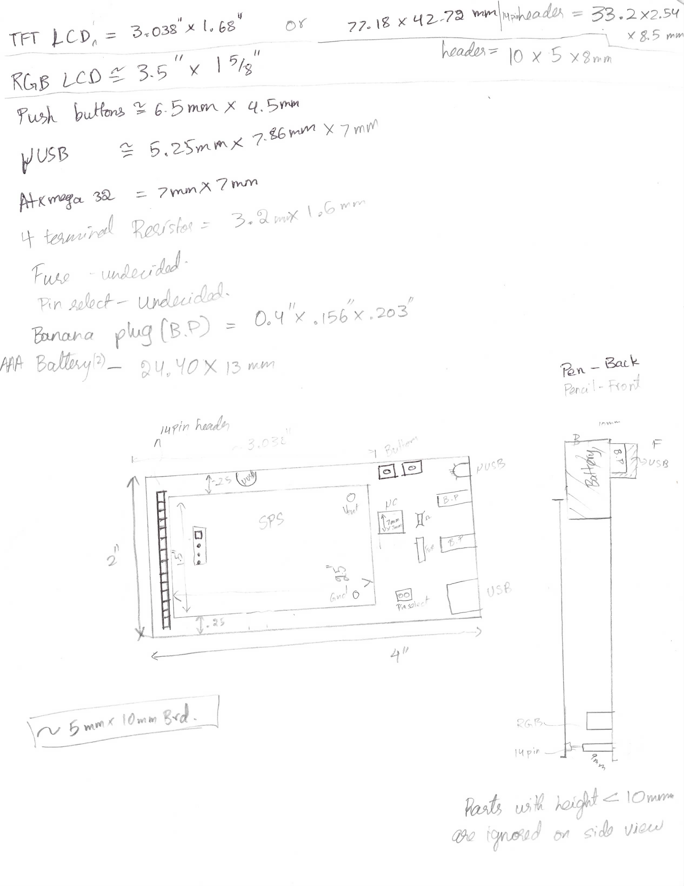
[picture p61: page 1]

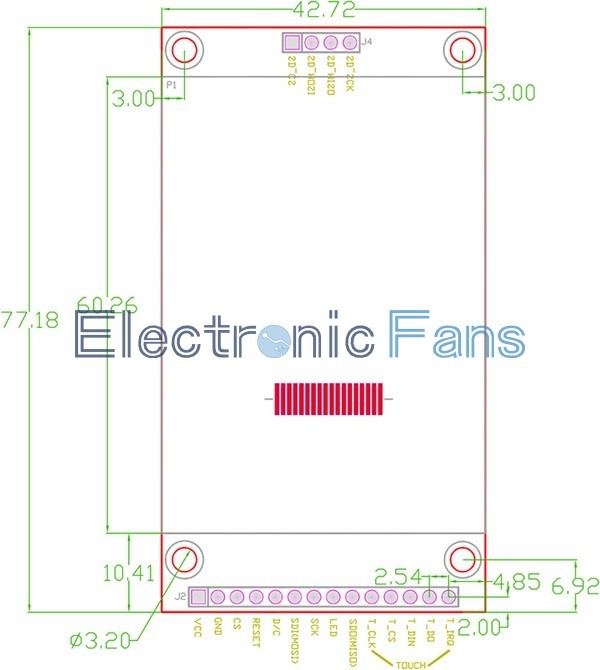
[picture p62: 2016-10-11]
Pictures/LCD TFT screen/mechanical.jpg

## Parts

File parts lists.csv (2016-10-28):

Designation | Description | Manufacturer | manufacturer part no | vendor | vendor part number | quantity | cost/part | Total price | Status | Notes
LCD | LCD display | uxcell | a14121800ux0780 | Amazon |  | 1 | 13.36 | 13.36 | arrived | 3.3V 240x320 2.4" SPI TFT LCD Touch Panel Module https://www.amazon.com/gp/product/B00W8TPNIK/ref=oh_aui_detailpage_o00_s00?ie=UTF8&psc=1
CON2 | Universal 4 pin connector | Seeedstudio | 110990037 | mouser | ACC39258O | 1 | 1.5 | 1.5 |  | connector for seeedstudio rgb lcd screen.
X1, X2 | Micro Usb | Amphenol FCI | 10118192-0001LF | Digikey | 609-4613-1-ND | 1 | 0.46 | 0.47
RGB | RGB lcd display | Seeedstudio | 104030001 | seeedstudio |  | 1 | 0 | 0 | arrived | already own this product
X3 | USB |  |  |  |  | 1 | 0 | 0 |  | obtain from prof
X4 | Jtag |  |  |  |  | 1 | 0 | 0 |  | obtain from prof
U2 | Atxmega 32 E5 | atmel |  |  |  | 1 | 0 | 0 |  | obtain from prof
R1 | 4 terminal Resistor | ohmite | FC4L64R010FER | Digikey | FC4L64R010FERCT-ND | 1 | 1.62 | 1.62
X5 | black Banana plugs | Cinch connectivity | 105-0753-001 | digikey | J110-ND | 1 | 0.87 | 0.87
X6 | red Banana plugs | Cinch connectivity | 105-0752-001 | Digikey | J109-ND | 1 | 0.87 | 0.87
R2,R3,R4,R5,R6 | 1kohm current limiting resistor | yangeo | RC1206JR-071KL | Digikey | 311-1.0KERCT-ND | 50 | 0.0106 | 0.53 |  | required quantity 6-8/person
R2,R3,R4,R5,R7 | 0 ohm resistor | yangeo | RC1206JR-070RL | Digikey | 311-0.0ERCT-ND | 50 | 0.0138 | 0.69 |  | if in case 1k resistor is not needed. Put this in place of that smt location
Battery | battery holder | MPD | SBH421AS | digikey | SBH421AS-ND | 1 | 1.27 | 1.27 |  | might be replaced with sparkfun one
PB1, PB2 | push button | omron | B3FS-1010P | Digikey | SW1440CT-ND | 2 | 0.79 | 0.79
F1 | fuse | bel fuse | C1H 10 | Digikey | 507-1942-1-ND | 5 | 0.306 | 1.53
CON1 | 14 pin header | gtk | fhss14g10/rh | ebay |  | 1 | 0.4 | 0.4 | ordered | 10 for $4
 | Printed Circuit Board | fusion pcb | 5x5 | seeedstudio |  | 5 | $7.40 | 7.4 |  | The board was manufactured by combining 10 peoples projects and the cost was reduced from $17 to 7 dollars each
Switching Power Supply
Cin | capacitor | Taiyo Yuden | LMK212BJ106KG-T | Digikey | 587-1300-1-ND | 1 | $0.20 | $0.20 |  | 10 | 0.139 | 1.39
Cout | capacitor | Taiyo Yuden | LMK212BJ226MG-T | Digikey | 587-1958-1-ND | 2 | $0.71 | $0.14 |  | 10 | 0.56 | 5.6
L1 | inductor | MuRata | LQM21PN1R5MC0D | Digikey | 490-4993-1-ND | 1 | $0.13 | $0.13 |  | 10 | 0.119 | 1.19
Rfbb | resistor | Vishay-Dale | CRCW0402178KFKED | Digikey | 541-178KLCT-ND | 1 | $0.10 | $0.10 |  | 10 | 0.032 | 0.32
Rfbt | resistor | Vishay-Dale | CRCW04021M00FKED | Digikey | 541-1.00MLCT-ND | 1 | $0.10 | $0.10 |  | 25 | 0.0232 | 0.58
U1 | chip | Texas Instruments | TPS63000DRCR | TI |  | 1 | $2.13 | $2.13 |  | 10 | 1.91 | 19.1
 |  |  |  |  |  |  | Total | 37.51

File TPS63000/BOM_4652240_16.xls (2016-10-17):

Part | Manufacturer | Part Number | Quantity | Price | Attribute 1 Name | Attribute 1 Value | Attribute 2 Name | Attribute 2 Value | Attribute 3 Name | Attribute 3 Value | Footprint
Cin | Taiyo Yuden | LMK212BJ106KG-T | 1 | 0.03 |  |  |  |  |  |  | 0805
Cout | Taiyo Yuden | LMK212BJ226MG-T | 2 | 0.12 |  |  |  |  |  |  | 0805
L1 | MuRata | LQM21PN1R5MC0D | 1 | 0.04 | L | 1.5uH | DCR | 0.26Ohm | IDC | 0.7A | 0805
Rfbb | Vishay-Dale | CRCW0402178KFKED | 1 | 0.01 | Resistance | 178kOhm | Tolerance | 1% | Power | 0.063W | 0402
Rfbt | Vishay-Dale | CRCW04021M00FKED | 1 | 0.01 | Resistance | 1000kOhm | Tolerance | 1% | Power | 0.063W | 0402
U1 | Texas Instruments | TPS63000DRCR | 1 | 0.85 |  |  |  |  |  |  | DRC0010J

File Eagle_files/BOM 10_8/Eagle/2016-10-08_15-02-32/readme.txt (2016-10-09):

**********************************************************
*************  Important Instructions Follow  ************
**********************************************************

All files exported to: Z:\\46\\52\\4652240\\3\Eagle\2016-10-08_15-02-32\2016-10-08_15-02-32.xml

**********************************************************
*****************Schematic Instructions  *******************
**********************************************************

To import your new Schematic file into Eagle:

1. Unzip the downloaded folder files to local directory and Start Eagle.
2. Select "File"->"Open"->"Schematic..." from the menu at the top of
the screen.
3. Browse to your newly exported file and select the ".sch" file extension.
4. You should now see your schamtic available in Eagle.

**********************************************************
*******************  PCB Instructions  *******************
**********************************************************

To import your new BOARD file into Eagle:

1. Unzip the downloaded folder files to local directory and Start Eagle.
2. Select "File"->"Open"->"Board..." from the menu at the top of
the screen.
3. Browse to your newly exported file and select the ".brd" file extension.
4. Planes will need to be repoured to update the polygon fills
	1. Once your board is loaded and before the repour, the default design rule
	   should be updated for Mask and thermal relief.
		a. Goto Edit and select Design Rules.
			-Select Masks Tab; Set Stop (Min & Max) to 0.0mm
			-Select Supply Tab; Set Thermal Isolation to 0.0mm
	2. To pour the polygon fills, goto Tools and select Ratsnest
	3. The polygons should all be filled now.
5. You should now have an image of your board available in Eagle.

**********************************************************
*******************  LIB Instructions  *******************
**********************************************************

To import your new library into Eagle:

1. Start Eagle.
2. Select "File"->"New"->"Library" from the menu.
3. In the blank library window, select "File" -> "Execute Script"
from the menu.
5. Browse to your newly exported Eagle Script file (".scr" file extension)
6. After opening the file, the script will populate the new library.
Layer 93 should NOT exist.
7. Use "File"->"Save" (or "Save As..") to save the library to the desired
location in Eagle native format.

For additional information, please visit this site:
http://www.accelerated-designs.com/help/Eagle_import.html

You may also find this video helpful:
http://youtu.be/5jGuWY-Yy3Q

**********************************************************
**********************************************************
**********************************************************

Padstack "RX86p61Y314p96D0T" renamed to "RX86p61Y314p96D0"
Symbol "WB_COMPENSATION_BLOCK_TYPE1_VERT" renamed to "WB_COMPENSATION_BLOCK_TYPE1_VE"
Symbol "WB_COMPENSATION_BLOCK_TYPE2_VERT" renamed to "WB_COMPENSATION_BLOCK_TYPE2_VE"
Component "GRM155R61A104KA01D" renamed to "GRM155R61A104KA01D"
Component "10TPU4R7MSI" renamed to "10TPU4R7MSI"
Component "CL21C122JBFNNWE" renamed to "CL21C122JBFNNWE"
Component "GRM21BR71A225KA01L" renamed to "GRM21BR71A225KA01L"
Component "B220-13-F" renamed to "B220-13-F"
Component "GRM2195C1H512JA01D" renamed to "GRM2195C1H512JA01D"
Component "CSD17308Q3" renamed to "CSD17308Q3"
Component "WB_CURRENT_LOAD" renamed to "WB_CURRENT_LOAD"
Component "CRCW040269K8FKED" renamed to "CRCW040269K8FKED"
Component "CRCW040210K0FKED" renamed to "CRCW040210K0FKED"
Component "CRCW040216K2FKED" renamed to "CRCW040216K2FKED"
Component "CRCW0402100RFKED" renamed to "CRCW0402100RFKED"
Component "ERJ-L14KF33MU" renamed to "ERJ-L14KF33MU"
Component "LM3488MMX/NOPB" renamed to "LM3488MMX/NOPB"
Component "CRCW040220R0FKED" renamed to "CRCW040220R0FKED"
Component "GRM155R61A823KA01D" renamed to "GRM155R61A823KA01D"
Component "CRCW04021K18FKED" renamed to "CRCW04021K18FKED"
Component "WB_GND" renamed to "WB_GND"
Component "NPI75C120MTRF" renamed to "NPI75C120MTRF"
Component "SRN8040-330M" renamed to "SRN8040-330M"
Component "WB_BATTERY" renamed to "WB_BATTERY"
Component "GRM31CR60J107ME39L" renamed to "GRM31CR60J107ME39L"
The Symbol WB_CONTINUATION was missing a RefDes attribute, a refdes was created for the symbol.
The Symbol WB_CONTINUATION was missing a Type attribute, a type was created for the symbol.
The Symbol WB_CONTINUATION was missing a Value attribute, a value was created for the symbol.
The Symbol WB_BLOCK_IO was missing a RefDes attribute, a refdes was created for the symbol.
The Symbol WB_BLOCK_IO was missing a Type attribute, a type was created for the symbol.
The Symbol WB_BLOCK_IO was missing a Value attribute, a value was created for the symbol.
The Symbol WB_STARTUP_VOLTAGE_SOURCE was missing a RefDes attribute, a refdes was created for the symbol.
The Symbol WB_STARTUP_VOLTAGE_SOURCE was missing a Type attribute, a type was created for the symbol.
The Symbol WB_STARTUP_VOLTAGE_SOURCE was missing a Value attribute, a value was created for the symbol.
The Symbol WB_SOURCE_RESISTOR was missing a RefDes attribute, a refdes was created for the symbol.
The Symbol WB_SOURCE_RESISTOR was missing a Type attribute, a type was created for the symbol.
The Symbol WB_SOURCE_RESISTOR was missing a Value attribute, a value was created for the symbol.
The Symbol WB_PRIM_STARTUP_VOLTAGE_SOURCE was missing a RefDes attribute, a refdes was created for the symbol.
The Symbol WB_PRIM_STARTUP_VOLTAGE_SOURCE was missing a Type attribute, a type was created for the symbol.
The Symbol WB_PRIM_STARTUP_VOLTAGE_SOURCE was missing a Value attribute, a value was created for the symbol.
The Symbol WB_CURRENT_PROBE was missing a RefDes attribute, a refdes was created for the symbol.
The Symbol WB_CURRENT_PROBE was missing a Type attribute, a type was created for the symbol.
The Symbol WB_CURRENT_PROBE was missing a Value attribute, a value was created for the symbol.
The Symbol WB_PWL_CURRENT_LOAD was missing a RefDes attribute, a refdes was created for the symbol.
The Symbol WB_PWL_CURRENT_LOAD was missing a Type attribute, a type was created for the symbol.
The Symbol WB_PWL_CURRENT_LOAD was missing a Value attribute, a value was created for the symbol.
The Symbol WB_ZERO_VOLT_SOURCE was missing a RefDes attribute, a refdes was created for the symbol.
The Symbol WB_ZERO_VOLT_SOURCE was missing a Type attribute, a type was created for the symbol.
The Symbol WB_ZERO_VOLT_SOURCE was missing a Value attribute, a value was created for the symbol.
The Symbol WB_DIODE was missing a RefDes attribute, a refdes was created for the symbol.
The Symbol WB_DIODE was missing a Type attribute, a type was created for the symbol.
The Symbol WB_DIODE was missing a Value attribute, a value was created for the symbol.
The Symbol WB_N_MOSFET was missing a RefDes attribute, a refdes was created for the symbol.
The Symbol WB_N_MOSFET was missing a Type attribute, a type was created for the symbol.
The Symbol WB_N_MOSFET was missing a Value attribute, a value was created for the symbol.
The Symbol WB_ONE_STAGE_FLT was missing a RefDes attribute, a refdes was created for the symbol.
The Symbol WB_ONE_STAGE_FLT was missing a Type attribute, a type was created for the symbol.
The Symbol WB_ONE_STAGE_FLT was missing a Value attribute, a value was created for the symbol.
The Symbol WB_TWO_STAGES_FLT was missing a RefDes attribute, a refdes was created for the symbol.
The Symbol WB_TWO_STAGES_FLT was missing a Type attribute, a type was created for the symbol.
The Symbol WB_TWO_STAGES_FLT was missing a Value attribute, a value was created for the symbol.
The Symbol WB_VOLTAGE_PROBE was missing a RefDes attribute, a refdes was created for the symbol.
The Symbol WB_VOLTAGE_PROBE was missing a Type attribute, a type was created for the symbol.
The Symbol WB_VOLTAGE_PROBE was missing a Value attribute, a value was created for the symbol.
The Symbol WB_BPFILTER_VERT was missing a RefDes attribute, a refdes was created for the symbol.
The Symbol WB_BPFILTER_VERT was missing a Type attribute, a type was created for the symbol.
The Symbol WB_BPFILTER_VERT was missing a Value attribute, a value was created for the symbol.
The Symbol WB_COMPENSATION_BLOCK_TYPE1_VE was missing a RefDes attribute, a refdes was created for the symbol.
The Symbol WB_COMPENSATION_BLOCK_TYPE1_VE was missing a Type attribute, a type was created for the symbol.
The Symbol WB_COMPENSATION_BLOCK_TYPE1_VE was missing a Value attribute, a value was created for the symbol.
The Symbol WB_COMPENSATION_BLOCK_TYPE2_VE was missing a RefDes attribute, a refdes was created for the symbol.
The Symbol WB_COMPENSATION_BLOCK_TYPE2_VE was missing a Type attribute, a type was created for the symbol.
The Symbol WB_COMPENSATION_BLOCK_TYPE2_VE was missing a Value attribute, a value was created for the symbol.
The Symbol WB_COUPLED_INDUCTORS_BLOCK was missing a RefDes attribute, a refdes was created for the symbol.
The Symbol WB_COUPLED_INDUCTORS_BLOCK was missing a Type attribute, a type was created for the symbol.
The Symbol WB_COUPLED_INDUCTORS_BLOCK was missing a Value attribute, a value was created for the symbol.
The Symbol WB_INDUCTOR_COUPLED was missing a RefDes attribute, a refdes was created for the symbol.
The Symbol WB_INDUCTOR_COUPLED was missing a Type attribute, a type was created for the symbol.
The Symbol WB_INDUCTOR_COUPLED was missing a Value attribute, a value was created for the symbol.
The Symbol WB_DAMP_BRANCH was missing a RefDes attribute, a refdes was created for the symbol.
The Symbol WB_DAMP_BRANCH was missing a Type attribute, a type was created for the symbol.
The Symbol WB_DAMP_BRANCH was missing a Value attribute, a value was created for the symbol.
The Symbol WB_PRIMITIVE_CAPACITOR was missing a RefDes attribute, a refdes was created for the symbol.
The Symbol WB_PRIMITIVE_CAPACITOR was missing a Type attribute, a type was created for the symbol.
The Symbol WB_PRIMITIVE_CAPACITOR was missing a Value attribute, a value was created for the symbol.
The Symbol WB_NORBP_BLOCK was missing a RefDes attribute, a refdes was created for the symbol.
The Symbol WB_NORBP_BLOCK was missing a Type attribute, a type was created for the symbol.
The Symbol WB_NORBP_BLOCK was missing a Value attribute, a value was created for the symbol.
The Symbol WB_UNCOUPLED_INDUCTORS_BLOCK was missing a RefDes attribute, a refdes was created for the symbol.
The Symbol WB_UNCOUPLED_INDUCTORS_BLOCK was missing a Type attribute, a type was created for the symbol.
The Symbol WB_UNCOUPLED_INDUCTORS_BLOCK was missing a Value attribute, a value was created for the symbol.
The Symbol WB_PWL_VOLTAGE_SOURCE was missing a RefDes attribute, a refdes was created for the symbol.
The Symbol WB_PWL_VOLTAGE_SOURCE was missing a Type attribute, a type was created for the symbol.
The Symbol WB_PWL_VOLTAGE_SOURCE was missing a Value attribute, a value was created for the symbol.
The Symbol WB_PRIM_PWL_VOLTAGE_SOURCE was missing a RefDes attribute, a refdes was created for the symbol.
The Symbol WB_PRIM_PWL_VOLTAGE_SOURCE was missing a Type attribute, a type was created for the symbol.
The Symbol WB_PRIM_PWL_VOLTAGE_SOURCE was missing a Value attribute, a value was created for the symbol.
The Symbol WB_LOAD_RESISTOR was missing a RefDes attribute, a refdes was created for the symbol.
The Symbol WB_LOAD_RESISTOR was missing a Type attribute, a type was created for the symbol.
The Symbol WB_LOAD_RESISTOR was missing a Value attribute, a value was created for the symbol.
The Symbol WB_PRIMITIVE_BATTERY was missing a RefDes attribute, a refdes was created for the symbol.
The Symbol WB_PRIMITIVE_BATTERY was missing a Type attribute, a type was created for the symbol.
The Symbol WB_PRIMITIVE_BATTERY was missing a Value attribute, a value was created for the symbol.

Ultra Librarian Gold 8.1.44 Process Report

Message - Padstack "RX22Y24D0T" Shape(4) is a CIRCLE with no diameter.
Message - Padstack "RX45Y35D0T" Shape(4) is a CIRCLE with no diameter.
Message - Padstack "RX44Y57D0T" Shape(4) is a CIRCLE with no diameter.
Message - Padstack "RX71Y81D0T" Shape(4) is a CIRCLE with no diameter.
Message - Padstack "R10170300000202A" Shape(4) is a CIRCLE with no diameter.
Message - Padstack "R10981000004949A" Shape(4) is a CIRCLE with no diameter.
Message - Padstack "RX44Y71D0T" Shape(4) is a CIRCLE with no diameter.
Message - Padstack "RX44Y106D0T" Shape(4) is a CIRCLE with no diameter.
Message - Padstack "RX54Y18D0T" Shape(4) is a CIRCLE with no diameter.
Message - Padstack "RX118Y295D0T" Shape(4) is a CIRCLE with no diameter.
Message - Padstack "RX86p61Y314p96D0" Shape(4) is a CIRCLE with no diameter.
Message - Pattern "IND_NPI75C", entity (115-Line) is a LINE with matching start and end points.
Message - Pattern "IND_NPI75C", entity (117-Line) is a LINE with matching start and end points.
Message - Pattern "IND_NPI75C", entity (119-Line) is a LINE with matching start and end points.
Message - Pattern "IND_NPI75C", entity (121-Line) is a LINE with matching start and end points.
Message - Component "GRM155R61A104KA01D" attribute "Cap" references text style "" that is not in the database.
The default pattern text style "H50s3" was substituted.
Message - Component "GRM155R61A104KA01D" attribute "ESR" references text style "" that is not in the database.
The default pattern text style "H50s3" was substituted.
Message - Component "GRM155R61A104KA01D" attribute "IRMS" references text style "" that is not in the database.
The default pattern text style "H50s3" was substituted.
Message - Component "GRM155R61A104KA01D" attribute "VDC" references text style "" that is not in the database.
The default pattern text style "H50s3" was substituted.
Message - Component "10TPU4R7MSI" attribute "Datasheet URL" references text style "" that is not in the database.
The default pattern text style "H50s3" was substituted.
Message - Component "10TPU4R7MSI" attribute "Cap" references text style "" that is not in the database.
The default pattern text style "H50s3" was substituted.
Message - Component "10TPU4R7MSI" attribute "ESR" references text style "" that is not in the database.
The default pattern text style "H50s3" was substituted.
Message - Component "10TPU4R7MSI" attribute "IRMS" references text style "" that is not in the database.
The default pattern text style "H50s3" was substituted.
Message - Component "10TPU4R7MSI" attribute "VDC" references text style "" that is not in the database.
The default pattern text style "H50s3" was substituted.
Message - Component "CL21C122JBFNNWE" attribute "Datasheet URL" references text style "" that is not in the database.
The default pattern text style "H50s3" was substituted.
Message - Component "CL21C122JBFNNWE" attribute "Cap" references text style "" that is not in the database.
The default pattern text style "H50s3" was substituted.
Message - Component "CL21C122JBFNNWE" attribute "ESR" references text style "" that is not in the database.
The default pattern text style "H50s3" was substituted.
Message - Component "CL21C122JBFNNWE" attribute "IRMS" references text style "" that is not in the database.
The default pattern text style "H50s3" was substituted.
Message - Component "CL21C122JBFNNWE" attribute "VDC" references text style "" that is not in the database.
The default pattern text style "H50s3" was substituted.
Message - Component "GRM21BR71A225KA01L" attribute "Cap" references text style "" that is not in the database.
The default pattern text style "H50s3" was substituted.
Message - Component "GRM21BR71A225KA01L" attribute "ESR" references text style "" that is not in the database.
The default pattern text style "H50s3" was substituted.
Message - Component "GRM21BR71A225KA01L" attribute "IRMS" references text style "" that is not in the database.
The default pattern text style "H50s3" was substituted.
Message - Component "GRM21BR71A225KA01L" attribute "VDC" references text style "" that is not in the database.
The default pattern text style "H50s3" was substituted.
Message - Component "B220-13-F" attribute "Datasheet URL" references text style "" that is not in the database.
The default pattern text style "H50s3" was substituted.
Message - Component "B220-13-F" attribute "Io" references text style "" that is not in the database.
The default pattern text style "H50s3" was substituted.
Message - Component "B220-13-F" attribute "VRRM" references text style "" that is not in the database.
The default pattern text style "H50s3" was substituted.
Message - Component "B220-13-F" attribute "VFatIo" references text style "" that is not in the database.
The default pattern text style "H50s3" was substituted.
Message - Component "GRM2195C1H512JA01D" attribute "Cap" references text style "" that is not in the database.
The default pattern text style "H50s3" was substituted.
Message - Component "GRM2195C1H512JA01D" attribute "ESR" references text style "" that is not in the database.
The default pattern text style "H50s3" was substituted.
Message - Component "GRM2195C1H512JA01D" attribute "IRMS" references text style "" that is not in the database.
The default pattern text style "H50s3" was substituted.
Message - Component "GRM2195C1H512JA01D" attribute "VDC" references text style "" that is not in the database.
The default pattern text style "H50s3" was substituted.
Message - Component "CSD17308Q3" attribute "Datasheet URL" references text style "" that is not in the database.
The default pattern text style "H50s3" was substituted.
Message - Component "CSD17308Q3" attribute "VdsMax" references text style "" that is not in the database.
The default pattern text style "H50s3" was substituted.
Message - Component "CSD17308Q3" attribute "IdsMax" references text style "" that is not in the database.
The default pattern text style "H50s3" was substituted.
Message - Component "CSD17308Q3" attribute "Rdson45" references text style "" that is not in the database.
The default pattern text style "H50s3" was substituted.
Message - Component "CSD17308Q3" attribute "QgTyp" references text style "" that is not in the database.
The default pattern text style "H50s3" was substituted.
Message - Component "CSD17308Q3" attribute "Quantity" references text style "" that is not in the database.
The default pattern text style "H50s3" was substituted.
Message - Component "CRCW040269K8FKED" attribute "Resistance" references text style "" that is not in the database.
The default pattern text style "H50s3" was substituted.
Message - Component "CRCW040269K8FKED" attribute "Power" references text style "" that is not in the database.
The default pattern text style "H50s3" was substituted.
Message - Component "CRCW040269K8FKED" attribute "Tolerance" references text style "" that is not in the database.
The default pattern text style "H50s3" was substituted.
Message - Component "CRCW040210K0FKED" attribute "Resistance" references text style "" that is not in the database.
The default pattern text style "H50s3" was substituted.
Message - Component "CRCW040210K0FKED" attribute "Power" references text style "" that is not in the database.
The default pattern text style "H50s3" was substituted.
Message - Component "CRCW040210K0FKED" attribute "Tolerance" references text style "" that is not in the database.
The default pattern text style "H50s3" was substituted.
Message - Component "CRCW040216K2FKED" attribute "Resistance" references text style "" that is not in the database.
The default pattern text style "H50s3" was substituted.
Message - Component "CRCW040216K2FKED" attribute "Power" references text style "" that is not in the database.
The default pattern text style "H50s3" was substituted.
Message - Component "CRCW040216K2FKED" attribute "Tolerance" references text style "" that is not in the database.
The default pattern text style "H50s3" was substituted.
Message - Component "CRCW0402100RFKED" attribute "Resistance" references text style "" that is not in the database.
The default pattern text style "H50s3" was substituted.
Message - Component "CRCW0402100RFKED" attribute "Power" references text style "" that is not in the database.
The default pattern text style "H50s3" was substituted.
Message - Component "CRCW0402100RFKED" attribute "Tolerance" references text style "" that is not in the database.
The default pattern text style "H50s3" was substituted.
Message - Component "ERJ-L14KF33MU" attribute "Resistance" references text style "" that is not in the database.
The default pattern text style "H50s3" was substituted.
Message - Component "ERJ-L14KF33MU" attribute "Power" references text style "" that is not in the database.
The default pattern text style "H50s3" was substituted.
Message - Component "ERJ-L14KF33MU" attribute "Tolerance" references text style "" that is not in the database.
The default pattern text style "H50s3" was substituted.
Message - Component "LM3488MMX/NOPB" attribute "Datasheet URL" references text style "" that is not in the database.
The default pattern text style "H50s3" was substituted.
Message - Component "LM3488MMX/NOPB" attribute "Frequency" references text style "" that is not in the database.
The default pattern text style "H50s3" was substituted.
Message - Component "LM3488MMX/NOPB" attribute "Imax" references text style "" that is not in the database.
The default pattern text style "H50s3" was substituted.
Message - Component "LM3488MMX/NOPB" attribute "Package" references text style "" that is not in the database.
The default pattern text style "H50s3" was substituted.
Message - Component "LM3488MMX/NOPB" attribute "Mktg_Package" references text style "" that is not in the database.
The default pattern text style "H50s3" was substituted.
Message - Component "LM3488MMX/NOPB" attribute "NSID" references text style "" that is not in the database.
The default pattern text style "H50s3" was substituted.
Message - Component "CRCW040220R0FKED" attribute "Resistance" references text style "" that is not in the database.
The default pattern text style "H50s3" was substituted.
Message - Component "CRCW040220R0FKED" attribute "Power" references text style "" that is not in the database.
The default pattern text style "H50s3" was substituted.
Message - Component "CRCW040220R0FKED" attribute "Tolerance" references text style "" that is not in the database.
The default pattern text style "H50s3" was substituted.
Message - Component "GRM155R61A823KA01D" attribute "Cap" references text style "" that is not in the database.
The default pattern text style "H50s3" was substituted.
Message - Component "GRM155R61A823KA01D" attribute "ESR" references text style "" that is not in the database.
The default pattern text style "H50s3" was substituted.
Message - Component "GRM155R61A823KA01D" attribute "IRMS" references text style "" that is not in the database.
The default pattern text style "H50s3" was substituted.
Message - Component "GRM155R61A823KA01D" attribute "VDC" references text style "" that is not in the database.
The default pattern text style "H50s3" was substituted.
Message - Component "CRCW04021K18FKED" attribute "Resistance" references text style "" that is not in the database.
The default pattern text style "H50s3" was substituted.
Message - Component "CRCW04021K18FKED" attribute "Power" references text style "" that is not in the database.
The default pattern text style "H50s3" was substituted.
Message - Component "CRCW04021K18FKED" attribute "Tolerance" references text style "" that is not in the database.
The default pattern text style "H50s3" was substituted.
Message - Component "NPI75C120MTRF" attribute "L" references text style "" that is not in the database.
The default pattern text style "H50s3" was substituted.
Message - Component "NPI75C120MTRF" attribute "DCR" references text style "" that is not in the database.
The default pattern text style "H50s3" was substituted.
Message - Component "NPI75C120MTRF" attribute "IDC" references text style "" that is not in the database.
The default pattern text style "H50s3" was substituted.
Message - Component "SRN8040-330M" attribute "Datasheet URL" references text style "" that is not in the database.
The default pattern text style "H50s3" was substituted.
Message - Component "SRN8040-330M" attribute "L" references text style "" that is not in the database.
The default pattern text style "H50s3" was substituted.
Message - Component "SRN8040-330M" attribute "DCR" references text style "" that is not in the database.
The default pattern text style "H50s3" was substituted.
Message - Component "SRN8040-330M" attribute "IDC" references text style "" that is not in the database.
The default pattern text style "H50s3" was substituted.
Message - Component "GRM31CR60J107ME39L" attribute "Cap" references text style "" that is not in the database.
The default pattern text style "H50s3" was substituted.
Message - Component "GRM31CR60J107ME39L" attribute "ESR" references text style "" that is not in the database.
The default pattern text style "H50s3" was substituted.
Message - Component "GRM31CR60J107ME39L" attribute "IRMS" references text style "" that is not in the database.
The default pattern text style "H50s3" was substituted.
Message - Component "GRM31CR60J107ME39L" attribute "VDC" references text style "" that is not in the database.
The default pattern text style "H50s3" was substituted.

TextStyle count:  24
Padstack count:   11
Pattern count:    10
Symbol count:     36
Component count:  22

Export

Footprint "WB_CURRENT_LOAD" has no layer data mapped and will be skipped.
Component "WB_CURRENT_LOAD" requires footprint "WB_CURRENT_LOAD" and will be skipped.
Footprint "WB_GND" has no layer data mapped and will be skipped.
Component "WB_GND" requires footprint "WB_GND" and will be skipped.
Footprint "WB_BATTERY" has no layer data mapped and will be skipped.
Component "WB_BATTERY" requires footprint "WB_BATTERY" and will be skipped.

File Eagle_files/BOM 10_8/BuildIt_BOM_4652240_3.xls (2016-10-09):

Part Number | Manufacturer | Component | Footprint | Quantity Available | Qty Req Per Kit | Order Multiple | Quantity Ordered | Prototype Price | Total
CL21C122JBFNNWE | Samsung Electro-Mechanics | Cramp | 0805 | > 10 | 1 | 1 | 1 | $ 0.10 | $ 0.10
SRN8040-330M | Bourns | Lout | SRN8040 | > 10 | 1 | 1 | 1 | $ 0.58 | $ 0.58
CRCW040216K2FKED | Vishay-Dale | Rfb2 | 0402 | > 10 | 1 | 1 | 1 | $ 0.10 | $ 0.10
CRCW040210K0FKED | Vishay-Dale | Rfb1 | 0402 | > 10 | 1 | 1 | 1 | $ 0.10 | $ 0.10
GRM2195C1H512JA01D | MuRata | Ccomp2 | 0805 | > 10 | 1 | 1 | 1 | $ 0.27 | $ 0.27
ERJ-L14KF33MU | Panasonic | Rsense | 1210 | > 10 | 1 | 1 | 1 | $ 0.78 | $ 0.78
GRM21BR71A225KA01L | MuRata | Csep | 0805 | > 10 | 1 | 1 | 1 | $ 0.16 | $ 0.16
GRM31CR60J107ME39L | MuRata | Cout | 1206_190 | > 10 | 2 | 1 | 2 | $ 0.60 | $ 1.20
10TPU4R7MSI | Panasonic | Cin | CAPSMT_6_S09 | > 10 | 1 | 1 | 1 | $ 1.18 | $ 1.18
NPI75C120MTRF | NIC Components | Lin | IND_NPI75C | Unavailable | 1 | 1 | 0 | $ 0.00 | $ 0.00
CSD17308Q3 | Texas Instruments | M1 | DQG0008A | > 10 | 1 | 1 | 1 | $ 0.86 | $ 0.86
CRCW040269K8FKED | Vishay-Dale | Rfadj | 0402 | > 10 | 1 | 1 | 1 | $ 0.10 | $ 0.10
GRM155R61A104KA01D | MuRata | Cbp | 0402 | > 10 | 1 | 1 | 1 | $ 0.10 | $ 0.10
B220-13-F | Diodes Inc. | D1 | SMB | > 10 | 1 | 1 | 1 | $ 0.47 | $ 0.47
CRCW040220R0FKED | Vishay-Dale | Rbp | 0402 | > 10 | 1 | 1 | 1 | $ 0.10 | $ 0.10
CRCW04021K18FKED | Vishay-Dale | Rcomp | 0402 | > 10 | 1 | 1 | 1 | $ 0.10 | $ 0.10
CRCW0402100RFKED | Vishay-Dale | Rramp | 0402 | > 10 | 1 | 1 | 1 | $ 0.10 | $ 0.10
GRM155R61A823KA01D | MuRata | Ccomp | 0402 | > 10 | 1 | 1 | 1 | $ 0.10 | $ 0.10
LM3488MMX/NOPB | Texas Instruments | U1 | MUA08A | > 10 | 1 | 1 | 1 | $ 2.19 | $ 2.19

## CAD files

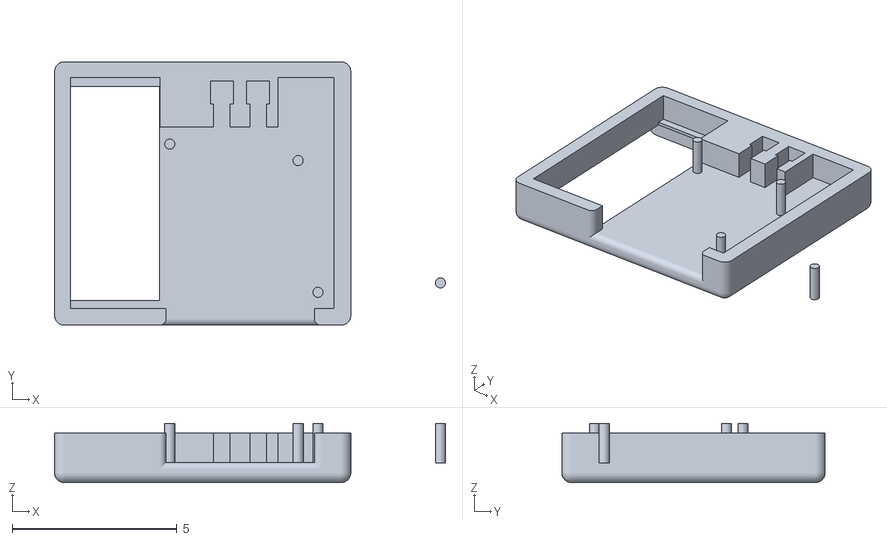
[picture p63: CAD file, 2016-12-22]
autocad/case_bottom_new.stl
11.9 x 8.00 x 1.80

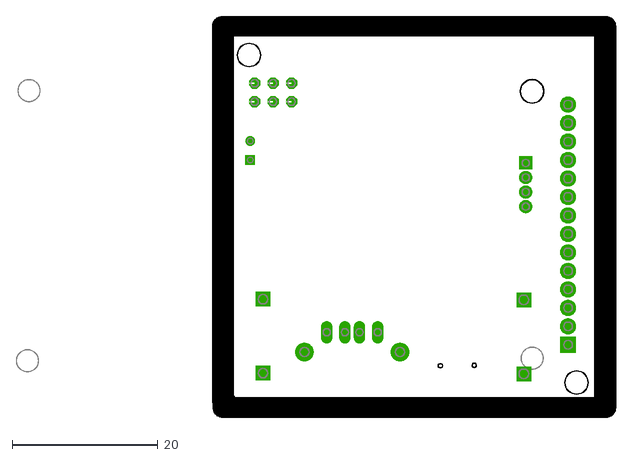
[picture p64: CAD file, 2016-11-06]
Eagle_files/Final Project Designs_v1.dxf
82.4 x 55.1

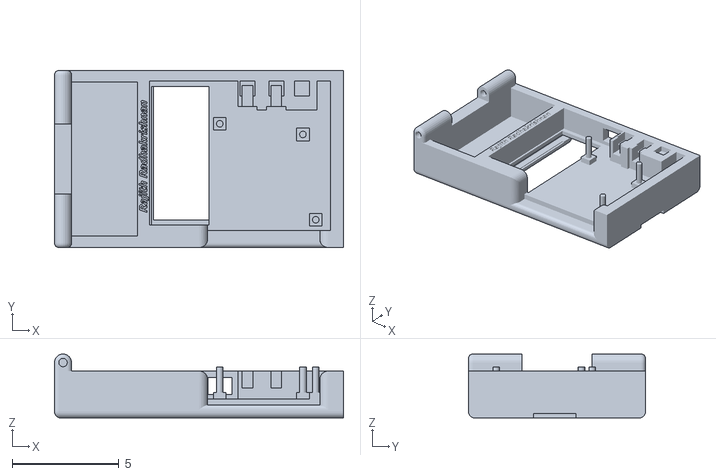
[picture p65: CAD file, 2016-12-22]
autocad/case_bottom_1.stl
13.6 x 8.30 x 3.00

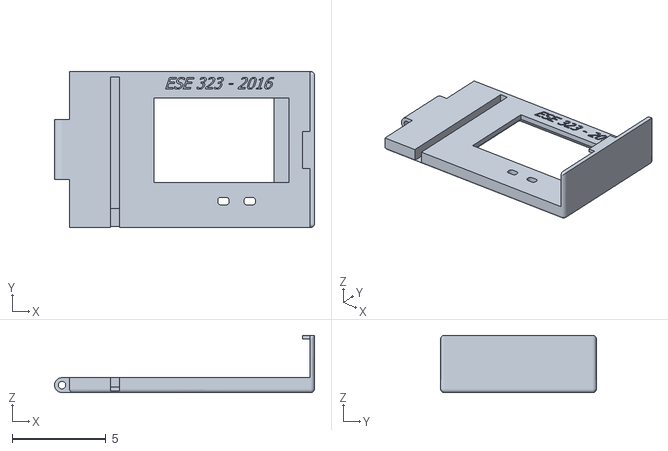
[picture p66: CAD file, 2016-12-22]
autocad/case top_new.stl
13.9 x 8.30 x 3.05

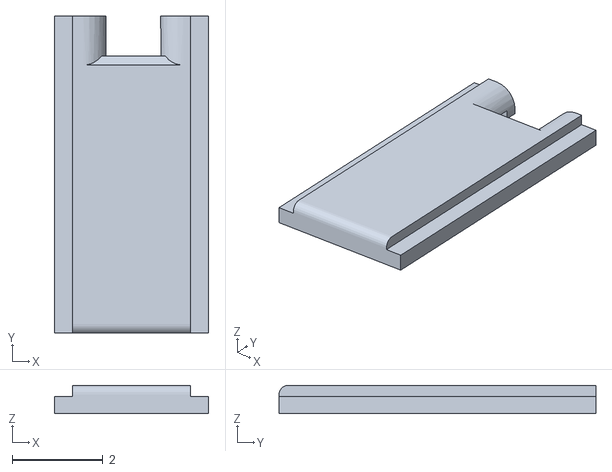
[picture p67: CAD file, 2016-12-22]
autocad/battery_cover.stl
3.40 x 6.98 x 0.62

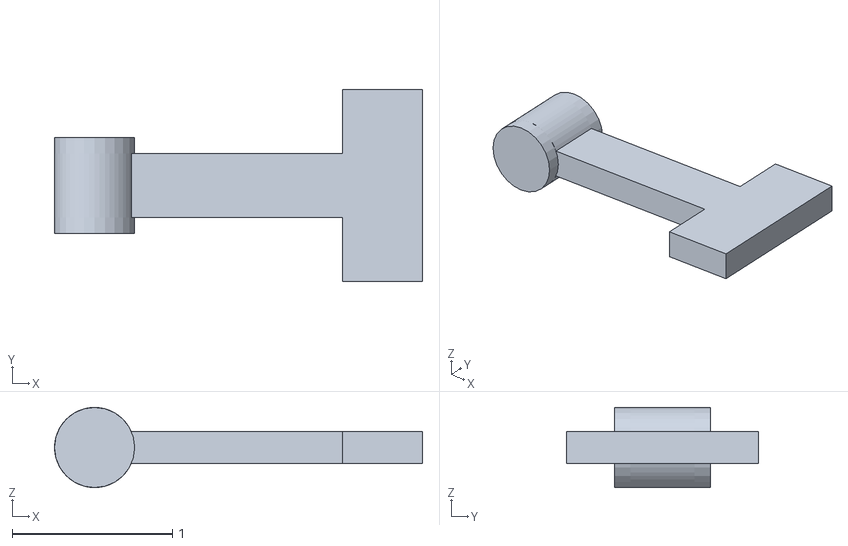
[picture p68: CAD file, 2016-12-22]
autocad/button_press_new.stl
2.29 x 1.20 x 0.5

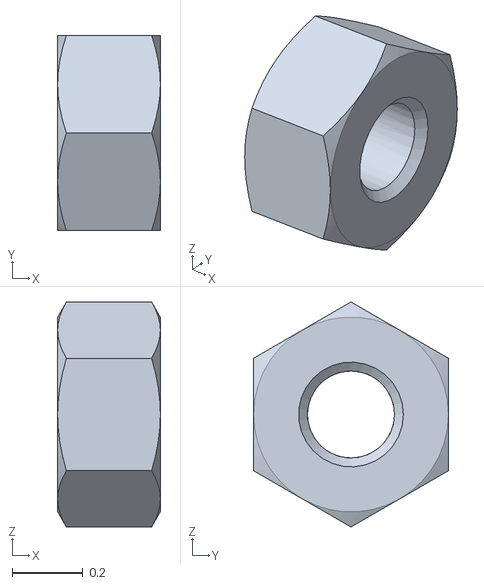
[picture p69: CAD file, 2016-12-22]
autocad/ANSI B18.2.4.2M - M3x0.5 - 5.5.stl
0.29 x 0.55 x 0.635

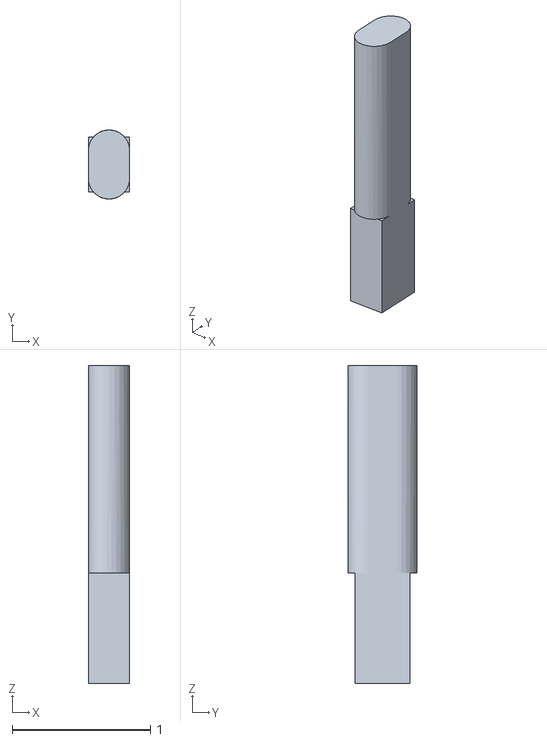
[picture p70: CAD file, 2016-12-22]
autocad/button_press.stl
0.3 x 0.5 x 2.30

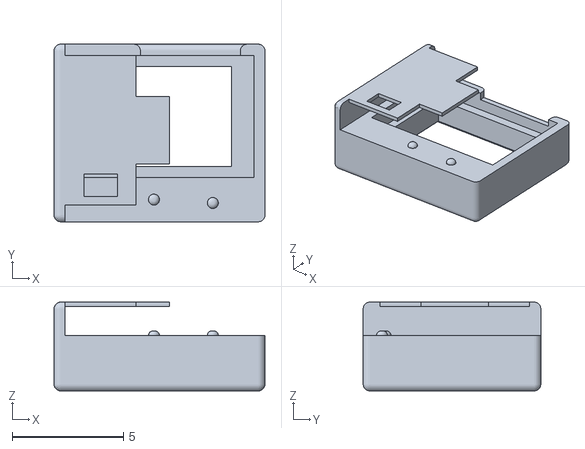
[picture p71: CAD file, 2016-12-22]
autocad/case top.stl
9.50 x 8.00 x 4.00

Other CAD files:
autocad/Assembly1.iam
autocad/Assemblylatest.iam
autocad/OldVersions/assembly.0008.iam
autocad/OldVersions/assembly_testing lcd.0001.iam
autocad/OldVersions/battery.0003.ipt
autocad/OldVersions/battery_cover.0002.ipt
autocad/OldVersions/button_press.0006.ipt
autocad/OldVersions/button_press_new.0002.ipt
autocad/OldVersions/case top.0002.ipt
autocad/OldVersions/case top_new.0004.ipt
autocad/OldVersions/case_bottom.0016.ipt
autocad/OldVersions/case_bottom_new.0007.ipt
autocad/OldVersions/lab 04.0015.ipt
autocad/OldVersions/lcd display.0001.ipt
autocad/assembly.iam
autocad/assembly.ipn
autocad/assembly_testing lcd.iam
autocad/battery.ipt
autocad/battery_cover.ipt
autocad/button_press.ipt
autocad/button_press_fitting_new.ipt
autocad/button_press_new.ipt
autocad/case top.ipt
autocad/case top_new.ipt
autocad/case_bottom.ipt
autocad/case_bottom_new.ipt
autocad/lab 04.ipt
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

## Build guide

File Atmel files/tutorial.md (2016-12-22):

#Tutorial

open up the atmel studio 

If the device is not already setup, click tools

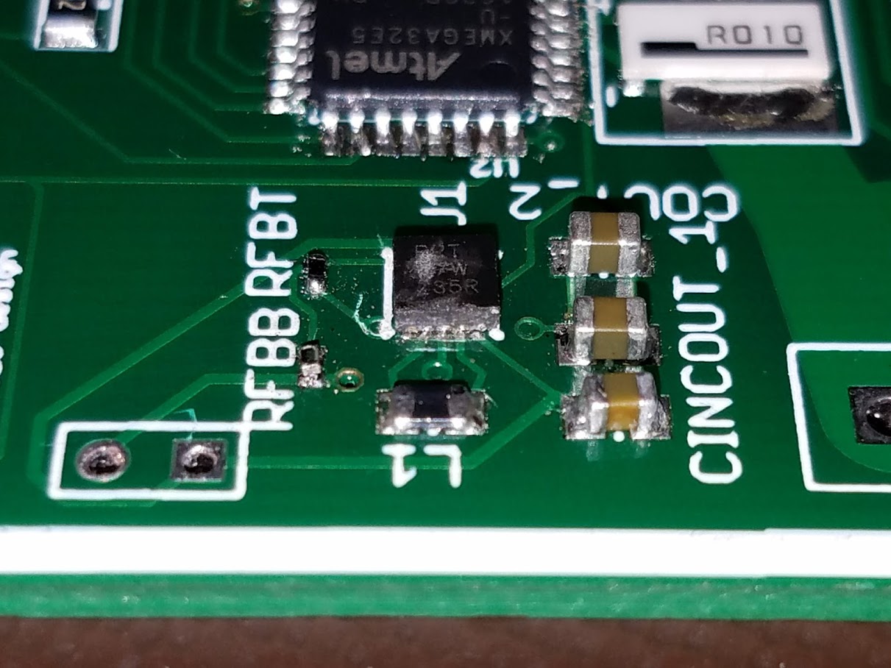
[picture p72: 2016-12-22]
Pictures/PCB_assembly/sps1.jpg

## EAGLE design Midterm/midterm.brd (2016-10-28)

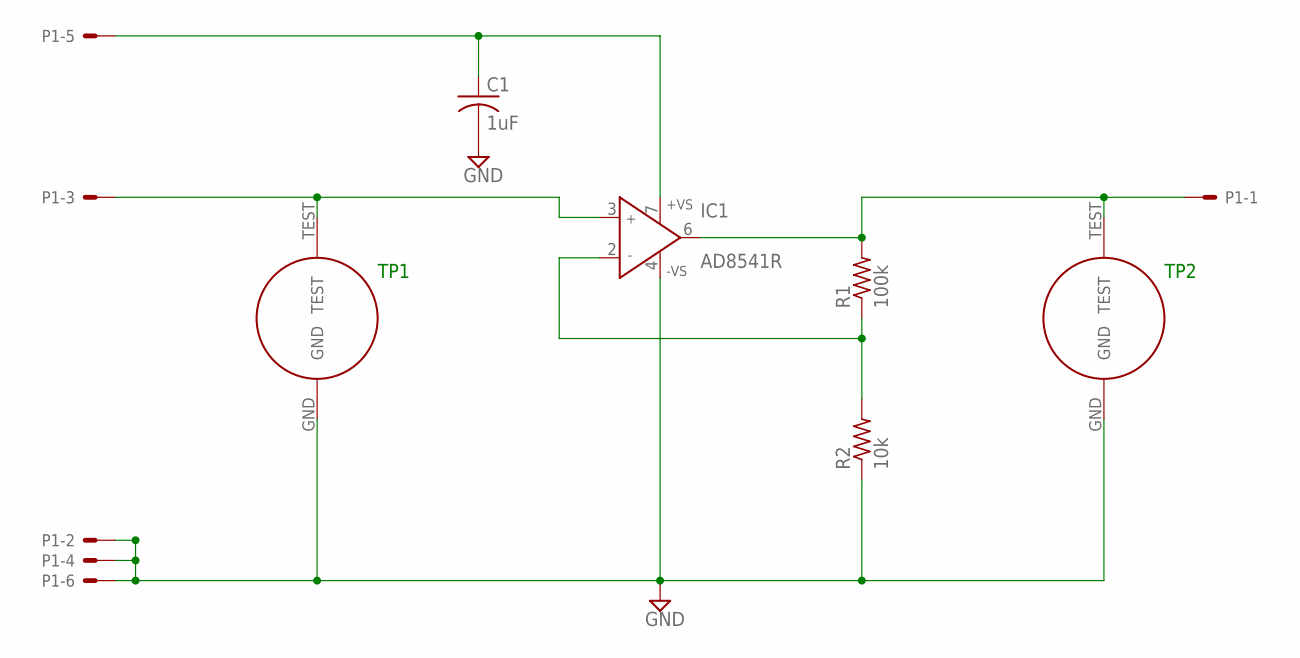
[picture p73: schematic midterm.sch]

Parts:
C1: 1uF; C1206
IC1: AD8541R; SO8
P1: 22-23-2061
R1: 100k; M2012
R2: 10k; M2012
TP1, TP2: TEST_POINT

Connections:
GND: C1.2, IC1.4 (-VS), P1.2, P1.4, P1.6, R2.1, TP1.GND, TP2.GND
unnamed: C1.1, IC1.7 (+VS), P1.5
unnamed: IC1.3 (IN+), P1.3, TP1.TEST
unnamed: IC1.2 (IN-), R1.1, R2.2
unnamed: IC1.6 (OUT), P1.1, R1.2, TP2.TEST

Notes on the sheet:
TP1
TP2

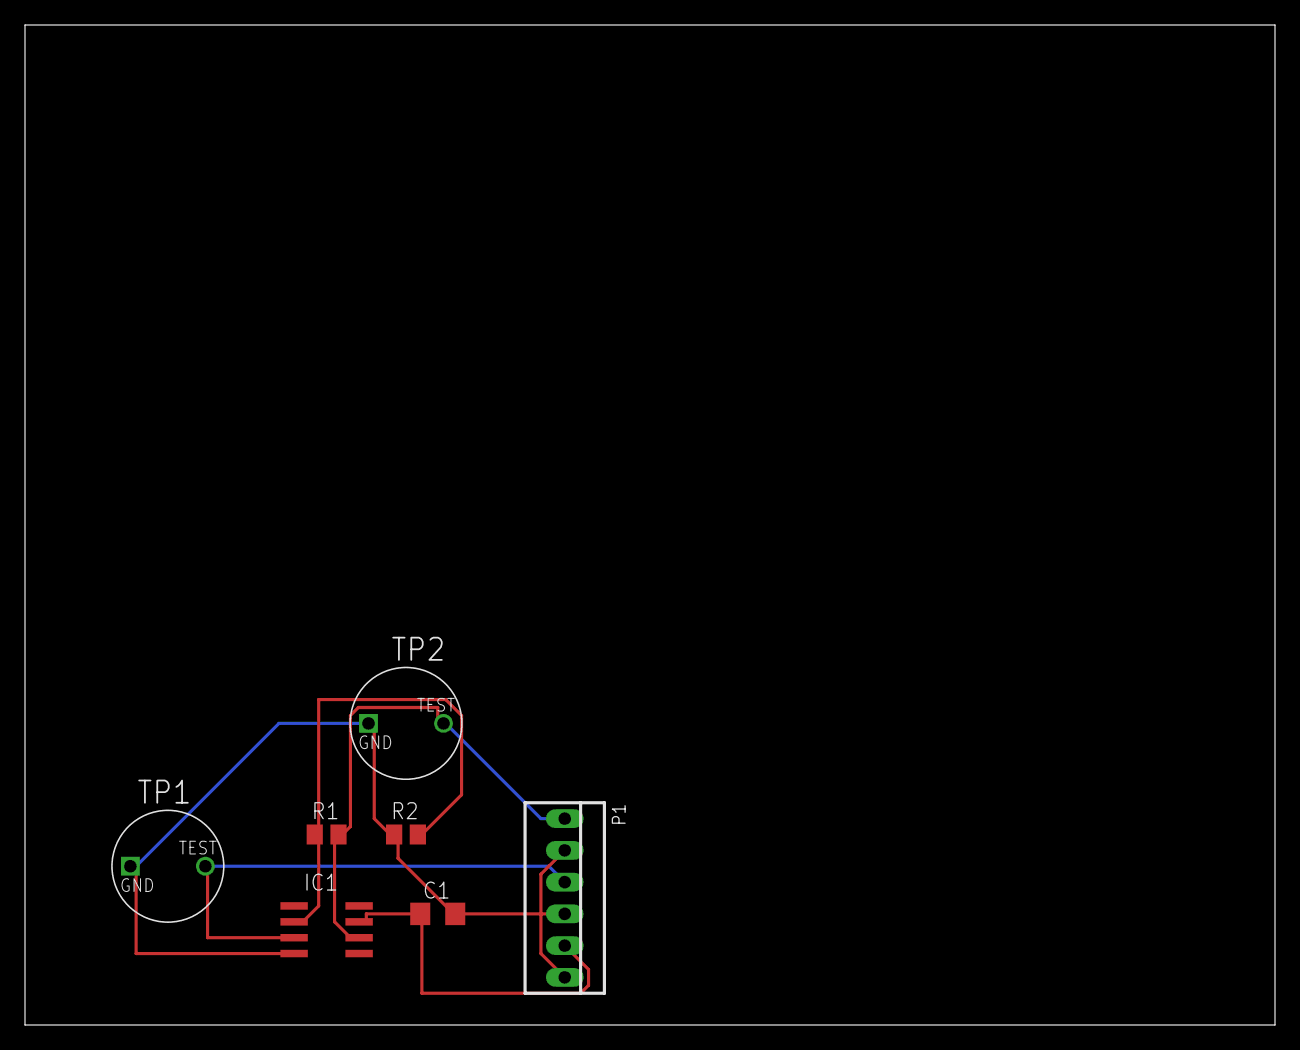
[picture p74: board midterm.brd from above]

Board: 2 copper layers, 100.0 x 80.0 mm, 7 parts (0 on the bottom side), 5 nets.

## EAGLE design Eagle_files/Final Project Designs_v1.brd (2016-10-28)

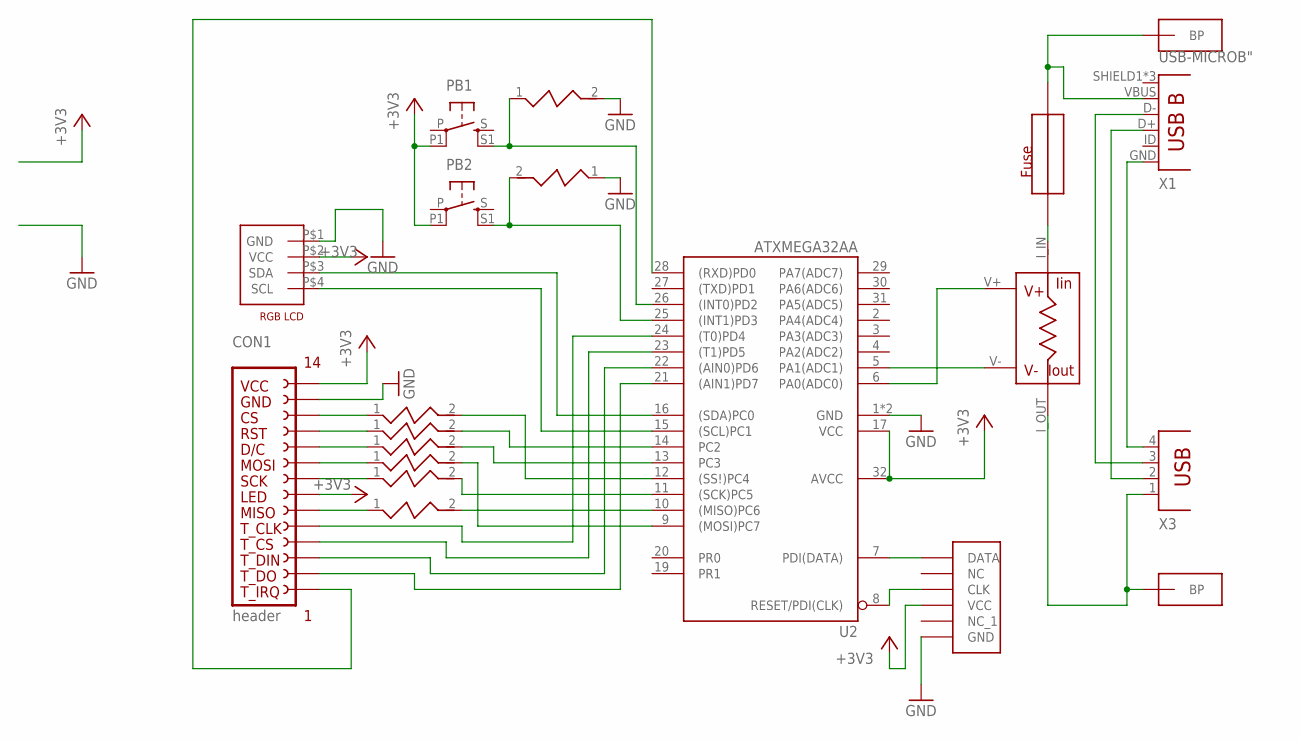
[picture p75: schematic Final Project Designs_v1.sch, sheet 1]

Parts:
CON1: header; FE15
CON2: 4PIN_GROVE_CONNECTORUNIVERSAL_4_PIN_CONNECTOR; RGB_LCD
F1: FUSE_SMT
PB1, PB2: 10-XX-4.5SMD; BT4.5X4.5
R1: RESISTOR_4PIN
R2, R3, R4, R5, R6, R7, R8, R9: RESISTOR
U2: ATXMEGA32AA; TQFP32-08
X1: USB-MICROB"; USB-B-MICRO-SMD_V03
X3: PN87520
X4: JTAG
X5, X6: BANANA_PLUG

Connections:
+3V3: CON1.P$7 (LED), CON1.P$14 (VCC), CON2.P$2 (VCC), PB1.P1, PB2.P1, U2.17 (VCC), U2.32 (AVCC), X4.VCC
B$2: R1.I_OUT, X3.1, X5.P$1, X5.P$2
GND: CON1.P$13 (GND), CON2.P$1 (GND), R8.2, R9.1, U2.1 (GND), U2.18 (GND), X4.GND; also elsewhere on the board
unnamed: R5.2, U2.9 ((MOSI)PC7)
unnamed: R6.2, U2.11 ((SCK)PC5)
unnamed: CON1.P$9 (MOSI), R5.1
unnamed: CON2.P$4 (SCL), U2.15 ((SCL)PC1)
unnamed: CON2.P$3 (SDA), U2.16 ((SDA)PC0)
unnamed: X1.GND, X3.4
unnamed: X1.D+, X3.2
unnamed: X1.D-, X3.3
unnamed: PB2.S1, R9.2, U2.25 ((INT1)PD3)
unnamed: PB1.S1, R8.1, U2.26 ((INT0)PD2)
unnamed: R2.2, U2.12 ((SS!)PC4)
unnamed: U2.7 (PDI(DATA)), X4.DATA
unnamed: U2.8 (RESET/PDI(CLK)), X4.CLK
unnamed: R1.V+, U2.6 (PA0(ADC0))
unnamed: R1.V-, U2.5 (PA1(ADC1))
unnamed: F1.P$2, R1.I_IN
unnamed: CON1.P$10 (D/C), R4.1
unnamed: CON1.P$11 (RESET), R3.1
unnamed: CON1.P$6 (MISO), R7.1
unnamed: R7.2, U2.10 ((MISO)PC6)
unnamed: CON1.P$8 (SCK), R6.1
unnamed: CON1.P$12 (CS), R2.1
unnamed: F1.P$1, X1.VBUS, X6.P$1, X6.P$2
unnamed: CON1.P$5 (T_CLK), U2.24 ((T0)PD4)
unnamed: CON1.P$4 (T_CS), U2.23 ((T1)PD5)
unnamed: CON1.P$3 (T_DIN), U2.22 ((AIN0)PD6)
unnamed: CON1.P$2 (T_DO), U2.21 ((AIN1)PD7)
unnamed: R3.2, U2.14 (PC2)
unnamed: R4.2, U2.13 (PC3)
unnamed: CON1.P$1 (T_IRQ), U2.28 ((RXD)PD0)

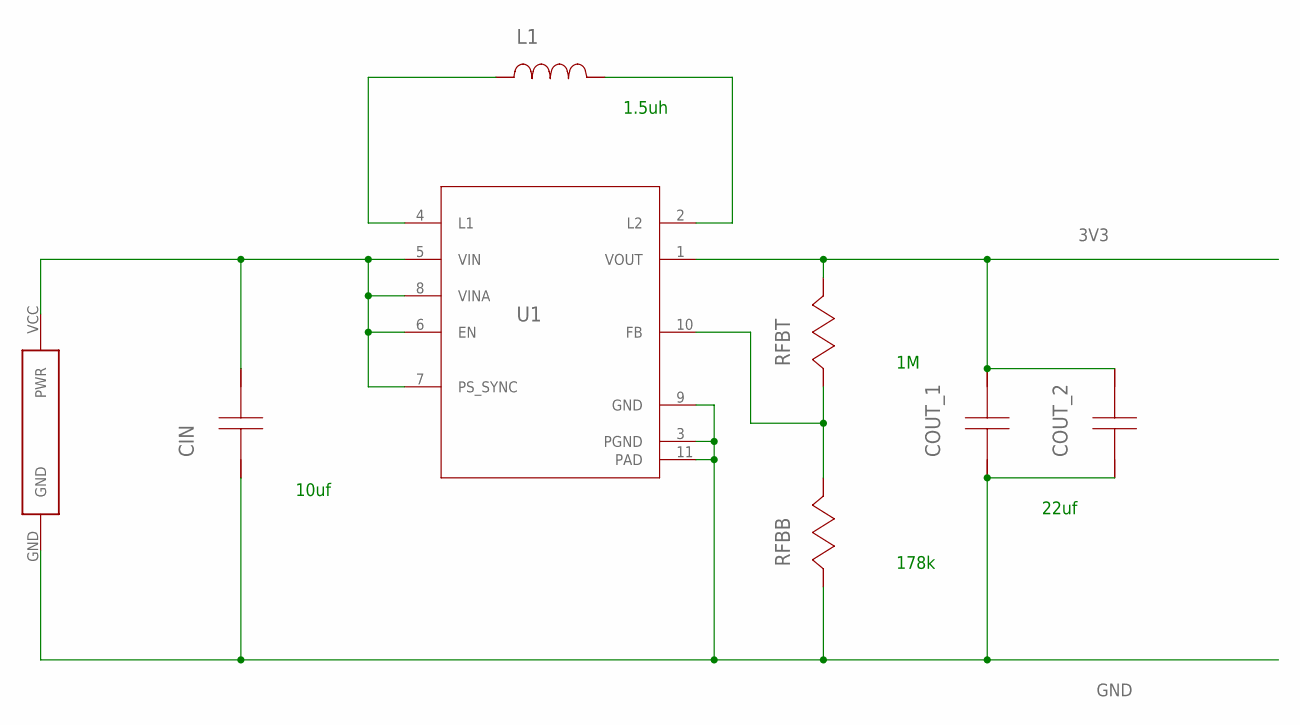
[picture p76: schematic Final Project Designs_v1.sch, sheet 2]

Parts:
CIN: LMK212BJ106KG-T; 0805
COUT_1, COUT_2: LMK212BJ226MG-T; 0805
L1: LQM21PN1R5MC0D; 0805
RFBB: CRCW0402178KFKED; 0402
RFBT: CRCW04021M00FKED; 0402
U1: TPS63000DRCR; DRC0010J
U$1: BATTERY

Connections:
2: L1.1, U1.4 (L1)
3V3: COUT_1.1, COUT_2.1, RFBT.1, U1.1 (VOUT)
4: L1.2, U1.2 (L2)
GND: CIN.2, COUT_1.2, COUT_2.2, RFBB.2, U1.3 (PGND), U1.9 (GND), U1.11 (PAD), U$1.GND; also elsewhere on the board
unnamed: RFBB.1, RFBT.2, U1.10 (FB)
VIN: CIN.1, U1.5 (VIN), U1.6 (EN), U1.7 (PS_SYNC), U1.8 (VINA), U$1.VCC (PWR)

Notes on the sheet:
10uf
22uf
1.5uh
178k

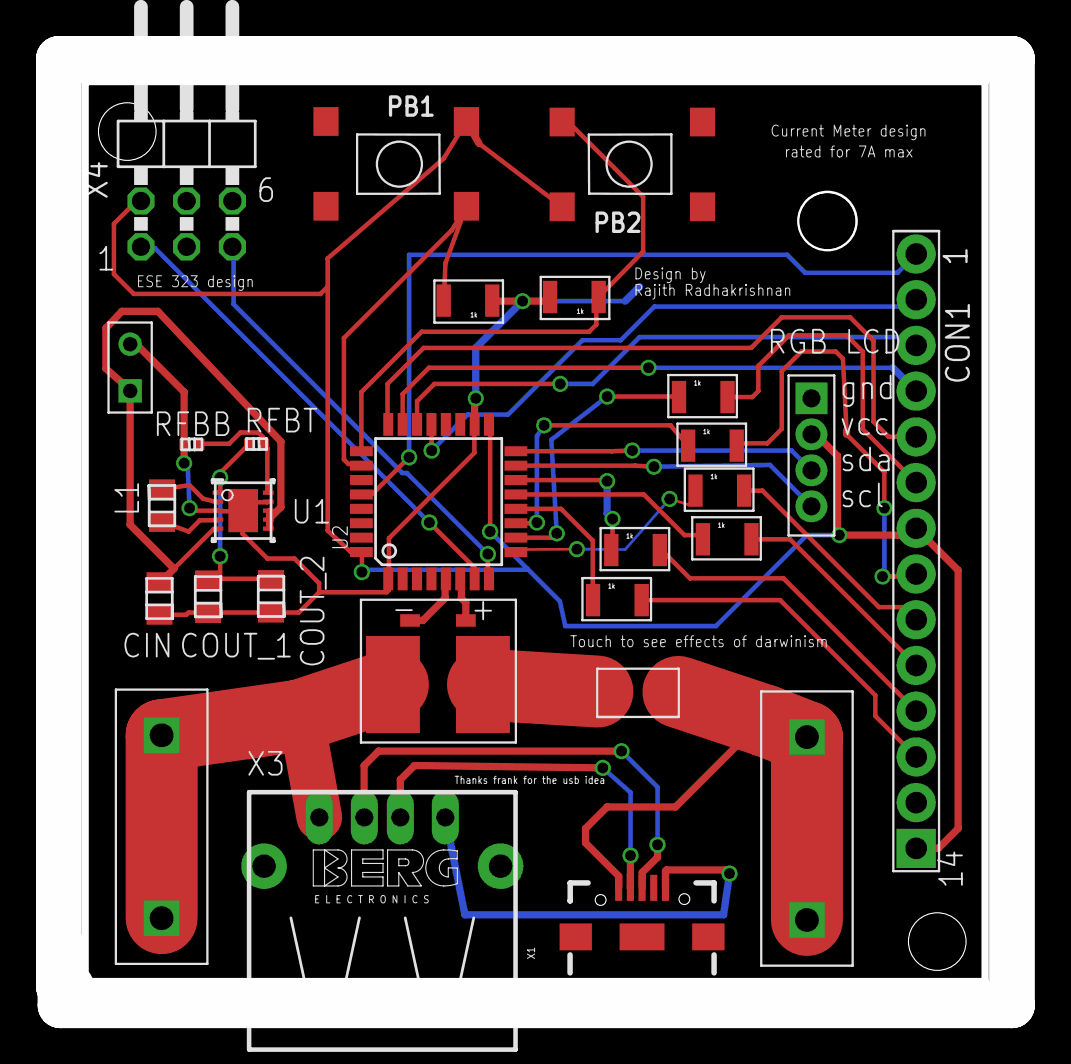
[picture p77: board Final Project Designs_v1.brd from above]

Board: 2 copper layers, 52.9 x 52.6 mm, 28 parts (0 on the bottom side), 38 nets.

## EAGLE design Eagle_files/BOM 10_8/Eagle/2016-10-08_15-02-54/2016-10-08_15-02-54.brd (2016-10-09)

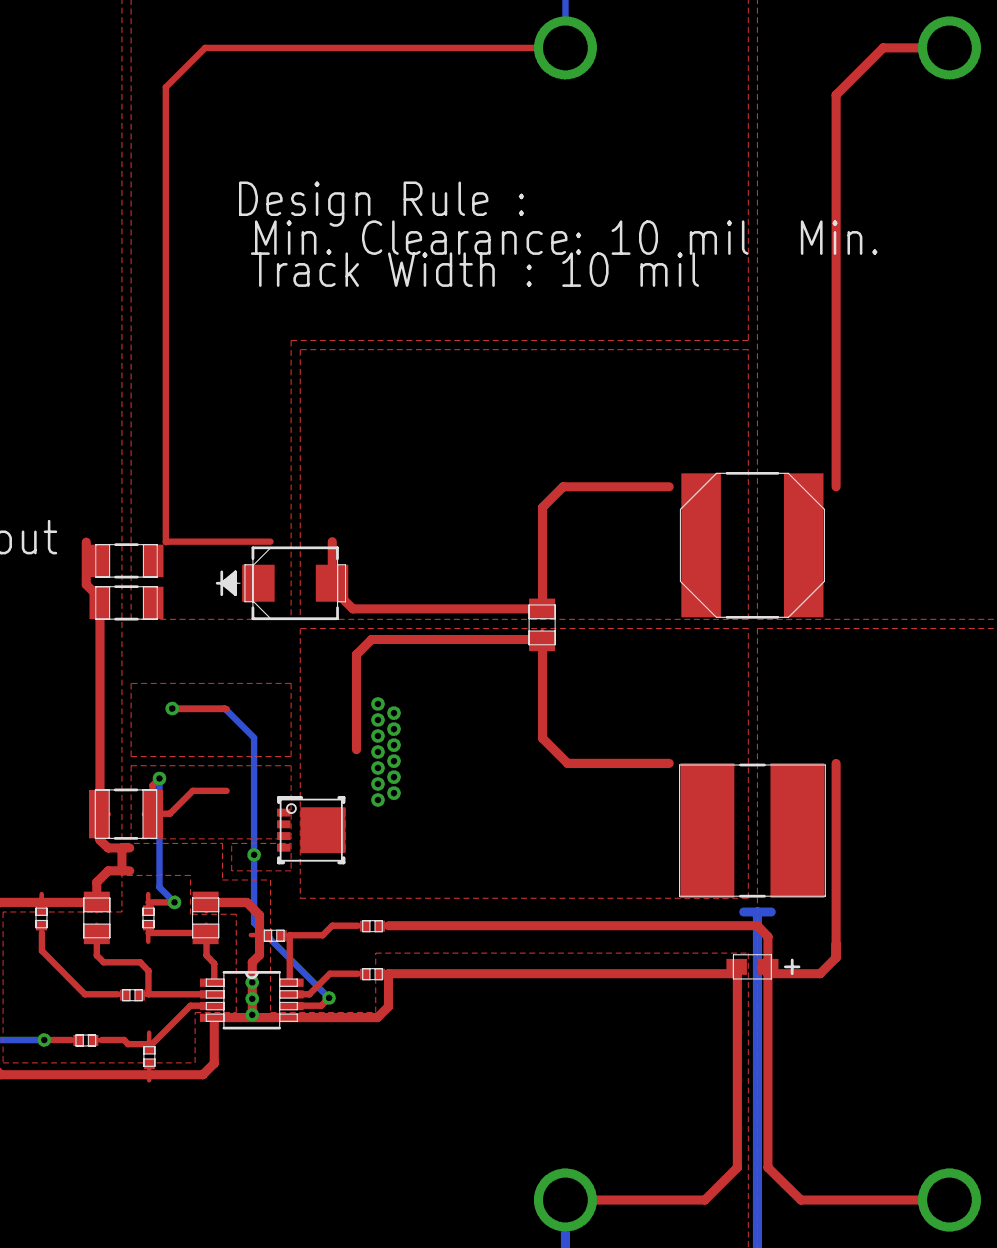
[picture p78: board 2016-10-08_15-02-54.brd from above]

Board: 4 copper layers, 24 parts (0 on the bottom side), 13 nets.

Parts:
Cbp: 0402
Ccomp: 0402
Ccomp2: 0805
Cin: CAPSMT_6_S09
Cout_1, Cout_2: 1206_190
Cramp: 0805
Csep: 0805
D1: SMB
GND, GND1: TP-1502
Lin: IND_NPI75C
Lout: SRN8040
M1: DQG0008A
Rbp: 0402
Rcomp: 0402
Rfadj: 0402
Rfb1, Rfb2: 0402
Rramp: 0402
Rsense: 1210
U1: MUA08A
VIN: TP-1502
VOUT: TP-1502

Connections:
0: Cbp.2, Ccomp.2, Ccomp2.2, Cin.2, Cout_1.2, Cout_2.2, Cramp.2, GND.1, GND1.1, Lout.2, Rfadj.1, Rfb1.2, Rsense.2, U1.4, U1.5
2: Cout_1.1, Cout_2.1, D1.1, Rfb2.1, VOUT.1
3: Cin.1, Lin.2, Rbp.1, VIN.1
4: Ccomp2.1, Rcomp.1, U1.2
5: Csep.1, D1.2, Lout.1
7: Cbp.1, Rbp.2, U1.8
8: Rfb1.1, Rfb2.2, U1.3
9: M1.1, M1.2, M1.3, Rramp.2, Rsense.1
10: Csep.2, Lin.1, M1.5, M1.6, M1.7, M1.8, M1.9
12: Cramp.1, Rramp.1, U1.1
13: Ccomp.1, Rcomp.2
20: M1.4, U1.6
21: Rfadj.2, U1.7

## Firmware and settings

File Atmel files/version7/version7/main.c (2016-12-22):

/*
 * LCD_ILI9341_ese323.c
 *
 * Created: 11/26/2016 9:32:15 PM
 *  Author: radrajith
 */ 



#include <avr/io.h>
#include <util/delay.h>
#include <stdio.h>
#include <stdbool.h>
#include <inttypes.h>
#include <avr/pgmspace.h>
#include <limits.h>
//#include "C:/Users/radra/Box Sync/Senior Fall 2016/ESE 323/Atmel files/LCD_ILI9341_ese323/LCD_ILI9341_ese323/ili9341.h"

#define POINTER ILI9341_RED
//#define F_CPU	16000000UL
unsigned int TFTWIDTH = 240;
unsigned int TFTHEIGHT = 320;
#define SPIPORT PORTC_OUT
#define SPIPORT1 PORTC_OUTCLR
#define SPIDDR PORTC_DIR
#define SPIPIN PORTC_IN
#define RESET 2
#define DC 3			// data or command 
#define CS 4			//(remember cs is actually !CS active low)
#define SCK 5
#define MISO 6
#define MOSI 7
//#define F_CPU  32000000UL;
//color address taken from adafruit
#define ILI9341_ALICEBLUE 0xF7DF
#define ILI9341_ANTIQUEWHITE 0xFF5A
#define ILI9341_AQUA 0x07FF
#define ILI9341_AQUAMARINE 0x7FFA
#define ILI9341_AZURE 0xF7FF
#define ILI9341_BEIGE 0xF7BB
#define ILI9341_BISQUE 0xFF38
#define ILI9341_BLACK 0x0000
#define ILI9341_BLANCHEDALMOND 0xFF59
#define ILI9341_BLUE 0x001F
#define ILI9341_BLUEVIOLET 0x895C
#define ILI9341_BROWN 0xA145
#define ILI9341_BURLYWOOD 0xDDD0
#define ILI9341_CADETBLUE 0x5CF4
#define ILI9341_CHARTREUSE 0x7FE0
#define ILI9341_CHOCOLATE 0xD343
#define ILI9341_CORAL 0xFBEA
#define ILI9341_CORNFLOWERBLUE 0x64BD
#define ILI9341_CORNSILK 0xFFDB
#define ILI9341_CRIMSON 0xD8A7
#define ILI9341_CYAN 0x07FF
#define ILI9341_DARKBLUE 0x0011
#define ILI9341_DARKCYAN 0x0451
#define ILI9341_DARKGOLDENROD 0xBC21
#define ILI9341_DARKGRAY 0xAD55
#define ILI9341_DARKGREEN 0x0320
#define ILI9341_DARKKHAKI 0xBDAD
#define ILI9341_DARKMAGENTA 0x8811
#define ILI9341_DARKOLIVEGREEN 0x5345
#define ILI9341_DARKORANGE 0xFC60
#define ILI9341_DARKORCHID 0x9999
#define ILI9341_DARKRED 0x8800
#define ILI9341_DARKSALMON 0xECAF
#define ILI9341_DARKSEAGREEN 0x8DF1
#define ILI9341_DARKSLATEBLUE 0x49F1
#define ILI9341_DARKSLATEGRAY 0x2A69
#define ILI9341_DARKTURQUOISE 0x067A
#define ILI9341_DARKVIOLET 0x901A
#define ILI9341_DEEPPINK 0xF8B2
#define ILI9341_DEEPSKYBLUE 0x05FF
#define ILI9341_DIMGRAY 0x6B4D
#define ILI9341_DODGERBLUE 0x1C9F
#define ILI9341_FIREBRICK 0xB104
#define ILI9341_FLORALWHITE 0xFFDE
#define ILI9341_FORESTGREEN 0x2444
#define ILI9341_FUCHSIA 0xF81F
#define ILI9341_GAINSBORO 0xDEFB
#define ILI9341_GHOSTWHITE 0xFFDF
#define ILI9341_GOLD 0xFEA0
#define ILI9341_GOLDENROD 0xDD24
#define ILI9341_GRAY 0x8410
#define ILI9341_GREEN 0x0400
#define ILI9341_GREENYELLOW 0xAFE5
#define ILI9341_HONEYDEW 0xF7FE
#define ILI9341_HOTPINK 0xFB56
#define ILI9341_INDIANRED 0xCAEB
#define ILI9341_INDIGO 0x4810
#define ILI9341_IVORY 0xFFFE
#define ILI9341_KHAKI 0xF731
#define ILI9341_LAVENDER 0xE73F
#define ILI9341_LAVENDERBLUSH 0xFF9E
#define ILI9341_LAWNGREEN 0x7FE0
#define ILI9341_LEMONCHIFFON 0xFFD9
#define ILI9341_LIGHTBLUE 0xAEDC
#define ILI9341_LIGHTCORAL 0xF410
#define ILI9341_LIGHTCYAN 0xE7FF
#define ILI9341_LIGHTGOLDENRODYELLOW 0xFFDA
#define ILI9341_LIGHTGREEN 0x9772
#define ILI9341_LIGHTGREY 0xD69A
#define ILI9341_LIGHTPINK 0xFDB8
#define ILI9341_LIGHTSALMON 0xFD0F
#define ILI9341_LIGHTSEAGREEN 0x2595
#define ILI9341_LIGHTSKYBLUE 0x867F
#define ILI9341_LIGHTSLATEGRAY 0x7453
#define ILI9341_LIGHTSTEELBLUE 0xB63B
#define ILI9341_LIGHTYELLOW 0xFFFC
#define ILI9341_LIME 0x07E0
#define ILI9341_LIMEGREEN 0x3666
#define ILI9341_LINEN 0xFF9C
#define ILI9341_MAGENTA 0xF81F
#define ILI9341_MAROON 0x8000
#define ILI9341_MEDIUMAQUAMARINE 0x6675
#define ILI9341_MEDIUMBLUE 0x0019
#define ILI9341_MEDIUMORCHID 0xBABA
#define ILI9341_MEDIUMPURPLE 0x939B
#define ILI9341_MEDIUMSEAGREEN 0x3D8E
#define ILI9341_MEDIUMSLATEBLUE 0x7B5D
#define ILI9341_MEDIUMSPRINGGREEN 0x07D3
#define ILI9341_MEDIUMTURQUOISE 0x4E99
#define ILI9341_MEDIUMVIOLETRED 0xC0B0
#define ILI9341_MIDNIGHTBLUE 0x18CE
#define ILI9341_MINTCREAM 0xF7FF
#define ILI9341_MISTYROSE 0xFF3C
#define ILI9341_MOCCASIN 0xFF36
#define ILI9341_NAVAJOWHITE 0xFEF5
#define ILI9341_NAVY 0x0010
#define ILI9341_OLDLACE 0xFFBC
#define ILI9341_OLIVE 0x8400
#define ILI9341_OLIVEDRAB 0x6C64
#define ILI9341_ORANGE 0xFD20
#define ILI9341_ORANGERED 0xFA20
#define ILI9341_ORCHID 0xDB9A
#define ILI9341_PALEGOLDENROD 0xEF55
#define ILI9341_PALEGREEN 0x9FD3
#define ILI9341_PALETURQUOISE 0xAF7D
#define ILI9341_PALEVIOLETRED 0xDB92
#define ILI9341_PAPAYAWHIP 0xFF7A
#define ILI9341_PEACHPUFF 0xFED7
#define ILI9341_PERU 0xCC27
#define ILI9341_PINK 0xFE19
#define ILI9341_PLUM 0xDD1B
#define ILI9341_POWDERBLUE 0xB71C
#define ILI9341_PURPLE 0x8010
#define ILI9341_RED 0xF800
#define ILI9341_ROSYBROWN 0xBC71
#define ILI9341_ROYALBLUE 0x435C
#define ILI9341_SADDLEBROWN 0x8A22
#define ILI9341_SALMON 0xFC0E
#define ILI9341_SANDYBROWN 0xF52C
#define ILI9341_SEAGREEN 0x2C4A
#define ILI9341_SEASHELL 0xFFBD
#define ILI9341_SIENNA 0xA285
#define ILI9341_SILVER 0xC618
#define ILI9341_SKYBLUE 0x867D
#define ILI9341_SLATEBLUE 0x6AD9
#define ILI9341_SLATEGRAY 0x7412
#define ILI9341_SNOW 0xFFDF
#define ILI9341_SPRINGGREEN 0x07EF
#define ILI9341_STEELBLUE 0x4416
#define ILI9341_TAN 0xD5B1
#define ILI9341_TEAL 0x0410
#define ILI9341_THISTLE 0xDDFB
#define ILI9341_TOMATO 0xFB08
#define ILI9341_TURQUOISE 0x471A
#define ILI9341_VIOLET 0xEC1D
#define ILI9341_WHEAT 0xF6F6
#define ILI9341_WHITE 0xFFFF
#define ILI9341_WHITESMOKE 0xF7BE
#define ILI9341_YELLOW 0xFFE0
#define ILI9341_YELLOWGREEN 0x9E66

void spi_init_hardware(){
	SPIDDR |= (1<<DC)|(1<<RESET);		//set DC and RESET to output
	SPIPORT |= (1<<RESET);	//		//output high on RESET
	
}
void spi_init(){
	SPIDDR |= (1<<CS)|(1<<MOSI)|(1<<SCK);		//set cs, mosi, sck as output
	SPIC_CTRL |= (1<<SPI_ENABLE_bp)|(1<<SPI_MASTER_bp);		//enable the SPI and set it as master. (confirm wheater it should be _bm or _bp
	SPIC_CTRL |= (1<<SPI_CLK2X_bp);						//double the spi speed
	//SPIC_CTRL |= (1<<SPI_PRESCALER0_bp);//|(1<<SPI_PRESCALER0_bm); 
	SPIPORT |= (1<<CS);						
}

void spi_send(uint8_t data){					
	SPIC_DATA = data;	//write to data register
	//_delay_ms(5);
	while(!(SPIC_STATUS & (1<<SPI_IF_bp))){}	//wait until the flag is set making data 
}
void spi_writeCommand(uint8_t command){
	SPIPORT &= ~((1<<DC)|(1<<CS));		//dc and cs both set as low to send 
	_delay_us(5);						//delay 5us
	spi_send(command);
	SPIPORT |= (1<<CS);					//cs is set high
}
void spi_writeData(uint8_t data){
	SPIPORT |= (1<<DC);					//dc set high for data
	_delay_us(1);
	SPIPORT &= ~(1<<CS);				//CS set high for 
	spi_send(data);
	SPIPORT |= (1<<CS);
}
void setAddress(uint16_t x1, uint16_t y1, uint16_t x2, uint16_t y2){
	spi_writeCommand(0x2A);
	spi_writeData(x1>>8);
	spi_writeData(x1);
	spi_writeData(x2>>8);
	spi_writeData(x2);

	spi_writeCommand(0x2B);
	spi_writeData(y1>>8);
	spi_writeData(y1);
	spi_writeData(y2>>8);
	spi_writeData(y2);

	spi_writeCommand(0x2C);
}
void reset(){
	SPIPORT |= (1<<RESET);		//pull RESET high
	_delay_ms(200);
	SPIPORT &= ~(1<<RESET);		//pull RESET low to reset
	_delay_ms(200);
	SPIPORT |= (1<<RESET);		//pull RESET high
	_delay_ms(200);
}
//void clear();
void begin(){
	spi_init_hardware();
	spi_init();
	reset();
	spi_writeCommand(0x01);		//software reset
	_delay_ms(1000);
	//clear(ILI9341_YELLOW);
	//power control A
	spi_writeCommand(0xCB);
	spi_writeData(0x39);
	spi_writeData(0x2C);
	spi_writeData(0x00);
	spi_writeData(0x34);
	spi_writeData(0x02);

	//power control B
	spi_writeCommand(0xCF);
	spi_writeData(0x00);
	spi_writeData(0xC1);
	spi_writeData(0x30);

	//driver timing control A
	spi_writeCommand(0xE8);
	spi_writeData(0x85);
	spi_writeData(0x00);
	spi_writeData(0x78);

	//driver timing control B
	spi_writeCommand(0xEA);
	spi_writeData(0x00);
	spi_writeData(0x00);

	//power on sequence control
	spi_writeCommand(0xED);
	spi_writeData(0x64);
	spi_writeData(0x03);
	spi_writeData(0x12);
	spi_writeData(0x81);

	//pump ratio control
	spi_writeCommand(0xF7);
	spi_writeData(0x20);

	//power control,VRH[5:0]
	spi_writeCommand(0xC0);
	spi_writeData(0x23);

	//Power control,SAP[2:0];BT[3:0]
	spi_writeCommand(0xC1);
	spi_writeData(0x10);

	//vcm control
	spi_writeCommand(0xC5);
	spi_writeData(0x3E);
	spi_writeData(0x28);

	//vcm control 2
	spi_writeCommand(0xC7);
	spi_writeData(0x86);

	//memory access control
	spi_writeCommand(0x36);
	spi_writeData(0x48);

	//pixel format
	spi_writeCommand(0x3A);
	spi_writeData(0x55);

	//frameration control,normal mode full colours
	spi_writeCommand(0xB1);
	spi_writeData(0x00);
	spi_writeData(0x18);

	//display function control
	spi_writeCommand(0xB6);
	spi_writeData(0x08);
	spi_writeData(0x82);
	spi_writeData(0x27);

	//3gamma function disable
	spi_writeCommand(0xF2);
	spi_writeData(0x00);

	//gamma curve selected
	spi_writeCommand(0x26);
	spi_writeData(0x01);

	//set positive gamma correction
	spi_writeCommand(0xE0);
	spi_writeData(0x0F);
	spi_writeData(0x31);
	spi_writeData(0x2B);
	spi_writeData(0x0C);
	spi_writeData(0x0E);
	spi_writeData(0x08);
	spi_writeData(0x4E);
	spi_writeData(0xF1);
	spi_writeData(0x37);
	spi_writeData(0x07);
	spi_writeData(0x10);
	spi_writeData(0x03);
	spi_writeData(0x0E);
	spi_writeData(0x09);
	spi_writeData(0x00);

	//set negative gamma correction
	spi_writeCommand(0xE1);
	spi_writeData(0x00);
	spi_writeData(0x0E);
	spi_writeData(0x14);
	spi_writeData(0x03);
	spi_writeData(0x11);
	spi_writeData(0x07);
	spi_writeData(0x31);
	spi_writeData(0xC1);
	spi_writeData(0x48);
	spi_writeData(0x08);
	spi_writeData(0x0F);
	spi_writeData(0x0C);
	spi_writeData(0x31);
	spi_writeData(0x36);
	spi_writeData(0x0F);

	//exit sleep
	spi_writeCommand(0x11);
	_delay_ms(120);
	//display on
	spi_writeCommand(0x29);

}

void pushColor(uint16_t color){
	spi_writeData(color>>8);			//sending first 8 msb by bitwise shifting to the right by 8
	spi_writeData(color);			//sending the 8
}
void clear(uint16_t color){
	uint16_t i,j;
	setAddress(0,0,TFTWIDTH-1,TFTHEIGHT-1);

	for(i=0;i<TFTWIDTH;i++)
	{
		for(j=0;j<TFTHEIGHT;j++)
		{
			pushColor(color);
		}
	}

}
void drawPixel(uint16_t x1, uint16_t y1, uint16_t color){
	if((x1 < 0) ||(x1 >=TFTWIDTH) || (y1 < 0) || (y1 >=TFTHEIGHT)) {
		return;
	}
	setAddress(x1,y1,x1+1,y1+1);

	pushColor(color);
}

//vertical line
void drawVLine(uint16_t x, uint16_t y, uint16_t h, uint16_t color){
	if((x >=TFTWIDTH) || (y >=TFTHEIGHT)) return;
	if((y+h-1)>=TFTHEIGHT)
	h=TFTHEIGHT-y;
	setAddress(x,y,x,y+h-1);
	while(h--)
	{
		pushColor(color);
	}
}
//horizontal line
void drawHLine(uint16_t x, uint16_t y, uint16_t w, uint16_t color){
	if((x >=TFTWIDTH) || (y >=TFTHEIGHT)) {
		return;
	}
	if((x+w-1)>=TFTWIDTH)
	w=TFTWIDTH-x;
	setAddress(x,y,x+w-1,y);
	while(w--)
	{
		pushColor(color);
	}
}
void fillrect(uint16_t x, uint16_t y, uint16_t w, uint16_t h, uint16_t color){
	if((x >=TFTWIDTH) || (y >=TFTHEIGHT)){
		return;
	}
	if((x+w-1)>=TFTWIDTH)
	w=TFTWIDTH-x;
	if((y+h-1)>=TFTHEIGHT)
	h=TFTHEIGHT-y;

	setAddress(x, y, x+w-1, y+h-1);

	for(y=h; y>0; y--)
	{
		for(x=w; x>0; x--)
		{
			pushColor(color);
		}
	}
}
void fillScreen(uint16_t color){
	clear(color);
}

void setRotation(uint8_t x){
	uint8_t rotation;
	spi_writeCommand(0x36);
	rotation=x%4;
	switch (rotation)
	{
		case 0:
		spi_writeCommand(0x40|0x08);
		TFTWIDTH = 240;
		TFTHEIGHT = 320;
		break;
		case 1:
		spi_writeCommand(0x20|0x08);
		TFTWIDTH  = 320;
		TFTHEIGHT = 240;
		break;
		case 2:
		spi_writeCommand(0x80|0x08);
		TFTWIDTH  = 240;
		TFTHEIGHT = 320;
		break;
		case 3:
		spi_writeCommand(0x40|0x80|0x20|0x08);
		TFTWIDTH  = 320;
		TFTHEIGHT = 240;
		break;
	}
}



int main(void)
{
	begin();					//initialize driver
	clear(ILI9341_RED);		//clear the 
	setRotation(2);				//change this between 0 and 3 depending on the orientation of the 
    while(1)
    {
	//_delay_ms(1000);
        //TODO:://write to data register Please write your application code 
		clear(ILI9341_GREENYELLOW);
		//_delay_ms(100);
		clear(ILI9341_BLUE);
		clear(ILI9341_YELLOW);
		clear(ILI9341_SILVER);
		//_delay_ms(100);
    }
}

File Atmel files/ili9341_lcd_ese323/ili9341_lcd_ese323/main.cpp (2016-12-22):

/*
 * ili9341_lcd_ese323.cpp
 *
 * Created: 11/26/2016 8:08:56 PM
 *  Author: radrajith
 */ 


#include <avr/io.h>
#include <util/delay.h>
#include <stdio.h>
#include <stdbool.h>
#include <inttypes.h>
#include "C:\Users\radra\Box Sync\Senior Fall 2016\ESE 323\Atmel files\ili9341_lcd_ese323\ili9341_lcd_ese323\ili9341.h"

#define POINTER ILI9341_RED
int main(void)
{
	//F_CPU |= 32000000;
	begin();					//initialize driver
	clear(ILI9341_BLACK);		//clear the screen
	_delay_ms(1000);
	setRotation(3);				//change this between 0 and 3 depending on the orinetation of the screen
	
    while(1)
    {
        //TODO:: Please write your application code 
		fillScreen(ILI9341_RED);
		_delay_ms(1000);
		fillScreen(ILI9341_BLUE);
		_delay_ms(1000);
		
    }
}

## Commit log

2016-10-09 uploading all files
    uploading all the work done until 10/08/16
    [2016-10-08_15-02-32.sch, 2016-10-08_15-02-54.brd, BuildIt_BOM_4652240_3.xls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]
2016-10-09 uploading eagle files
    [2016-10-08_15-02-32.sch, 2016-10-08_15-02-54.brd, BuildIt_BOM_4652240_3.xls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]
2016-10-09 uploading parts list as csv
    [parts lists.csv]
2016-10-09 added html compatible BOM file. removed the csv file
    [parts lists.csv]
2016-10-10 making the csv file to make the github website
    [parts lists.csv]
2016-10-10 adding pictures of connectors
2016-10-11 changed the swtiching power supply and added pics
    [2016-10-10_13-47-58.sch, 2016-10-10_13-48-17.brd, BuildIt_BOM_4652240_4.xls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]
2016-10-11 uploading docs
    [parts lists.csv]
2016-10-12 Modified 14 pin header to include screw hole layout for lcd
    [Final Project Designs.brd, Final Project Designs.sch]
2016-10-13 added more files and datasheets
    [gain calculation.xlsx]
2016-10-13 add more pics
    [parts lists.csv]
2016-10-14 added pictures
    [parts lists.csv]
2016-10-15 building the schematic
    [2016-10-14_05-17-29.sch, 2016-10-14_05-18-27.brd, 2016-10-14_05-18-27.sch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]
2016-10-15 some datasheets and board modifications
    [Final Project Designs_v1.brd, Final Project Designs_v1.sch, test.brd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]
2016-10-17 spreadsheet for the sps
    [BOM_4652240_16.xls]
2016-10-18 updated designs
    [2016-10-14_05-18-27.sch, Final Project Designs_v1.sch, test.brd]
2016-10-20 updated designs, downloaded some datasheets, modified the BOM
    [2016-10-14_05-17-29.sch, Final Project Designs_v1.brd, Final Project Designs_v1_copy.sch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]
2016-10-21 finished the schematic and board designs
    [2016-10-14_05-18-27.sch, Final Project Designs_v1.brd, Final Project Designs_v1.sch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]
2016-10-21 few more changes
    [parts lists.csv]
2016-10-22 added some files
    [Final Project Designs_v1.brd, Final Project Designs_v1.sch]
2016-10-23 added few more files
    [Final Project Designs_v1.brd, Final Project Designs_v1.sch, Final Project Designs_v1_copy.brd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]
2016-10-24 update design and files
    [Final Project Designs_v1.brd, parts lists.csv]
2016-10-28 finished everthing
    [Final Project Designs_v1.GBL, Final Project Designs_v1.GBO, Final Project Designs_v1.GBP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]
2016-10-29 added DRU and Cam files
    [lab 04.0001.ipt, lab 04.0002.ipt, lab 04.ipt]
2016-11-06 added cad drawings and pictures
    [Final Project Designs_v1.dxf, assembly.0005.iam, assembly.iam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]
2016-11-06 pics on cad
2016-11-08 added pics
    [assembly.0005.iam, assembly.0006.iam, assembly.iam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]
2016-12-22 code changes
    [2016-10-10_13-47-58.sch, 2016-10-10_13-48-17.brd, BuildIt_BOM_4652240_4.xls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]

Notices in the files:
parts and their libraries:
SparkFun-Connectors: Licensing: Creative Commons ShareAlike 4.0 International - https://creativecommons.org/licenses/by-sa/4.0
